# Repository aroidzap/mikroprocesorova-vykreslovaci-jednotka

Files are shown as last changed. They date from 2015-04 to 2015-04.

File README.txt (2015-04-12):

Copyright (c) 2015 Tomáš Pazdiora

Documents, images, code, schematics and boards.

Documents, images, all schematic (.sch) and board (.brd) files are licenced under CC-BY 4.0 (http://creativecommons.org/licenses/by/4.0/legalcode)
All source code is licensed under MIT license. See the file "LICENSE.txt" for full license text.

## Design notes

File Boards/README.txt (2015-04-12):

You can view and export boards using CadSoft's EAGLE Light Edition. (available from: http://www.cadsoftusa.com/download-eagle/freeware/)

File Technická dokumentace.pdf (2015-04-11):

## Technická dokumentace Mikroprocesorová vykreslovací jednotka

2015 | Tomáš Pazdiora

### OBSAH

### 1. HARDWAROVÁ SPECIFIKACE

### 1.1. VSTUPY A VÝSTUPY

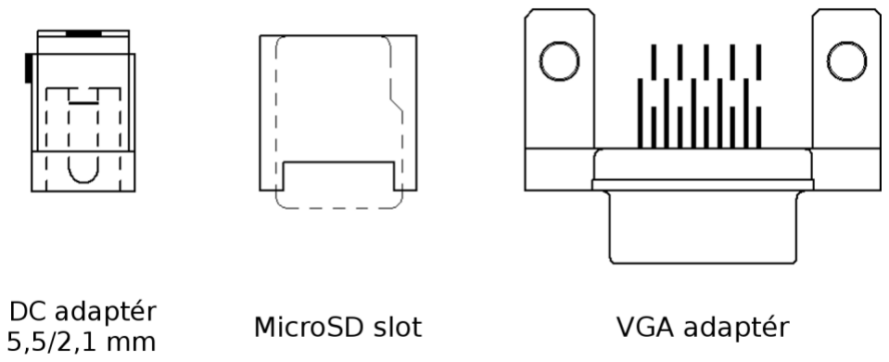
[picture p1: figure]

Obr. 1 – 1: Vstupy a výstupy

### 1.2. ELEKTRICKÉ VLASTNOSTI

Základní parametry

Vstupní napájení | 12 V DC
Maximální spotřeba | 1 W
Typická spotřeba | 0,75 W

Tab. 1 – 1: Základní elektrické parametry

Detailní parametry
Část zařízení | Napájení | Typický proud
ATtiny4313 | 5,0 V | 16 mA
ATmega32 | 5,0 V | 26 mA
RAM modul | 5,0 V | 18 mA
DAC | 5,0 V | 10 mA
SD karta | 3,3 V | 15 mA
| Napájení | Efektivita
Regulátor | 12 V DC | >75 %

Tab. 1 – 2: Detailní elektrické parametry

### 1.3. MIKROPROCESORY

Použité mikroprocesory jsou od firmy Atmel, mají 8bitové jádro AVR, jsou programovatelné skrz rozhraní SPI nebo paralelně.

Jako zobrazovací mikroprocesor je použit mikroprocesor ATtiny4313. Pracuje na frekvenci 20 MHz při napájecím napětí 5 V. Kód zabírá 97.9 % paměti flash. Pokud by bylo potřeba uvolnit místo, je doporučeno odstranit podporu kopírování z jedné paměti do druhé (kód hledejte pod návěštím „copy“).

Vykreslovacím mikroprocesorem je mikroprocesor ATmega32. Pracuje na frekvenci 16MHz při napájecím napětí 5 V. Velikost kódu je závislá na použitých knihovnách.

V následující tabulce jsou vypsána nastavení pojistek obou mikroprocesorů.

Nastavení pojistek

Typ pojistky | ATtiny4313 | ATmega32
Low | 0xFF | 0x3F
High | 0xD9 | 0xD9
Extended | 0xFF | ---

Tab. 1 – 3: Nastavení pojistek mikroprocesorů

### 2. INTERPRETER

Toto zařízení má základní podporu interpretace jednoduchých příkazů. Interpreter načítá příkazy ze souboru „main.txt“ (platí pouze pro aktuální program nahraný v mikroprocesoru). Soubor, ze kterého se načítají příkazy, je zvolen při volání funkce „load_commands“ (tato funkce je obsažena v knihovně „cmd_parser.h“).

Interpreter aktuálně podporuje 14 příkazů. Další příkazy mohou být implementovány úpravou funkce „process_command“ v knihovně „cmd_parser.h“ vykreslovacího mikroprocesoru.

Syntax vychází ze zápisu volání funkcí v jazyce C. Jsou podporovány jednořádkové a víceřádkové komentáře. Syntax vypadá následovně:

// Jednořádkový komentář

/* Víceřádkový komentář
Víceřádkový komentář
Víceřádkový komentář */

// příkaz (argument1, argument2, ... );

// následují příklady zápisu příkazů

bmp_config(0);
clear_color(0,0,0);
draw_bmp ("images/22.bmp"); repeat();

### 2.1. INTERPRETOVANÉ PŘÍKAZY

draw_bmp(file_path);

Vykreslení BMP obrázku.

- file_path – cesta k obrázku včetně uvozovek (např. "slozka/obrazek.bmp")

draw_bmp_from_folder(folder);

Vykreslení jakéhokoliv bmp obrázku z dané složky.

- folder – cesta k dané složce včetně uvozovek (např. "slozka/podslozka")

draw_pal(swap,copy);

Vykreslení palety.

- swap – prohození vykreslovací a zobrazovací paměti po dokončení vykreslování (0 nebo 1)
- copy – postupné vykreslování (0 nebo 1)

draw_hsv_pal(swap,copy);

Vykreslení HSV palety.

- swap – prohození vykreslovací a zobrazovací paměti po dokončení vykreslování (0 nebo 1)
- copy – postupné vykreslování (0 nebo 1)

draw_test(test_number,swap,copy);

Vykreslení funkcí z „draw_test.h“.

- číslo vykreslovací funkce (0 až 3)
- swap – prohození vykreslovací a zobrazovací paměti po dokončení vykreslování (0 nebo 1)
- copy – postupné vykreslování (0 nebo 1)

clear_color(r,g,b);

Vykreslení jedné barvy přes celou obrazovku.

- r – červená složka (0 až 255)
- g – zelená složka (0 až 255)
- b – modrá složka (0 až 255)

delay(seconds);

Pozastavení na daný počet sekund.

bmp_config(enable_scaling);

Je-li nastaveno na „1“, povoluje se škálování bitmapy – dělí se šířka obrázku dvěma. Tímto se částečně kompenzuje nesprávná šířka pixelu zobrazovací jednotky. Pokud je šířka bitmapy upravena předem, nastavujeme na „0“.

processing_config(enable_dithering);

Povolení ditheringu. (0 nebo 1)

set_color_mode(mode);

Nastavení barevného režimu. (RGB nebo BW, bez uvozovek)

swap_buffers();

Prohození vykreslovací a zobrazovací paměti.

copy_buffers(direction);

Kopírování z jedné paměti do druhé.

„direction“ (směr):

- 1 – z vykreslovací paměti do zobrazovací
- 0 – ze zobrazovací paměti do vykreslovací

repeat_from_here();

Označení pozice, odkud se má kód opakovat při zavolání funkce „repeat“.

repeat();

Opakovat.

### 3. KNIHOVNY VYKRESLOVACÍHO

### MIKROPROCESORU

Některé knihovny obsahují globální proměnné pro své vnitřní výpočty. Většina těchto proměnných tu není uvedena.

## 3.1. BMP.h

unsigned char bmp_2to1_scaling;

Je-li nastaveno na „1“, povoluje se škálování bitmapy – dělí se šířka obrázku dvěma. Tímto se částečně kompenzuje nesprávná šířka pixelu zobrazovací jednotky. Pokud je šířka bitmapy upravena předem, nastavujeme bmp_2to1_scaling na „0“.

int BMP_decode_start();

Dekóduje hlavičku bitmapy. Podporuje pouze bitmapy s 24bitovou barevnou hloubkou a pouze bitmapy se standardní hlavičkou. Pokud navrací „1“, jde o nepodporovanou bitmapu, je-li vše v pořádku, navrací „0“.

vec3 BMP_next_pixel();

Navrací další pixel.

void BMP_next_y();

Posouvá se na další Y souřadnici. Souřadnice jsou čteny zespod obrázku nahoru. (adresy od „výška - 1“ do „0“)

void BMP_center_y(int input_y);

Centrování bitmapy. Volá se před vykreslením pixelu, jednou na každé lince.

void BMP_center_x(int input_x);

Centrování bitmapy. Volá se před vykreslením pixelu.

void BMP_render(unsigned long starting_cluster);

Vykreslení bitmapy.

- starting_cluster – cluster BMP souboru, který chceme vykreslit.

## 3.2. cmd_parser.h

void process_command(char *cmd, char *arg);

Zpracuje příkaz.

- cmd – příkaz (string)
- arg – argument (string)

void load_commands(char *file_path);

Načítá soubor s příkazy určenými k interpretaci.

- file_path – cesta k souboru (např. „slozka/soubor.txt“)

unsigned char cmd_compare(char* cmd, char* text);

Porovnává příkaz (string) s textem.

- cmd – příkaz (string)
- text – text (string)

int get_argument_i(char *arg, unsigned char arg_number);

Vytahuje z argumentu (string) argument s číslem „arg_number“ a navrací jej.

- arg – argument (string)
- arg_number – číslo požadovaného argumentu

void get_argument_str(char *arg);

Vytahuje string z argumentu (string) a navrací jej zpět do argumentu.

- arg – argument (string)

void get_argument_enum(char *arg);

Vytahuje enum z argumentu (string) a navrací jej zpět do argumentu.

- arg – argument (string)

## 3.3. color_process.h

unsigned char dither_enable;

Povolení ditheringu (0, 1).

PROGMEM unsigned const char threshold_matrix3b[4][4];

Prahová mapa 4x4 pro ordered dithering, pronásobená velikostí kvantizační hladiny o velikosti 32.

PROGMEM unsigned const char threshold_matrix2b[4][4];

Prahová mapa 4x4 pro ordered dithering, pronásobená velikostí kvantizační hladiny o velikosti 64.

vec3 dither_rgb(vec3 pixel, int x, int y);

Převede pomocí ordered ditheringu pixel s 24bitovou hloubkou na pixel s 8bitovou hloubkou (kompatibilní s formátem BBGGGRRR).

vec3 rgb_to_bw(vec3 pixel24b);

Pomocí funkce relativního jasu převede barevný pixel na černobílý.

unsigned char rgb_to_bw_value(vec3 pixel24b);

Pomocí funkce relativního jasu převede barevný pixel s 24bitovou hloubkou na hodnotu o 256 odstínech šedi.

vec3 truncate_rgb(vec3 pixel);

Oseká pixel s 24bitovou hloubkou na pixel s 8bitovou hloubkou (kompatibilní s formátem BBGGGRRR).

unsigned char compose_rgb8(vec3 pixel);

Navrací formát BBGGGRRR.

- pixel – pixel s 8bitovou hloubkou (kompatibilní s formátem BBGGGRRR)

unsigned char compose_rgb24(vec3 pixel);

Oseká pixel s 24bitovou hloubkou na pixel s 8bitovou hloubkou (kompatibilní s formátem BBGGGRRR) a navrací formát BBGGGRRR.

- pixel - pixel s 24bitovou hloubkou vec3 decompose_rgb8(unsigned char bbgggrrr);

Rozložení formátu BBGGGRRR na tři složky.

- bbgggrrr – vstupní hodnota formátu BBGGGRRR

## 3.4. commands.h

Obsahuje seznam příkazů pro funkci „driver_command“, která je deklarovaná v knihovně „UART.h“.

### 3.4.1. Žádosti

COPY_REQUEST_CMD(n)

Kopírování n-té čtveřice linek. „n“ je v rozmezí od 0 do 119.

VIDEO_DISABLE

Zakázání zobrazování obrazu.

VIDEO_ENABLE

Povolení zobrazování obrazu.

SWAP_STATE_CMD(state)

Prohodit paměti do konkrétního stavu. „state“ je buď „0“ nebo „1“.

COPY_DIR_CMD(dir)

Směr kopírování. „dir“ může být copy_to_video (kopírování z vykreslovací paměti do zobrazovací) nebo copy_to_data (kopírování ze zobrazovací paměti do vykreslovací).

SWAP_REQUEST_CMD

Prohození pamětí.

DRIVER_READY_REQ_CMD

Zjišťuje, je-li zobrazovací mikroprocesor připraven.

### 3.4.2. Odpovědi

DRIVER_DONE_CMD

Příkaz byl dokončen v pořádku.

DRIVER_READY_RESP_CMD

Zobrazovací mikroprocesor je připraven.

DRIVER_TRANSMIT_ERROR

Chyba v přenosu.

DRIVER_ILLEGAL_CMD

Nepodporovaný příkaz.

## 3.5. draw_test.h

unsigned char draw0(int input_x,int input_y);

Vykreslovací funkce „srdce“.

unsigned char draw1(int input_x,int input_y);

Vykreslovací funkce „základní fraktál“.

unsigned char draw2(int input_x,int input_y);

Vykreslovací funkce.

unsigned char draw3(int input_x,int input_y);

Vykreslovací funkce.

## 3.6. drawing.h

unsigned long time;

Tato hodnota je určená pro vlastní výpočty. Při startu programu je inicializována na „0“. Funkce „render“ navyšuje tuto hodnotu o 1.

void clear_color(unsigned char color, unsigned char swap);

Vykreslení jedné barvy do paměti.

- color – barva ve formátu BBGGGRRR
- swap – prohození bufferů po dokončení vykreslování barvy (0, 1)

void render_loading_bar(unsigned int input_y);

Vykreslení loading baru.

- input_y – aktuální adresa y

void render( unsigned char (*compute_pixel)(int,int), unsigned char swap,
unsigned char copy );
- (*compute_pixel)(int,int) – vstupní vykreslovací funkce (např. draw_pal)
- swap – prohození bufferů po dokončení vykreslování barvy (0, 1)
- copy – postupné vykreslování

unsigned char draw_pal(int input_x,int input_y);

Vykreslovací funkce pro vykreslení palety.

unsigned char draw_hsv_pal(int input_x,int input_y);

Vykreslovací funkce pro vykreslení HSV palety.

void delay(unsigned int seconds);

Pozastavení programu.

- seconds – doba pozastavení v sekundách

## 3.7. FAT.h

void FAT_init();

Inicializace FATu.

unsigned long cluster_to_lba(unsigned long cluster);

Převádí cluster na adresu LBA a tu navrací.

int FAT_get_new_cluster();

Posune čtení se na následující cluster. Pokud je aktuální cluster poslední v řetězci clusterů, navrací „1“, jinak „0“.

void FAT_read_start(unsigned long cluster);

Započne čtení na daném clusteru.

unsigned char FAT_read_next();

Navrací další 8bitové nezáporné celé číslo.

unsigned int FAT_next_ui();

Navrací další 16bitové nezáporné celé číslo.

unsigned long FAT_next_ul();

Navrací další 32bitové nezáporné celé číslo.

void FAT_read_skip(int bytes_to_skip);

Přeskočení několika bytů.

- bytes_to_skip – počet bytů k přeskočení

unsigned long FAT_find_entry_cluster( char *name ,
unsigned char is_directory);

Navrací cluster hledaného souborového zápisu. Není-li zápis nalezen, vrací „0“.

- name – jméno hledaného souborového zápisu (např. „soubor.txt“)
- is_directory – jedná se o složku (1, 0)

void FAT_open_directory( char *directory_path, unsigned char name_is_file_path );

Otevírá složku.

- directory_path – cesta ke složce (např. „slozka/podslozka1/podslozka2“)
- name_is_file_path – cesta ke složce obsahuje na konci zápisu soubor (1, 0)

unsigned long FAT_find_file_cluster(char *file_path);

Navrací cluster hledaného souboru.

- file_path – cesta k souboru (např. „slozka/podslozka/soubor.txt“)

unsigned long FAT_file_by_extension_cluster(
char* directory_name, char *extension);

Otevírá soubor s danou příponou (přípona není citlivá na velikost písmen). Při vícenásobném volání otevírá soubory postupně za sebou.

- directory_name – cesta ke složce (např. „slozka/podslozka1/podslozka2“)
- extension – přípona souborů (pouze třímístné, např. „bmp“, „txt“)

## 3.8. RAM.h

unsigned char const PROGMEM translate_x_data[33];

Konstantní data využitá pro přeložení standartního adresování „od 0 do n“ na „posloupnost rychlého sekvenčního čtení“.

void set_Y(unsigned int _value);

Nastavení adresy Y (standardní adresování „od 0 do n“).

- _value – vstupní hodnota adresy Y

void set_X(unsigned char _value);

Nastavení adresy X (standardní adresování „od 0 do n“).

- _value – vstupní hodnota adresy X

unsigned char translate_x(unsigned char x);

Přeložení adresy standardního adresování „od 0 do n“ na adresu „posloupnosti rychlého sekvenčního čtení“. Tato funkce je používána interně.

void inc_X();

Zvětšení hodnoty adresy X o 1. Tato funkce je optimalizována pro rychlost. Pokud je to možné, je doporučeno používat tuto funkci místo funkce set_X.

void reset_X();

Vynuluje adresu X. Tato funkce je optimalizována pro rychlost. Pokud je to možné, je doporučeno používat tuto funkci místo funkce set_X.

unsigned char RAM_read();

Vrací hodnotu z externí RAM, z aktuálně nastavené adresy.

void RAM_write(unsigned char data);

Zapisuje do externí RAM na aktuálně nastavenou adresu.

- data – vstupní data

## 3.9. SD.h

void SD_set_speed(unsigned char speed);

Nastavení rychlosti přenosu SD karty.

Hodnota proměnné „speed“ | Rychlost přenosu [kbps]
0 | 125
1 | 250
2 | 500
3 | 1000
4 | 2000
5 | 4000
6 | 8000

Tab. 3 – 1: Funkce „SD_set_speed“ – popis parametru „speed“

int SD_init_basic();

Základní inicializace SD karty.

int SD_init();

Inicializace SD karty. Aktuálně wrapper pro SD_init_basic.

unsigned int crc16(unsigned int old_crc, unsigned char data);

Jde o CRC-16-CCITT. Navrací novou hodnotu CRC.

- old_crc – stará hodnota CRC
- data – vstupní byte do CRC výpočtu

unsigned char crc7(unsigned char *message);

Navrací poslední byte SD příkazu (CRC posunuté o bit doleva a stop bit).

- message – SD příkaz, pro který se počítá CRC-7

void SD_command(unsigned char cmd, unsigned long arg);

Posílá SD příkaz.

- cmd – číslo příkazu
- arg - argument

unsigned char SD_command_R1(unsigned char cmd,
unsigned long arg, unsigned char expected_response);

Posílá SD příkaz a čeká na odpověď R1.

- cmd – číslo příkazu
- arg – argument
- expected_response – požadovaná odpověď

void SD_read_start(unsigned long address, unsigned long blocks);

Započne čtení.

- address – adresa, na které se má začít číst
- blocks – počet bloků, které se budou číst

void SD_read_stop();

Zastavení přenosu dat. Není nutné používat, volá se automaticky dle potřeby.

unsigned char SD_read_next();

Navrací další 8bitové nezáporné celé číslo.

unsigned int SD_next_ui();

Navrací další 16bitové nezáporné celé číslo.

unsigned long SD_next_ul();

Navrací další 32bitové nezáporné celé číslo.

void SD_read_skip(int bytes_to_skip);

Přeskočení několika bytů.

- bytes_to_skip – počet bytů k přeskočení

## 3.10.settings.h

Obsahuje softwarová a hardwarová nastavení. Jejich funkce je dle názvu zřejmá, proto zde nejsou nastavitelné parametry popsány.

void set_color_mode(unsigned char color_mode);

Nastavuje barevný režim.

- color_mode - typ barevného režimu (RGB, BW).

unsigned char get_color_mode();

Vrací aktuálně nastavený barevný režim (RGB, BW).

unsigned char informative_color();

Vrací barvu pro využití k informativním účelům (načítání, chyby, …) ve formátu BBGGGRRR. Vrácená barva závisí na nastaveném barevném režimu.

## 3.11.SPI.h

void SPI_init();

Inicializace SPI.

void SPI_set_speed(int speed);

Nastavení rychlosti SPI.

Hodnota proměnné „speed“ | Rychlost přenosu [kbps]
0 | 125
1 | 250
2 | 500
3 | 1000
4 | 2000
5 | 4000
6 | 8000

Tab. 3 – 2: Funkce „SPI_set_speed“ – popis parametru „speed“

unsigned char SPI_transfer(unsigned char data_in);

SPI přenos. Navrací příchozí data.

- data_in – data pro odeslání

## 3.12.touch_button.h

Tato knihovna není hardwarově podporována.

## 3.13.UART.h

void UART_init();

Inicializace UARTu

void driver_init();

Vyčkání na inicializaci zobrazovacího mikroprocesoru.

void driver_command(unsigned char command);

Poslání příkazu zobrazovacímu mikroprocesoru. Všechny možné příkazy jsou sepsány v souboru „commands.h“.

- command – příkaz, který se pošle

## 3.14.vecmath.h

typedef struct
{
unsigned char r;
unsigned char g;
unsigned char b;
}vec3;

Definuje typ vec3 – vektor o třech 8bitových složkách.

vec3 add(vec3 a, vec3 b);

Součet dvou vektorů „a“ a „b“.

vec3 add_value(vec3 a, unsigned char v);

Součet vektoru „a“ a hodnoty „v“.

vec3 mul_value(vec3 a, float v);

Násobení vektoru „a“ hodnotou „v“.

vec3 average(vec3 a, vec3 b);

Zprůměrování vektorů „a“ a „b“.

vec3 mix(vec3 a, vec3 b, unsigned char alpha);

Smíchání vektorů „a“ a „b“ v poměru daném hodnotou „alpha“:

Hodnota „alpha“ | Vektor „a“ | Vektor „b“
0 | 100 % | 0 %
127 | 50 % | 50 %
255 | 0 % | 100 %

Tab. 3 – 3: Funkce „mix“ – popis parametru „alpha“

unsigned char clamp(int x);

Osekání hodnoty „x“ do rozmezí od 0 do 255.

float absolute(float x);

Navrací absolutní hodnotu „x“.

### SEZNAM OBRÁZKŮ, GRAFŮ A

### TABULEK

Obr. 1 – 1: Vstupy a výstupy

Tab. 1 – 1: Základní elektrické parametry
Tab. 1 – 2: Detailní elektrické parametry
Tab. 1 – 3: Nastavení pojistek mikroprocesorů
Tab. 3 – 1: Funkce „SD_set_speed“ – popis parametru „speed“ Tab. 3 – 2: Funkce „SPI_set_speed“ – popis parametru „speed“ Tab. 3 – 3: Funkce „mix“ – popis parametru „alpha“

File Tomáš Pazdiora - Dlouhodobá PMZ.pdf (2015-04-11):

## Vyšší odborná škola a Střední průmyslová škola

elektrotechnická Olomouc,

## Božetěchova 3

## PRAKTICKÁ ZKOUŠKA Z ODBORNÝCH PŘEDMĚTŮ Mikroprocesorová vykreslovací jednotka

2015 | Tomáš Pazdiora

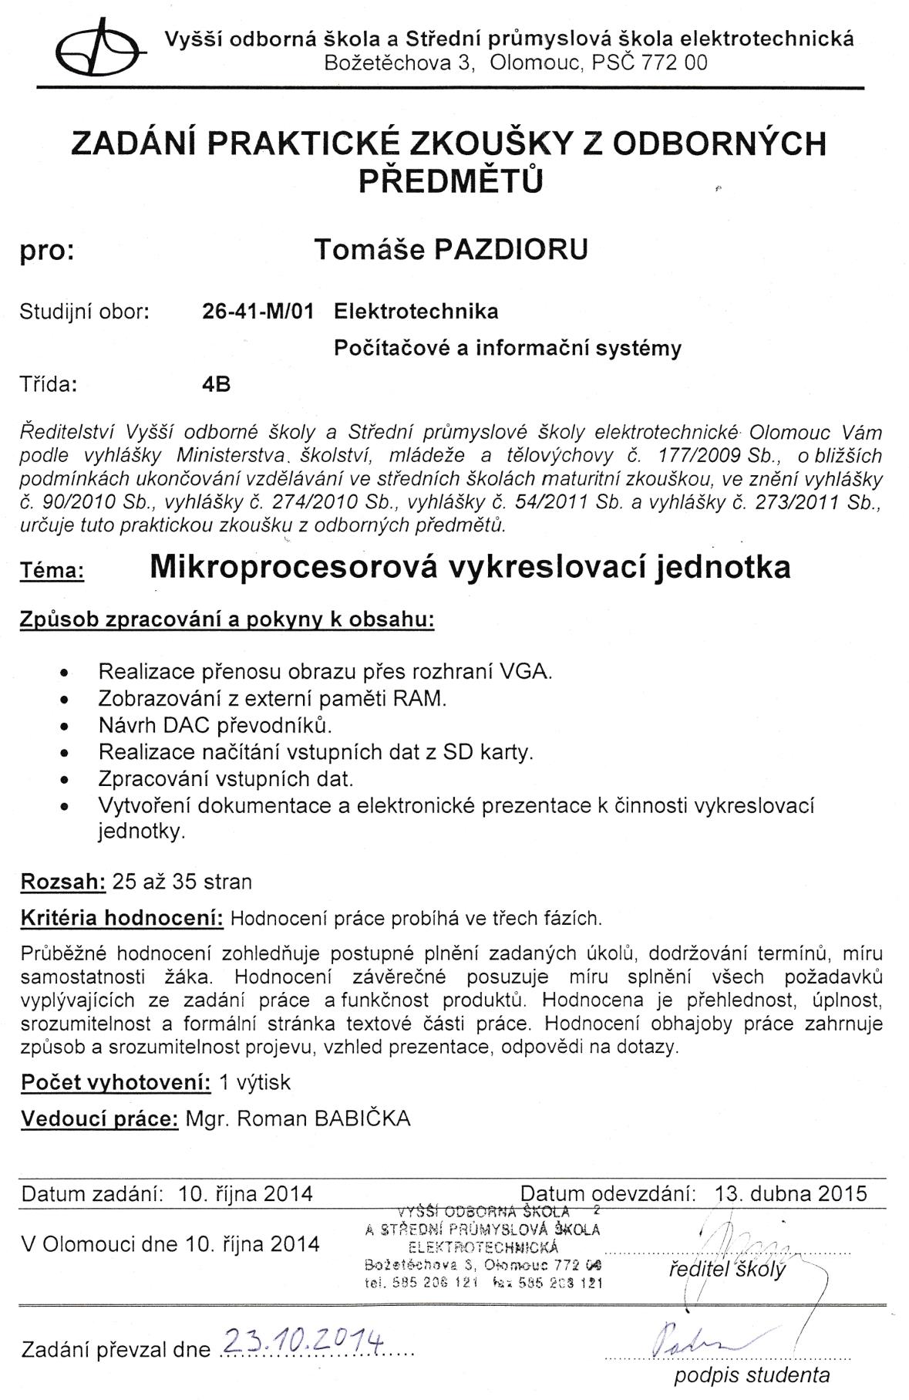
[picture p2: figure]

Prohlašuji, že jsem praktickou zkoušku vypracoval samostatně a všechny prameny jsem uvedl v seznamu použité literatury.

Tomáš Pazdiora

Chtěl bych vyslovit poděkování panu Mgr. Romanovi Babičkovi za odborné konzultace a poskytnuté informace.

Tomáš Pazdiora

Prohlašuji, že nemám námitek proti půjčování nebo zveřejňování mé práce nebo její části se souhlasem školy.

Tomáš Pazdiora

Praktická zkouška z odborných předmětů – Mikroprocesorová vykreslovací jednotka

### OBSAH

### ÚVOD

Zadáním práce bylo navrhnout zařízení, které je schopné zobrazovat obraz na monitoru. Při návrhu jsem se zaměřil převážně na to, aby byly komponenty pro výrobu dostupné a celková cena zařízení byla přijatelná.

Mým cílem nebyla snaha vytvořit zařízení pro koncové uživatele, ale zařízení, které by sloužilo jako studijní materiál a jeho části by mohly být kýmkoliv libovolně využívány pro další projekty (viz Dodatek). Vzhledem k tomu, že se tato práce zabývá širokým spektrem různých problematik, myslím, že může být dobrým zdrojem informací téměř pro každého, který se pohybuje na poli elektroniky a mikroprocesorů.

Kapitoly jsou řazeny tak, aby odpovídaly postupnému řešení dílčích částí při vývoji. V první části je rozebrán hardware zařízení a v druhé je popsán jeho software.

### 1. STRUČNÝ POPIS ZAŘÍZENÍ

Mikroprocesorová vykreslovací jednotka je zařízení určené k zobrazování obrazu na monitoru. Tento obraz je buďto načtený z externí paměti, nebo vygenerovaný vykreslovacím mikroprocesorem.

Vykreslovací jednotka není brána jako finální produkt, ale je určena k modifikaci a zkoušení jejích možností.

Obsahuje dva mikroprocesory, mezi které jsou rozděleny potřebné úkony, SD kartu, která poskytuje vstupní data, modul s paměťmi, do kterých se ukládá obraz a převodník, který převádí digitální výstup na analogový signál.

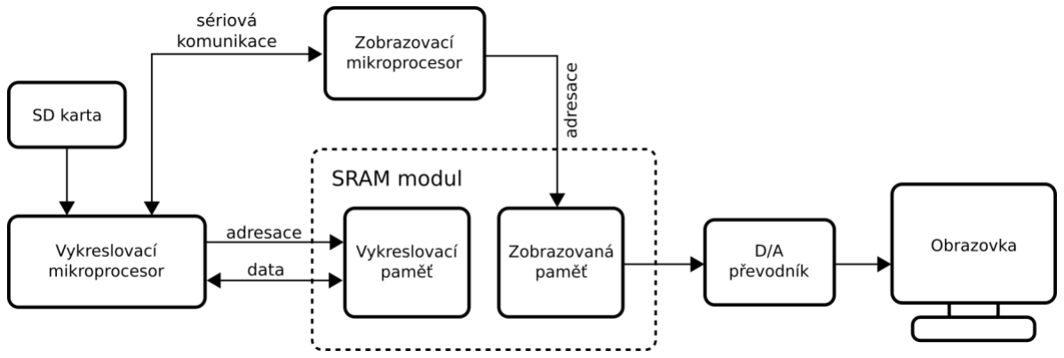
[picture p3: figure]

Obr. 1 – 1: Zjednodušené principiální blokové schéma celého zařízení

### 2. POUŽITÉ MIKROPROCESORY

Pro tuto práci jsem chtěl použít mikroprocesory, které jsou v ČR snadno dostupné

a za rozumnou cenu.

Bylo možné využít mikroprocesory od firem Microchip, NXP a Atmel. Od těchto tří výrobců můžeme získat mikroprocesory s různými architekturami. Od všech tří výrobců je v ČR dostupná klasická architektura 8051. Firmy Microchip a Atmel v ČR

dále nabízí mikroprocesory s 8bitovou architekturou RISC. Poslední dostupnou architekturou v ČR je architektura ARM (konkrétně Cortex-M0) od výrobce NXP.

Tito výrobci dále nabízí 32bitové mikroprocesory s architekturou RISC, nebo ARM architekturu vyšších tříd. Tyto produkty ale dnes téměř není možné v kamenných obchodech ČR sehnat.

Nakonec jsem se rozhodl pro 8bitové mikroprocesory architektury RISC od firmy Atmel, jelikož s nimi mám již zkušenosti.

Při rozhodování byla velkým soupeřem architektura ARM. Ta je pro tuto práci přímo ideální. Mikroprocesory této architektury mají větší velikosti pamětí a mohou běžet na vyšších frekvencích. Vyšší řady architektury ARM se dnes používají v různých mobilních zařízeních a jsou velmi populární. Pro tuto architekturu jsem se ale nerozhodl z důvodu nízké dostupnosti v ČR.

2.1.MIKROPROCESORY AVR

AVR je označení upravené Harvardské RISC architektury mikroprocesorů firmy Atmel. Označení AVR zahrnuje jak 32bitové, tak 8bitové mikroprocesory. 8bitové se dále dělí do tří tříd.

První třídou jsou mikroprocesory AVR XMEGA, z celé řady těchto 8bitových mikroprocesorů jsou nejvýkonnější. Dosahují rychlostí až 32 MHz. Nejsou ovšem dostupné v ČR.

Další třídou jsou mikroprocesory megaAVR, spolu s architekturou tinyAVR jsou jedny z nejdostupnějších mikroprocesorů v ČR. Jejich výhodou může být velké

množství pinů (28 – 100), další výhodou je hardwarová implementace hojného počtu periferních obvodů jako komunikační protokoly SPI, TWI (I²C), UART/USART, A/D

převodníky, analogové komparátory, čítače, časovače a další. Dosahují frekvencí až 20 MHz.

Poslední třídou jsou již výše zmíněné mikroprocesory tinyAVR. Tyto mikroprocesory jsou navrhovány s důrazem na jejich cenu a velikost. Mají menší velikosti pamětí než mikroprocesory megaAVR , mají integrovány jen některé periferní obvody a mívají menší počet pinů (6 – 32). S rychlostí jsou na tom stejně tak dobře jako třída megaAVR. Dosahují frekvencí až 20 MHz.

Tyto tři třídy mikroprocesorů mají maximální výkon 1.0 MIPS/MHz (MIPS – milion instrukcí za sekundu). Tento výkon platí pro většinu základních instrukcí. Některé instrukce ale trvají více strojových cyklů.

2.2.ZOBRAZOVACÍ MIKROPROCESOR

Jako zobrazovací mikroprocesor byl zvolen mikroprocesor ATtiny4313 řady tinyAVR. Je nástupcem mikroprocesoru ATtiny2313. Tyto dva mikroprocesory jsou kompatibilní. Rozdílem je velikost pamětí, ta je u ATtiny4313 dvojnásobná (flash, SRAM i EEPROM). Mezi jeho hlavní parametry potřebné v této práci patří:

- frekvence až 20 Mhz při napětí 4,5 – 5,5 V,
- 4 Kb programové paměti flash,
- 256 bytů statické RAM,
- hardwarová podpora sériové komunikace pomocí UART/USART,
- jeden 8bitový a jeden 16bitový časovač/čítač,
- 18 programovatelných vstupně výstupních pinů.

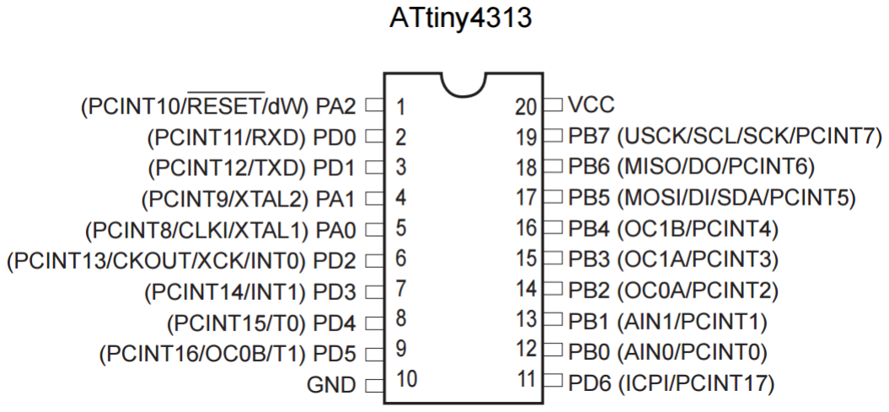
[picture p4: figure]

Obr. 2 – 1: ATtiny4313 – rozložení pinů

2.3.VYKRESLOVACÍ MIKROPROCESOR

Vykreslovacím mikroprocesorem je mikroprocesor ATmega32 řady megaAVR. Byl zvolen kvůli ulehčení a urychlení návrhu hardwaru a softwaru, vzhledem k jeho poměrně velké paměti a velkému počtu vstupně výstupních pinů. Mohl být nahrazen jiným, levnějším mikroprocesorem, jako například ATmega8. To by ovšem mohlo zkomplikovat a prodloužit vývoj zařízení. Mezi hlavní parametry mikroprocesoru ATmega32 potřebné v této práci patří:

- frekvence až 16 Mhz při napětí 4,5 – 5,5 V,
- 32 Kb programové paměti flash,
- 2 Kb statické RAM,
- hardwarová podpora protokolů UART/USART a SPI,
- 32 programovatelných vstupně výstupních pinů.

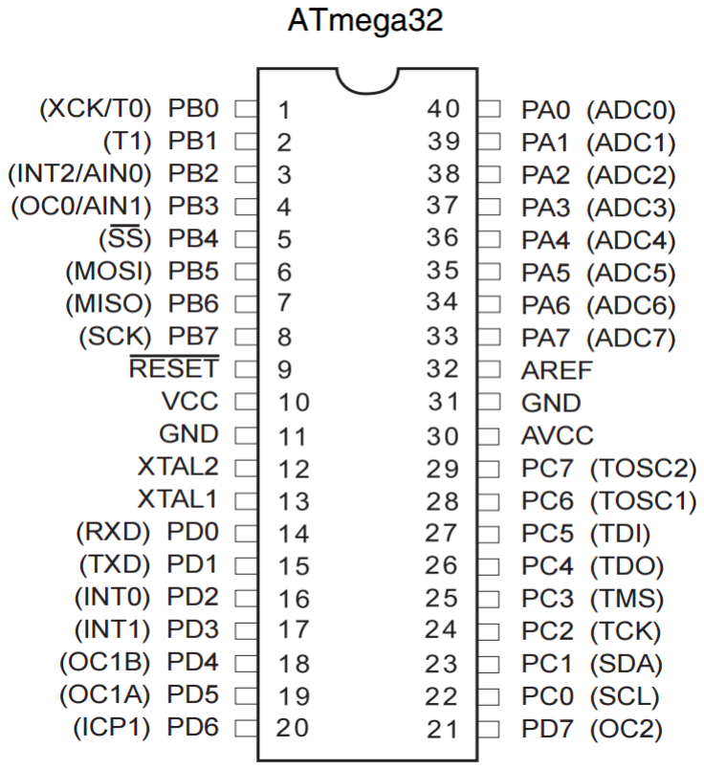
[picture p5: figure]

Obr. 2 – 2: ATmega32 – rozložení pinů

## 3. ROZHRANÍ VGA

VGA (Video Graphics Array) standard byl vydán v roce 1987 společností IBM. Jde o standard popisující velikost video paměti, hloubku barev, obnovovací frekvenci, rozlišení a další parametry. VGA standard definuje jak stranu generující analogový signál, tak stranu přijímající analogový signál. Vzhledem k tomu, že jsou tyto dvě strany odděleny právě analogovým signálem, není nutné dodržet tento standard kompletně. Pro zobrazení obrazu na přijímací straně stačí dodržet pouze časování, velikost napětí analogového signálu a impedanci.

VGA obsahuje signály pro barvu, synchronizaci a identifikaci monitoru. Barva se skládá ze tří signálů: červené, zelené a modré barvy. Každý signál barvy má impedanci 75 Ω a maximální rozkmit napětí 0,7 V. Všechny ostatní signály mají napětí na TTL úrovni (5 V). Synchronizační signály se dělí na horizontální a vertikální. Jejich polarita je dána použitým režimem zobrazení. V této práci je použit režim 640x480 pixelů při 60 snímcích za sekundu. V tomto režimu mají oba synchronizační signály negativní polaritu (tzn. 0 V – synchronizační puls, jinak 5 V). Identifikační signály jsou dle VGA standardu signály ID0 – ID3, které jsou dnes již nahrazeny signály pro sériovou komunikaci pomocí protokolu I²C (standard VESA E-DDC).

Běžným konektorem je DE-15, což je třířadý, 15pinový D-Sub, také známý jako Cannon, podle firmy která jej zavedla (ITT-Cannon).

Obr. 3 – 1: VGA konektor

Pin | Popis
1 | Červená
2 | Zelená
3 | Modrá
4 | ID2 / Rezervován (E-DCC)
5 | Zem
6 | Červená – zem
7 | Zelená – zem
8 | Modrá – zem
9 | Bez pinu / +5V z PC (E-DCC)
10 | Synchronizace – zem
11 | ID0 / Rezervován (E-DCC)
12 | ID1 / Sériová data (E-DCC)
13 | Horizontální synchronizace
14 | Vertikální synchronizace
15 | ID3 / Hodinový signál (E-DCC)

Tab. 3 – 1: Rozložení pinů VGA konektoru

## 3.1.ČASOVÁNÍ

Průběhy signálů jsou rozděleny do několika částí. Tyto části nám říkají, kdy se má zobrazovat video a kdy se mají sepínat synchronizační signály.

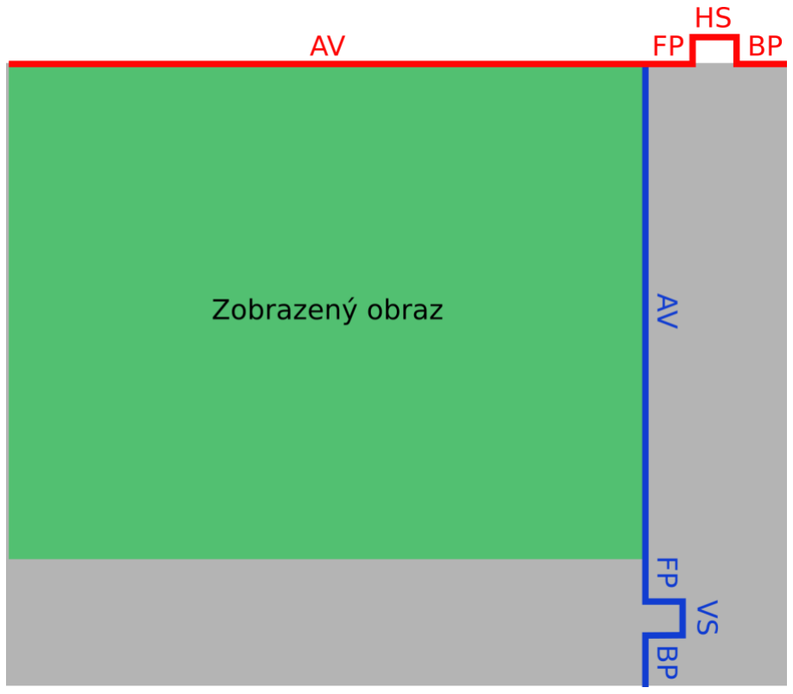
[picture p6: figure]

Obr. 3 – 2: VGA synchronizační signály

Zkratka | Název | Popis
AV | Active video | Část, ve které je na RGB kanály přiveden signál. V ostatních částech musí být na všech kanálech nulová intenzita.
FP | Front porch | Časový interval před synchronizačním pulsem
HS/VS | Sync pulse | Synchronizační puls. Vertikální i horizontální pulsy jsou sepínány nezávisle na sobě. (tzn. horizontální puls je na každé lince, i v průběhu vertikálního pulsu)
BP | Back porch | Časový interval po synchronizačním pulsu

Tab. 3 – 2: Vysvětlení zkratek částí synchronizačních signálů

VGA signál může mít několik různých režimů. Každý režim se liší rozlišením obrazu, obnovovací frekvencí (počet snímků za sekundu) a jsou pro ně definovány důležité parametry: frekvence pixelu, horizontální frekvence (frekvence řádku), polarity synchronizačních signálů a doby trvání jejich částí.

V této práci je použit režim 640x480 při 60Hz. Zde nastává problém, jelikož tento režim definuje frekvenci pixelu na 25.175 MHz a maximální frekvence použitého mikroprocesoru generujícího synchronizační signály je 20 MHz. Z toho vyplývá, že nebude možné generovat správnou velikost pixelu, pixely budou roztáhlé a nastane zde jev zvaný overscan. Neznamená to ještě ovšem, že nebude možné obraz správně synchronizovat. Časy všech částí synchronizačních impulsů se dají s rozumnou

odchylkou přepočítat na frekvenci pixelu 20MHz. Většina zobrazovacích zařízení by si měla s touto odchylkou poradit. Novější zařízení jsou ale na přesnost signálu náročnější.

### 3.1.1.OVERSCAN

Jev zvaný overscan nastává při situaci, když se mapuje obraz s určitým rozlišením na odlišné rozlišení monitoru a podíl těchto rozlišení není celočíselný. Na monitoru je poté značně viditelná mřížka. V této práci je overscan pouze horizontální, a proto jsou vidět jen vertikální pruhy (viz Obr. 3 – 5).

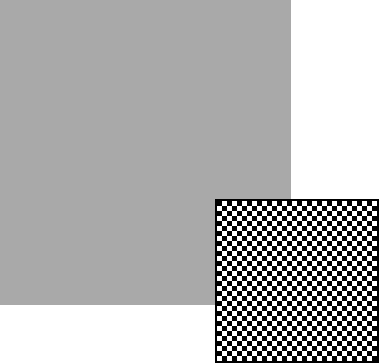
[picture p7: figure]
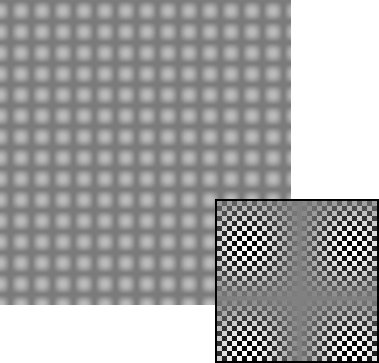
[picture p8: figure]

Obr. 3 – 3: Mapování pixelu 1:1 | Obr. 3 – 4: Overscan 10%

Obr. 3 – 5: Overscan vykreslovací jednotky

3.1.2.PŘEPOČET ČASOVÁNÍ

Pro správnou synchronizaci je důležité dodržet hodnoty časování. Všechny hodnoty vycházejí z času trvání jednoho pixelu. Při snížení frekvence pixelu se snažíme najít takový počet pixelů v určitých částech synchronizace, aby se doby trvání těchto částí co nejméně lišily od originálních hodnot. V následujících tabulkách jsou originální hodnoty, přepočtené hodnoty a jejich odchylky.

Hodnoty časování pro režim 640x480 při 60Hz

Vertikální frekvence | 59,94047619 Hz
Horizontální frekvence | 31,46875 kHz
Frekvence pixelu | 25,175 MHz
Linková část | Pixely | Čas [µs]
Active video | 640 | 25,42204568
Front porch | 16 | 0,635551142
Sync pulse | 96 | 3,813306852
Back porch | 48 | 1,906653426
Celá linka | 800 | 31,7775571
Snímková část | Linky | Čas [ms]
Active video | 480 | 15,25322741
Front porch | 10 | 0,317775571
Sync pulse | 2 | 0,063555114
Back porch | 33 | 1,048659384
Celý snímek | 525 | 16,68321748

Tab. 3 – 3: Hodnoty časování pro režim 640x480 při 60Hz

Hodnoty časování pro nižší frekvenci pixelu

Vertikální frekvence | 59,99250094 Hz
Horizontální frekvence | 31,49606299 kHz
Frekvence pixelu | 20 MHz
Linková část | Pixely | Čas [µs]
Active video | 508 | 25,4
Front porch | 13 | 0,65
Sync pulse | 76 | 3,8
Back porch | 38 | 1,9
Celá linka | 635 | 31,75
Snímková část | Linky | Čas [ms]
Active video | 480 | 15,24
Front porch | 10 | 0,3175
Sync pulse | 2 | 0,0635
Back porch | 33 | 1,04775
Celý snímek | 525 | 16,66875

Tab. 3 – 4: Hodnoty časování pro nižší frekvenci pixelu

Odchylky v hodnotách časování

| Procentní odchylka | Absolutní odchylka
Vertikální frekvence | +0,0868 % | +0,052024747 Hz
Horizontální frekvence | +0,0868 % | +0,027312992 kHz
Frekvence pixelu | -20,5561 % | -5,175 MHz
Linková část | Procentní odchylka | Absolutní odchylka [µs]
Active video | -0,0867 % | -0,02204568
Front porch | +2,2734 % | +0,014448858
Sync pulse | -0,3490 % | -0,013306852
Back porch | -0,3490 % | -0,006653426
Celá linka | -0,0867 % | -0,0275571
Snímková část | Procentní odchylka | Absolutní odchylka [ms]
Active video | -0,0867 % | -0,013227408
Front porch | -0,0867 % | -0,000275571
Sync pulse | -0,0867 % | -5,51142·10⁻⁵
Back porch | -0,0867 % | -0,000909384
Celý snímek | -0,0867 % | -0,014467478

Tab. 3 – 5: Odchylky v hodnotách časování

### 4. EXTERNÍ PAMĚŤ RAM

RAM (Random Access Memory) je rychlá paměť s libovolným přístupem. Slouží k dočasnému ukládání dat. Jedná se o paměť volatilní, neboli nestálou – pro uchování dat musí být napájena.

V této práci je externí RAM využita pro ukládání obrazových dat, která se nevejdou do operační paměti použitých mikroprocesorů.

4.1.STATICKÁ A DYNAMICKÁ RAM

V dnešní době se ujaly dva typy RAM – dynamické, které jsou velmi populární díky své ceně a relativně dobrým vlastnostem, a statické, které jsou znatelně dražší, zato ale rychlejší, nepotřebují podpůrné obvody pro uchování informace a jednodušeji se ovládají.

Většina dnešních dynamických pamětí má podpůrné obvody integrované v sobě. Tyto paměti se ovládají pomocí příkazů. Nejdříve se musí inicializovat dle dané sekvence a až poté mohou přijímat ostatní příkazy pro čtení a zápis

Prvotním plánem bylo využít pro tuto práci paměť dynamickou, konkrétně synchronní dynamickou RAM (SDRAM) a její dávkový režim (Burst mode). Tento režim funguje tak, že se paměti pošle příkaz pro zapnutí dávkového režimu a paměť automaticky při každém taktu vydává data sekvenčně za sebou a není potřeba poskytovat adresu dat. Tato paměť mohla odlehčit složitosti hardwaru a softwaru, bohužel se mi ji ale nepodařilo zprovoznit, kvůli chybějící technické dokumentaci a pouhému odhadování funkce a rozložení pinů z podobných (pravděpodobně kompatibilních) dokumentací.

Použil jsem tedy paměť statickou. Oproti dynamické paměti nepodporuje žádné příkazy, ale jen jednoduchý zápis a čtení. Pro rychlé sekvenční čtení bylo potřeba implementovat hardwarové řešení.

4.2.DOUBLE BUFFERING

Double buffering je v počítačové grafice technika využívající dvou pamětí pro vykreslování a zobrazování obrazu. Celkové vykreslování se tak značně urychlí a zabrání se tím trhání obrazu a případným artefaktům. Je to metoda používaná dodnes a pravděpodobně se bude používat ještě dlouho, protože nejsou závažné důvody, proč by se měla nahrazovat.

V této práci bylo použití dvou nezávislých pamětí jediné rozumné řešení, protože rychlosti mikroprocesorů nejsou příliš vysoké a zobrazování obsahu paměti na monitor zabírá přes 80 % celkového času práce s pamětí.

4.2.1.KLASICKÝ DOUBLE BUFFERING

Klasický double buffering je založen na tom, že jedna paměť je primární, z té se obraz zobrazuje přímo na monitor, a druhá, tzv. „back buffer“, do které se obraz vykresluje. Po dokončení vykreslování se celý obsah back bufferu rychle překopíruje do primární paměti a back buffer je připraven pro vykreslování dalšího snímku.

Obr. 4 – 1: Ilustrace double bufferingu

4.2.2.PAGE FLIPPING

Další možností realizace double bufferingu je page flipping. Ten využívá toho, že má dostupné dvě ekvivalentní paměti, ze kterých lze zobrazovat obsah na monitor. V počátečním stavu se z jedné paměti zobrazuje obraz a do druhé se zapisuje. Po dokončení zápisu se obě paměti prohodí, vykreslený snímek se zobrazí na monitoru a starý snímek je přepisován snímkem následujícím.

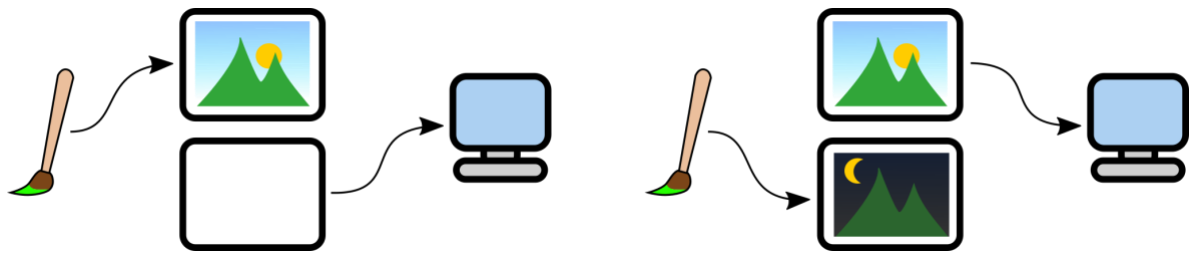
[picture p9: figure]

Obr. 4 – 2: Ilustrace page flippingu

4.3.HARDWAROVÁ REALIZACE

RAM paměť vykreslovací jednotky jsem realizoval jako modul se dvěma nezávislými statickými paměťmi. Tento modul podporuje jak klasický double buffering, tak page flipping.

Na page flipping jsem se při návrhu modulu zaměřil. Výsledkem je možnost prohození pamětí velmi rychle, téměř kdykoliv, v řádu jednotek µs. Z praktických důvodů je ale prohazování omezeno na obnovovací frekvenci displeje (60 Hz), aby se zabránilo trhání obrazu.

Klasický double buffering je jen jako nadstavba, protože je možné kopírovat jen omezený počet linek za dobu jednoho snímku. Lze jej ale využít pro postupné zobrazování snímku v průběhu jeho vykreslování. Kopírování je implementováno oboustranně, kvůli page flippingu. Je tedy teoreticky možné kopírovat obsah zobrazovaného snímku do back bufferu.

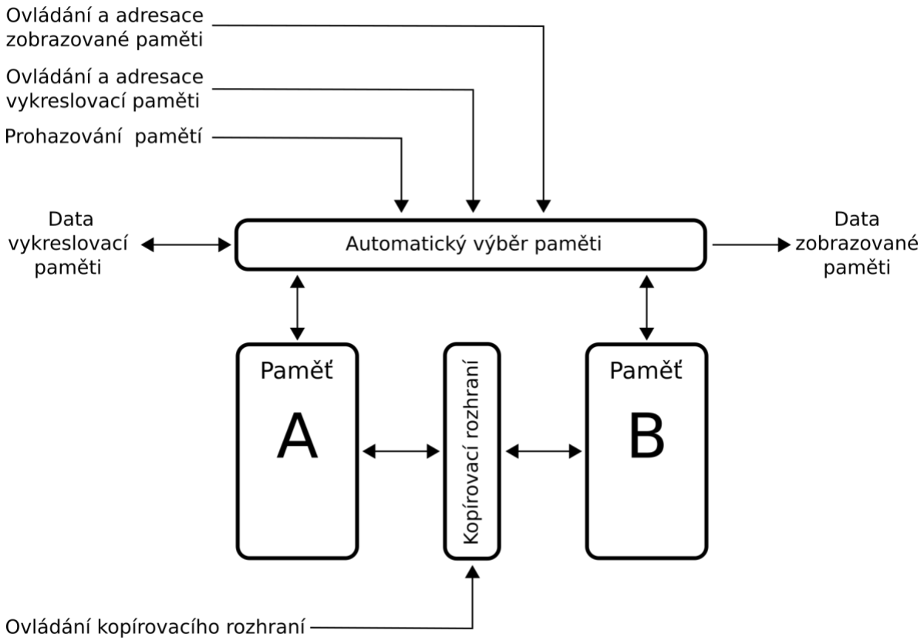
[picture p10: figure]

Obr. 4 – 3: Blokové schéma SRAM modulu

4.3.1.REALIZACE RYCHLÉHO SEKVENČNÍHO ČTENÍ

Hlavním nedostatkem statické RAM (SRAM) byla absence rychlého sekvenčního čtení, při kterém by v průběhu nebylo nutné zadávat adresu dat. Dále bylo potřeba redukovat množství adresových pinů, kvůli nedostatku pinů u zobrazovacího mikroprocesoru. Zřejmým a logickým řešením bylo použití čítače impulsů, který by adresu dat postupně zvyšoval. Při testování paměťového modulu s čítačem se ale objevily problémy. Tyto problémy byly spojené s nedostatečnou rychlostí čítačů impulsů. Ty totiž v průběhu přičítání impulsu mají na výstupu nekorektní hodnoty, které mohly ovlivnit zobrazení až 7 pixelů. Příčinou nekorektních hodnot je to, že se při změně hodnota neaktualizuje naráz, ale postupně po jednom bitu od LSB po MSB, jak můžeme vidět na příkladu v Tab. 4 – 1.

Hodnota na výstupu | Poznámka
binárně | dekadicky
00011111 | 31 | Správná hodnota před přičtením impulsu
00011110 | 30 | Nekorektní hodnota v průběhu přičítání
00011100 | 28 | Nekorektní hodnota v průběhu přičítání
00011000 | 24 | Nekorektní hodnota v průběhu přičítání
00010000 | 16 | Nekorektní hodnota v průběhu přičítání
00000000 | 0 | Nekorektní hodnota v průběhu přičítání
00100000 | 32 | Správná hodnota v průběhu přičítání
00100000 | 32 | Správná hodnota v průběhu přičítání
00100000 | 32 | Správná hodnota po přičtení impulsu

Tab. 4 – 1: Příklad postupné aktualizace hodnoty čítače impulsů

Tento problém se mohl vyřešit přidáním bufferu. Tím by se ale zbytečně zvýšila složitost ovládání. I přes vyřešení chyby by ale měla nedostatečná rychlost čítače velký vliv na maximální možné rozlišení, a proto jsem se pro tuto cestu řešení problému nerozhodl.

Jako finální řešení se ukázalo použití posuvného registru. Ten umožnuje jak rychlé sekvenční čtení, tak i o něco pomalejší čtení z libovolných adres. Toho by nešlo pomocí čítače impulsů dosáhnout.

Klíčem k rychlému sekvenčnímu čtení je posouvání hodnoty adresy jen o jeden bit. Z toho důvodu nešlo použít standardní posloupnost adres od 0 do „n“. Posloupnost těchto adres musela splňovat dvě podmínky. Následující hodnota se musela shodovat (kromě LSB) s předchozí hodnotou posunutou o jeden bit doleva, osekanou na délku slova posloupnosti. LSB mohl být pro následující hodnotu libovolně zvolen. Matematicky lze tuto podmínku vyjádřit takto:

kde proměnná x značí délku slova posloupnosti v bitech.

Druhou podmínkou bylo, že posloupnost musí obsahovat všechny možné hodnoty pro danou délku slova. Z toho také vyplývá, že se hodnoty v posloupnosti nesmí opakovat. Příklad: Pro 8bitovou délku slova musí posloupnost obsahovat 256 různých hodnot.

Tato posloupnost byla hledána pomocí počítačového programu metodou pokus – omyl, dokud neplatily obě podmínky. Tuto metodu jsem zvolil pro její jednoduchost a také proto, že pro délku adresy 8 bitů byl maximální počet iterací přijatelný.

### 5. D/A PŘEVODNÍK

Úkolem D/A převodníku, dále jen DAC (digital-to-analog converter), je převod

digitální hodnoty na hodnotu analogovou.

Existují 3 základní typy převodníků. Prvním je DAC využívající pulzní modulaci, je možné ho používat jen na nízkých frekvencích a není příliš přesný. Jeho hlavní výhoda je možnost softwarové implementace v mikroprocesoru s minimálním množstvím přidaného hardwaru. Dalším typem je binárně vyvážený DAC. Je poměrně jednoduchý a rychlý. Jeho nevýhodou je ovšem nutnost použití velkého rozsahu různých hodnot odporů. To může přinášet problémy jak s šumem u velkých hodnot odporů, tak s dostupností všech potřebných hodnot dostatečně precizních odporů. Posledním typem je převodník s odporovou sítí R-2R. Tomuto typu je věnována následující kapitola.

## 5.1. R-2R DAC

Tento typ převodníku je jedním z nejpoužívanějších. Mezi jeho výhody patří rychlost, jednoduchost a přesnost. Využívá pouze dvou hodnot odporů R a 2R. Pokud hodnotu 2R nahradíme sériovou kombinací dvou odporů hodnoty R, můžeme celý převodník realizovat jen s jednou hodnotou odporu. Další výhodou je to, že výstupní impedance je rovna hodnotě R, proto je velmi jednoduché zahrnout tento převodník do jakéhokoliv návrhu. Je také velmi snadno škálovatelný na libovolnou šířku vstupních dat.

Obr. 5 – 1: Schéma 4bitového R-2R DAC

5.1.1.ANALÝZA FUNKCE PŘEVODNÍKU

Zde si na 3bitovém R-2R převodníku ukážeme jeho funkci a zjistíme velikost jeho impedance.

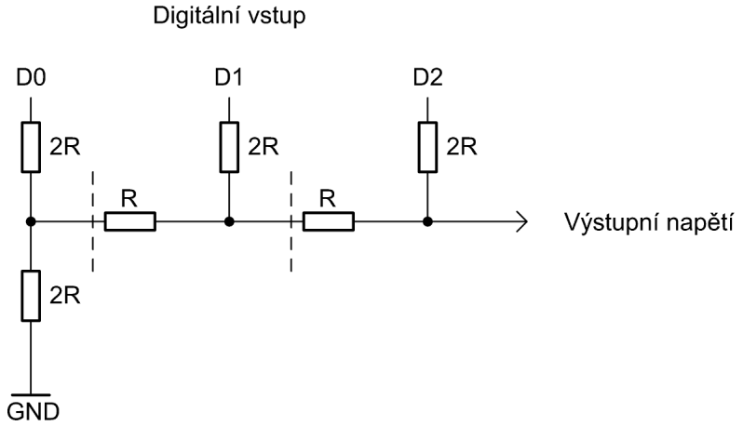
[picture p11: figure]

Obr. 5 – 2: Schéma 3bitového R-2R DAC určeného pro analýzu

Chceme-li vypočítat výstupní impedanci převodníku, můžeme zanedbat všechna vstupní napětí. Impedance na nich není závislá. Pokud tedy budeme předpokládat, že na všech vstupech je nulové napětí, můžeme začít zjednodušovat schéma nahrazováním sériových či paralelních kombinací odporů jiným odporem. Vycházíme z toho, že odpor 2R má dvojnásobnou hodnotu odporu R. Nahradíme-li tak část před první přerušovanou čarou, získáme následující schéma.

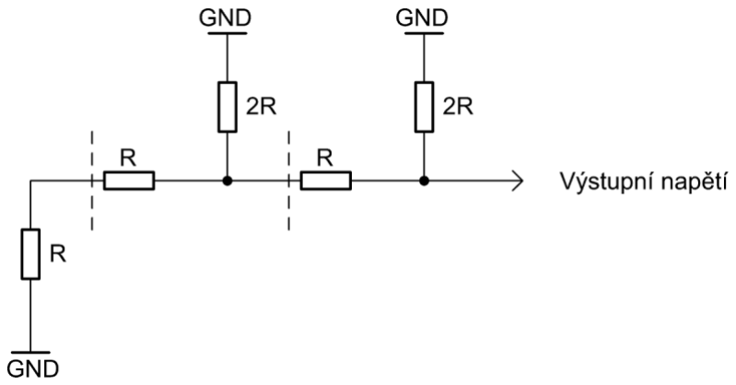
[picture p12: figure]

Obr. 5 – 3: Analýza velikosti impedance 3bitového R-2R DAC (1. krok)

Můžeme si všimnout, že vznikla stejná situace jako při nahrazení první kombinace. Pokračujeme ve zjednodušování části před další přerušovanou čarou.

Obr. 5 – 4: Analýza velikosti impedance 3bitového R-2R DAC (2. krok)

Opět nastává stejná situace. Zbývá zde poslední sériová a paralelní kombinace odporů. Provedeme poslední krok zjednodušení.

Obr. 5 – 5: Analýza velikosti impedance 3bitového R-2R DAC (3. krok)

Získali jsme zcela zjednodušené schéma převodníku, a můžeme tedy konstatovat, že výstupní impedance je rovna odporu R.

Dále si ukážeme obecné zjednodušení schématu převodníku a zjistíme vztah pro velikost výstupního napětí. Využijeme k tomu Théveninovu poučku o náhradním zdroji napětí a princip superpozice. Vycházíme opět ze stejného schématu (Obr. 5 – 2) jako v předchozí analýze impedance. Nejdříve spočítáme příspěvek vstupního napětí D0 do celkového výstupního napětí. Pomocí Théveninovy poučky zjednodušíme část před první přerušovanou čarou. Získáváme následující náhradní schéma.

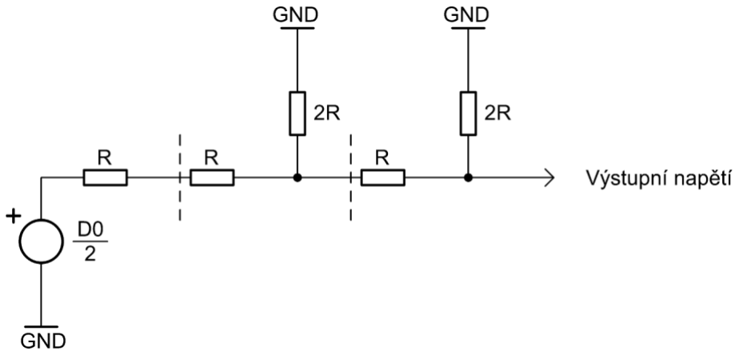
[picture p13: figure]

Obr. 5 – 6: Analýza příspěvku napětí D0 do výstupního napětí (1. krok)

Pokračujeme zjednodušením části před druhou přerušovanou čarou.

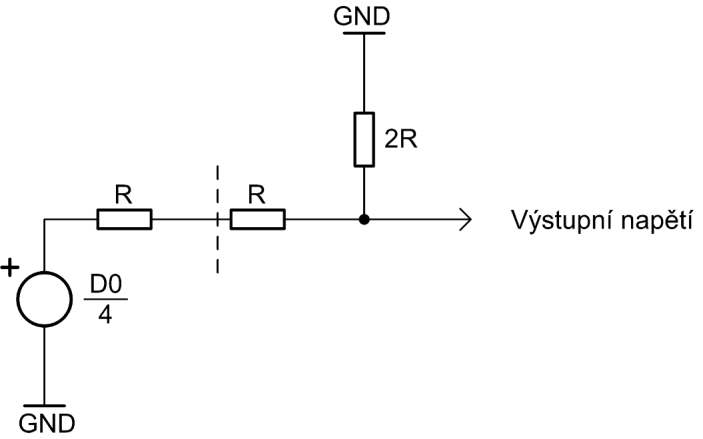
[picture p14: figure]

Obr. 5 – 7: Analýza příspěvku napětí D0 do výstupního napětí (2. krok)

Provedeme poslední krok zjednodušení, a získáme tak velikost příspěvku napětí D0 do celkového výstupního napětí.

Obr. 5 – 8: Analýza příspěvku napětí D0 do výstupního napětí (3. krok)

Zjistili jsme, že vstupní napětí D0 přispívá do celkového výstupního napětí jednou osminou. Stejnou metodou spočítáme příspěvky napětí D1 a D2. Příspěvek D1 bude dvakrát větší než D0 a příspěvek D2 bude dvakrát větší než D1. Sečtením těchto příspěvků získáváme vzorec pro celkové výstupní napětí.

Když budeme na digitální vstup přivádět postupně se zvyšující binární hodnotu, výstupní napětí se bude zvyšovat úměrně vzhledem k nastavené hodnotě. Tento typ DAC převodníku je tedy lineární.

Pro převodník s libovolnou šířkou vstupních dat můžeme pro výstupní napětí použít následující vzorec, kde n je šířka slova, D0 značí LSB a Dn-1 značí MSB.

5.2.BAREVNÁ HLOUBKA

Při návrhu převodníku bylo potřeba se rozhodnout pro určitou barevnou hloubku. Paměť má místo jen 8 bitů pro jeden pixel. Byla možnost rozdělit počet bitů rovnoměrně mezi červenou, zelenou a modrou barvu. Zůstaly by ale 2 bity nevyužité. Nastala otázka, pro které barvy tedy použít 3 bity a pro kterou jen 2.

### 5.2.1.LIDSKÉ OKO

Lidské oko obsahuje dva typy receptorů, které reagují na světlo: tyčinky a čípky. Tyčinky reagují nejvíce za špatných světelných podmínek. Neposkytují informaci o barvě, ale jen o intenzitě světla. Slouží tedy pouze k černobílému nočnímu vidění. Dále nám zajištují detekci pohybu a periferní vidění. Naopak čípky jsou nejcitlivější na jasném světle a jsou citlivé na barvu. V lidském oku je podstatně více tyčinek (120 milionů) než čípků (6 až 7 milionů).

Lidské čípky se vyskytují ve třech variantách: S, M a L. Čípky S jsou citlivé na

krátké vlnové délky (modrá barva), M na střední vlnové délky (zelená barva) a L na dlouhé vlnové délky (červená barva).

Obr. 5 – 9: Citlivost čípků S, M a L

Varianty čípků ale nejsou v lidském oku zastoupeny ve stejném počtu. Lidské oko obsahuje přibližně 63 % čípků L, 31 % čípků M a 6% čípků S.¹

Obr. 5 – 10: Citlivost čípků S, M a L vzhledem k jejich zastoupení

Dle tohoto grafu můžeme konstatovat, že je lidské oko nejméně citlivé na modrou barvu. Proto jsem v převodníku použil 3 bity pro zelenou a červenou barvu a jen 2 bity pro barvu modrou.

1
http://www.chm.davidson.edu/vce/coordchem/color.html (volně přeloženo pro potřeby práce)

### 6. ZOBRAZOVÁNÍ OBRAZU

Zobrazování obrazu řeší zobrazovací mikroprocesor. Jeho prací je generovat synchronizační signály, zajišťovat sekvenční čtení dat ze zobrazované paměti, ovládat double buffering a přijímat příkazy od vykreslovacího mikroprocesoru.

Všechny tyto úkony se musí provádět velmi rychle a ve správný čas (viz kapitola
3.1. Časování). I nepřesnost jediného instrukčního cyklu může rozsynchronizovat celé

zobrazování.

Sériová komunikace mezi mikroprocesory probíhá na protokolu UART (viz kapitola 10.1. UART), zabezpečeným paritou (viz kapitola 11.1. Parita).

Kvůli potřebné rychlosti a přesnosti byl psán firmware mikroprocesoru v jazyku symbolických adres (assembly language).

V následujících podkapitolách budou popsány významné části firmwaru.

6.1.KOMPENZACE CYKLŮ PŘERUŠENÍ

Pokud chceme využívat v programu přerušení, musíme počítat s určitou nepřesností při zavolání přerušení. Tato nepřesnost vzniká tím, že při zavolání přerušení je potřeba dokončit poslední instrukci. Instrukce použité v programu mají délku 1 – 4 cyklů. To znamená, že největší odchylka v délkách přerušení může být až 3 cykly.

Řešení, které kompenzuje tyto rozdíly, využívá toho, že jde o přerušení vytvořená

časovačem. Po přetečení časovače vzniká přerušení, ale časovač čítá dál při každém cyklu. Načteme-li hodnotu časovače po přerušení, můžeme zjistit přesnou dobu, která uběhla mezi přetečením časovače a skutečným začátkem přerušení. Z této doby si můžeme odvodit, jak dlouho trvala instrukce, která předcházela přerušení. Poté jen stačí kompenzovat cykly tak, aby přerušení trvalo vždy stejnou dobu.

Pokud předpokládáme, že nejdelší instrukce trvá 4 cykly, tak:

- trvá-li předcházející instrukce 1 cyklus, pozastavíme program na 3 cykly,
- trvá-li předcházející instrukce 2 cykly, pozastavíme program na 2 cykly,
- trvá-li předcházející instrukce 3 cykly, pozastavíme program na 1 cyklus,
- trvá-li předcházející instrukce 4 cykly, pokračujeme v programu.

Následuje výňatek z programu, který řeší tuto kompenzaci cyklů.

;**** Kompenzace cyklů přerušení ****; - celkem 12 cyklů

IN | r19,TCNT1L | ; načtení hodnoty časovače
SUBI r19,9 | ; odečtení pozice předchozí instrukce
| | ; (konstanta 9 je zde pouze jako příklad)

LDI ZH,high(ukazatel) ; načtení hodnoty ukazatele pro nepřímý skok LDI ZL,low(ukazatel)

ADD ZL,r19 | ; přičtení délky instrukce předcházející
CLR r19 | ; přerušení k adrese ukazatele
ADC ZH,r19
IJMP | | ; nepřímý skok na adresu ukazatele
ukazatel: | ; délka instrukce předcházející přerušení:
NOP | | ; 1 cyklus
NOP | | ; 2 cykly
NOP | | ; 3 cykly
| | ; 4 cykly

;************************************;

6.2.RYCHLÉ SEKVENČNÍ ČTENÍ

Rychlé sekvenční čtení je kombinací softwarového a hardwarového řešení (viz kapitola 4.3.1. Realizace rychlého sekvenčního čtení). Úkolem softwaru je provádět co

nejrychleji přičítání adres zobrazovaných dat. Je několik metod jak program urychlit. První metodou je rozepsat všechny iterace smyček. Tato metoda sice zabírá velké množství paměti (v konkrétním případě došlo přibližně ke zdvojnásobení objemu celého programu), ale smyčky, které v sobě mají jen pár instrukcí, může významně urychlit. Dalšího urychlení jsem dosáhl tím, že jsem si předem připravil do registrů všechny možné výstupní hodnoty, které může program v daném úseku potřebovat. Celkem se mi povedlo redukovat přičtení adresy zobrazovaných dat na pouhé dvě instrukce. Zobrazovací mikroprocesor pracuje na frekvenci 20 MHz a tyto dvě instrukce trvají dohromady dva cykly. Z toho vyplývá, že se dostáváme na maximální frekvenci pixelu 10 MHz, a to omezuje horizontální rozlišení přibližně na 250 pixelů. Toto rozlišení se roztáhne a vyplní originálních 640 pixelů.

Jednou instrukcí se na vstup posuvného registru přivede daná hodnota z posloupnosti bitů rychlého sekvenčního čtení (viz kapitola 4.3.1. Realizace rychlého sekvenčního čtení) a druhá instrukce vytvoří hodinový impuls pro posuvný registr, který provede aktualizaci hodnoty adresy.

V následujícím výňatku z programu vidíme začátek rychlého sekvenčního čtení.

;r20 | adr=0 clk=0
;r21 | adr=0 clk=1
;r22 | adr=1 clk=0
;r23 | adr=1 clk=1

; nastavení hodnot registrů r20-r23
IN r20,sync_port2
ANDI r20,~((1<<adr_x_bit)|(1<<clk_x_bit)) MOV r21,r20
ORI r21,(1<<clk_x_bit)
MOV r22,r20
ORI r22,(1<<adr_x_bit)
MOV r23,r22
ORI r23,(1<<clk_x_bit)

; postupné zvyšování adresy dat
OUT sync_port2,r20 | ; vstup registru = 0, clock = 0
OUT sync_port2,r21 ;0 | ; vstup registru = 0, clock = 1
OUT sync_port2,r22 | ; vstup registru = 1, clock = 0
OUT sync_port2,r23 ;1 | ; vstup registru = 1, clock = 1
OUT sync_port2,r22 | ; vstup registru = 1, clock = 0
OUT sync_port2,r23 ;1 | ; vstup registru = 1, clock = 1
OUT sync_port2,r22 | ; vstup registru = 1, clock = 0
OUT sync_port2,r23 ;1 | ; vstup registru = 1, clock = 1
OUT sync_port2,r22 | ; vstup registru = 1, clock = 0
OUT sync_port2,r23 ;1 | ; vstup registru = 1, clock = 1
OUT sync_port2,r22 | ; vstup registru = 1, clock = 0
OUT sync_port2,r23 ;1 | ; vstup registru = 1, clock = 1
OUT sync_port2,r22 | ; vstup registru = 1, clock = 0
OUT sync_port2,r23 ;1 | ; vstup registru = 1, clock = 1
OUT sync_port2,r22 | ; vstup registru = 1, clock = 0
OUT sync_port2,r23 ;1 | ; vstup registru = 1, clock = 1
OUT sync_port2,r22 | ; vstup registru = 1, clock = 0
OUT sync_port2,r23 ;1 | ; vstup registru = 1, clock = 1
OUT sync_port2,r20 | ; vstup registru = 0, clock = 0
OUT sync_port2,r21 ;0 | ; vstup registru = 0, clock = 1

### 7. VYKRESLOVÁNÍ OBRAZU

Vykreslování obrazu je prací vykreslovacího mikroprocesoru. Oproti zobrazování obrazu se u vykreslování nemusí brát příliš ohled na přesnost. Dále taky není stanovena žádná minimální rychlost vykreslování.

Celé vykreslování je ale komplexní a je potřeba ho rozdělit do několika vrstev. Proto je psán software pro vykreslovací mikroprocesor v jazyce C.

„Vykreslováním“ zde není myšleno pouhé zapisování obrazu do paměti, ale i jeho načítání z externí paměti, popřípadě generování.

Dále musí tento mikroprocesor posílat příkazy zobrazovacímu mikroprocesoru pro ovládání double bufferingu.

7.1.GENEROVÁNÍ OBRAZU

Pod pojmem generování se rozumí, že jde o algoritmické vytváření obrazu, na rozdíl od manuálního přístupu (např. načtení předem vytvořených dat z externího média a následné zobrazení).

Při generování obrazu v této práci máme k dispozici dvě základní proměnné – Jednu vstupní, což je pozice aktuálně vykreslovaného pixelu, a výstupní, kterou je výsledná barvu pixelu. Ačkoliv se pozice pixelu může jevit jako nulová informace, opak je pravdou. S pouhou informací o pozici pixelu se dá vygenerovat spoustu, někdy až nepředstavitelných věcí. Například to mohou být takzvané fraktály. Můžeme říct, že jde o nekonečné, sobě podobné vzory na různých úrovních. Pojem „fraktál“ poprvé definoval matematik Benoit Mandelbrot. Podle něj je také pojmenován jeden typ fraktálu, který objevil – Mandelbrotova množina. Pro výpočet nám stačí znát vstupní pozici pixelu.

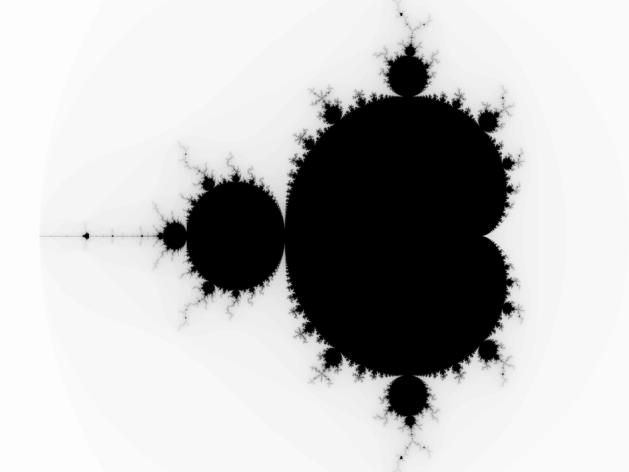
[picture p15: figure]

Obr. 7 – 1: Mandelbrotova množina

Z pozice pixelu jdou pomocí matematických výpočtů generovat například i trojrozměrné fraktály.

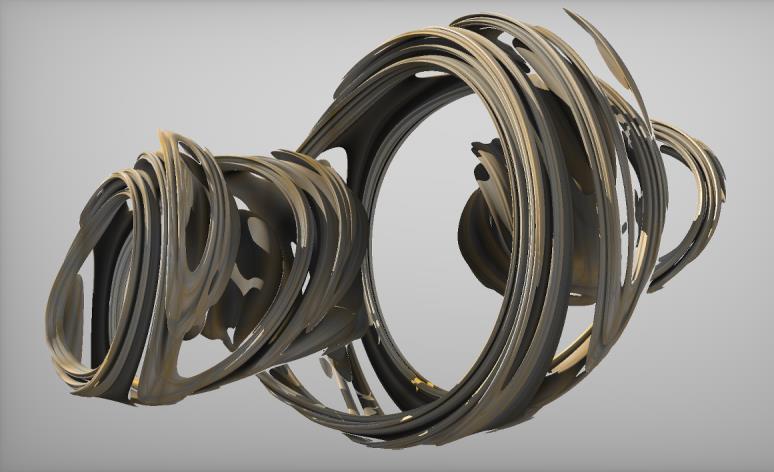
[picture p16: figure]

Obr. 7 – 2: Trojrozměrný fraktál („Quaternion“, ©2013 Ińigo Quílez, CC BY-NC-SA 3.0)

2

Nebo různé další prostorové objekty metodou zvanou „raymarching“.

Obr. 7 – 3: Ukázka raymarchingu („Raymarching - Primitives“, ©2013 Ińigo Quílez, CC BY-NC-SA 3.0)

3

V této práci je teoreticky možné tyto obrazy generovat, prakticky ale ne, kvůli nízké přesnosti použité matematické knihovny a nedostatku operační paměti. Navíc by toto náročné vykreslování trvalo velmi dlouho. Některé jednodušší útvary ale vykreslovací jednotka zvládne.

2
https://www.shadertoy.com/view/MsfGRr (citováno dne: 4.4. 2015)
3
https://www.shadertoy.com/view/Xds3zN (citováno dne: 4.4. 2015)

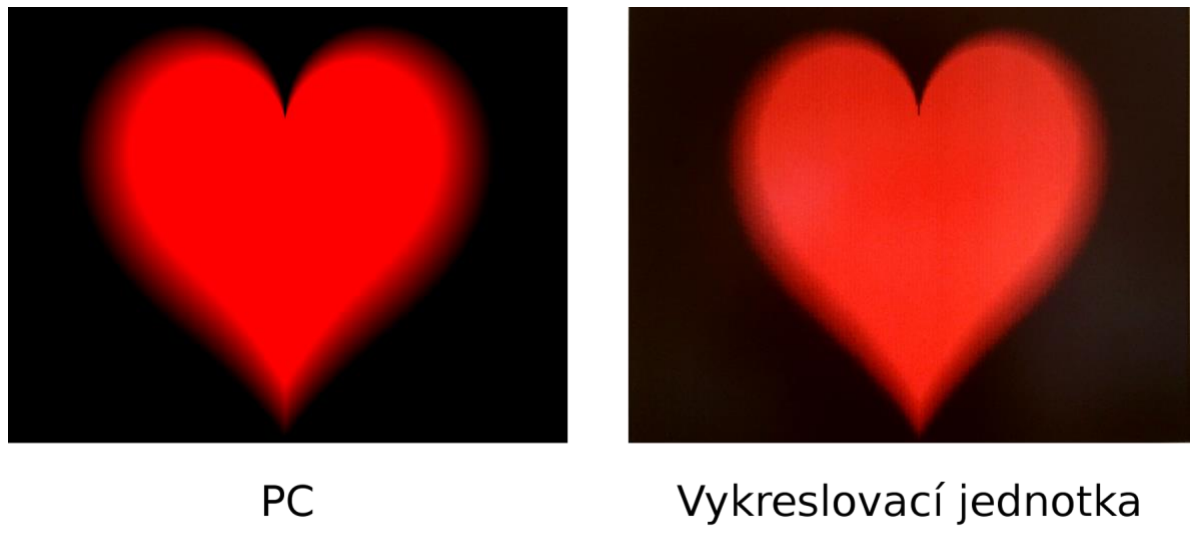
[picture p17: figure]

Obr. 7 – 4: Generování obrazu na vykreslovací jednotce (srdce)

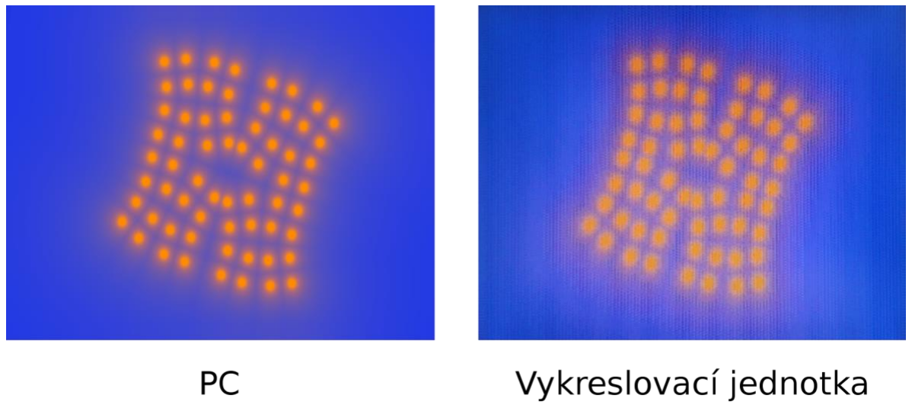
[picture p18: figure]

Obr. 7 – 5: Generování obrazu na vykreslovací jednotce (základní fraktál)

Dále můžeme za cenu nižší rychlosti vykreslování využít zápisu nebo čtení z jakékoliv pozice v paměti určené pro vykreslování. Můžeme tak například využít volnou paměť mimo obraz, která se nezobrazuje, což je 32 x 256 pixelů (to odpovídá 8kilobytům volné paměti), nebo můžeme při výpočtech využívat informace z již vykreslených pixelů. Je nespočet možností, jak tento zápis a čtení z libovolné pozice využít.

7.2.DITHERING

Jelikož většina vstupních či vygenerovaných dat má větší barevnou hloubku, než je možné zobrazit pomocí použitého D/A převodníku, je potřeba tuto barevnou hloubku nějak redukovat.

Nejjednodušší možností je osekat barevnou hloubku na potřebný počet bitů. Tím ale původní barevnou hloubku zcela ztrácíme.

Jedním z řešení tohoto problému je takzvaný dithering. Jde o techniku úmyslného přidávání šumu pro randomizaci kvantizační chyby. Tuto techniku lze použít při jakémkoliv kvantování nějaké hodnoty. Proto najde využití například i v audiu. Dále se ale budeme bavit jen o ditheringu používaném pro převod obrazu do nižší barevné hloubky.

Existuje několik algoritmů ditheringu. Jedním z nejznámějších algoritmů je Floyd-Steinberg dithering. V porovnání s jinými algoritmy má asi nejlépe vypadající výsledky. Pro jeho implementaci jsem se ale nerozhodl, protože by tento algoritmus využíval velké množství operační paměti mikroprocesoru. Vizuálně by na tom byl sice lépe než použitý ordered dithering, ale zato by byl o poznání pomalejší.

Následující obrázek ukazuje porovnání algoritmů ditheringu při redukci z 8bitového obrázku ve stupních šedi na černobílý 1bitový obrázek.

Obr. 7 – 6: Porovnání různých typů algoritmů ditheringu

7.2.1.ORDERED DITHERING

Ordered dithering je velmi jednoduchý a rychlý algoritmus pro realizaci ditheringu. Je často využívaný právě v případech, kdy je potřeba zobrazit obraz větší barevné hloubky, než dokáže dané zařízení zobrazit.

Principem algoritmu je přičtení hodnoty z prahové mapy (threshold mapy) k pixelu. Tento pixel je následně převeden do požadované nižší barevné hloubky. Přidaná hodnota z prahové mapy může zapříčinit kvantování na vyšší hladinu. Tímto se kvantizační chyba rozprostře a výsledný obraz vypadá o poznání lépe.

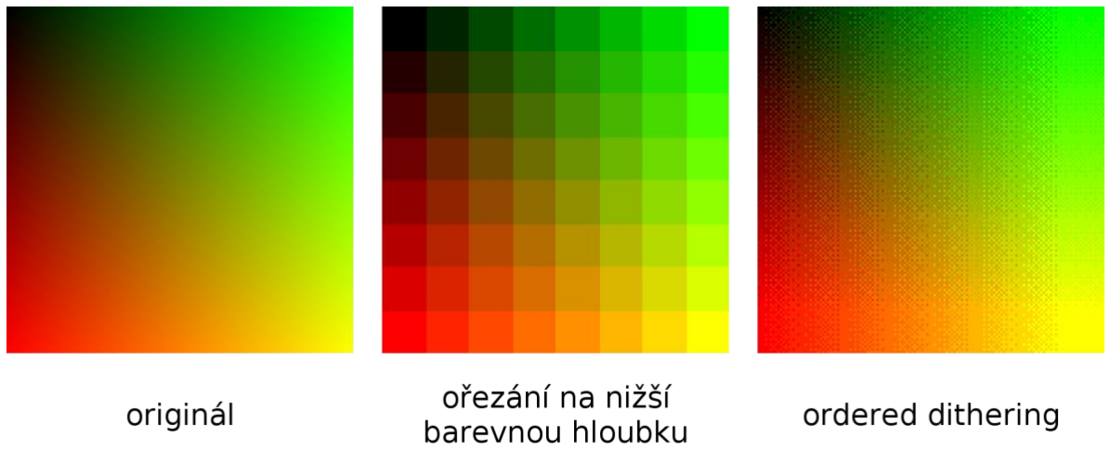
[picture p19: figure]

Obr. 7 – 7: Ordered dithering

Pro ordered dithering můžeme využít několik velikostí prahových map. Ty ovlivňují výsledný vzhled ditheringu. Nejčastěji se používá mapa o velikosti 8x8 nebo 4x4. V této práci je použita následující prahová mapa 4x4.

Pseudokód pro ordered dithering s prahovou mapou 4x4 vypadá takto:

q = velikost kvantizační hladiny

pro všechna y:
pro všechna x:
pixel = pixel[x][y] + prahová mapa[x mod 4][y mod 4] * q nový pixel = osekat_na_nižší_barevnou_hloubku(pixel) pixel[x][y] = nový pixel

### 8. NAČÍTÁNÍ DAT Z SD KARTY

Secure Digital karta, nebo také zkráceně SD karta, je nevolatilní paměťové zařízení. SD karta byla zavedena v roce 1999 jako nástupce karet MMC.

Kapacita těchto karet se dnes pohybuje v rozmezí od jednotek až po stovky gigabytů. Dle kapacity se dělí do 3 tříd: Standard-Capacity (SDSC) pro velikosti od 1MB do 2GB včetně, High-Capacity (SDHC) od 2GB do 32GB včetně, eXtended-Capacity (SDXC) od 32GB do 2TB včetně.

V této práci je podporována pouze třída SDSC, ale úpravou softwaru je možné přidat podporu pro třidu SDHC.

SD karty se vyrábí ve třech standardních velikostech: „originální velikost“, mini a micro. Nejčastěji se setkáme s originální velikostí a velikostí micro. Tato práce je kompatibilní s velikostí micro.

Rychlosti karet se udávají pomocí rychlostních tříd. Rychlosti se v těchto třídách pohybují od 2 MB/s nahoru. Vzhledem k hardwarovým problémům je v této práci bohužel podporována pouze rychlost 16KB/s.

Rychlostní třída | Rychlost
Class 2 | 2 MB/s
Class 4 | 4 MB/s
Class 6 | 6 MB/s
Class 10 | 10 MB/s
UHS Speed Class 1 (U1) | 10 MB/s
UHS Speed Class 3 (U3) | 30 MB/s

Tab. 8 – 1: Rychlostní třídy SD karet

Chceme-li zařízení podporující SD karty používat ke komerčním účelům, musíme podepsat smlouvu s SD Association (https://www.sdcard.org/) a platit roční poplatky ve výši až 3000 USD.

8.1.OVLÁDÁNÍ SD KARTY

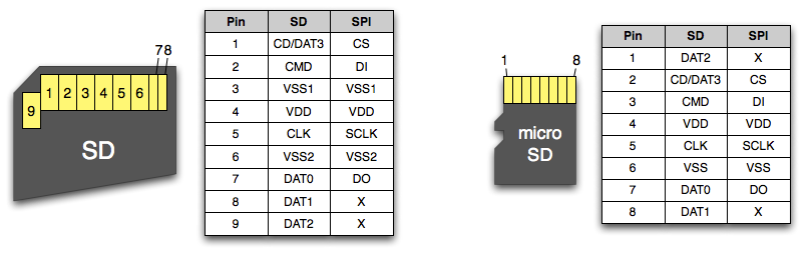
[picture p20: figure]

Obr. 8 – 1: Rozložení pinů SD a microSD karty

SD karty jsou ovládány pomocí příkazů, které můžeme posílat pomocí dvou podporovaných protokolů. Prvním protokolem je protokol SD. Ten je buď 1bitový, nebo 4bitový. Je nezbytné ho použít, chceme-li komunikovat s kartou na vysokých rychlostech. Druhým protokolem je protokol SPI, který je hojně rozšířený, jednoduchý a často je hardwarově implementován v mikroprocesorech. V této práci je využit právě protokol SPI, který je podrobněji popsán v kapitole 10.2. SPI.

Pro ovládání SD karty máme k dispozici přibližně 50 příkazů. Většinou si ale vystačíme jen s pár příkazy. Příkazy jsou chráněny proti chybám kódem CRC-7, popsaným v kapitole 11.3. CRC. Struktura příkazu poslaného SD kartě vypadá následovně:

Pozice bitu | 47 | 46 | [45:40] | [39:8] | [7:1] | 0
Šířka v bitech | 1 | 1 | 6 | 32 | 7 | 1
Hodnota | 0 | 1 | x | x | x | 1
Popis | Start bit | Vysílací bit | Číslo příkazu | Argument | CRC-7 | Stop bit

* Hodnota „x“ značí proměnnou závislou na posílaném příkazu.

Tab. 8 – 2: Struktura příkazu pro SD kartu

Ke každému příkazu navrací karta odpověď (response). Jejím hlavním účelem je informovat o případných problémech při přijímání příkazu. Odpověď může také poskytovat informace o kartě (ID karty, ID výrobce, kapacitu karty atd.). Je několik druhů odpovědí. Základním z nich je odpověď R1.

Bit | Význam
7 | Pokaždé „0“ – jde o platnou odpověď
6 | Chyba argumentu
5 | Chyba adresy
4 | Chyba v sekvenci příkazů mazání
3 | Chyba v CRC
2 | Neplatný příkaz
1 | Reset mazání
0 | V nečinném (idle) režimu

Tab. 8 – 3: Odpověď R1

Proto, aby karta přijímala jakékoliv příkazy, ji musíme nejdříve inicializovat. Pro správnou inicializaci musíme komunikovat přes SPI protokol maximálně s rychlostí 400kHz. Nejdříve kartě pošleme alespoň 74 hodinových impulsů bez jakýchkoliv dat. Poté pošleme příkaz CMD0, který kartě řekne, ať se přepne do nečinného (idle) režimu. Následuje příkaz CMD1, který zahájí inicializační proces. Dále pošleme příkaz CMD59, pro aktivaci CRC7, který se při přechodu do SPI režimu automaticky vypíná. Posledním potřebným příkazem (jde-li o SDSC kartu) je příkaz CMD16, kterým nastavíme velikost jednoho bloku v bytech (zápis a čtení je totiž orientováno blokově). Je vhodné nastavit tuto hodnotu na 512 bytů, jelikož u karet SDHC a SDXC je velikost bloku fixně nastavena na právě na hodnotu 512 bytů.

Tento způsob inicializace karty neodpovídá poslední specifikaci a neřeší detekci typu tříd karet (SDSC, SDHC, SDXC). Dále neposkytuje kartě informaci o napájecím napětí. Proto je vhodné vědět, jakou kartu chceme vložit do vykreslovací jednotky.

Jelikož je tento způsob inicializace funkční a pro tuto práci jsou dostačující karty SDSC, rozhodl jsem se kód inicializace nepřepisovat.

V této práci je pro čtení dat využíváno jen dvou příkazů: CMD18 – zahájení čtení více bloků a CMD12 – ukončení víceblokového čtení. Po poslání příkazu CMD18 vyčkáme na takzvaný „Start Blok Token“, který má hodnotu 0xFE, následuje 512 bytů dat a po nich 2 byty CRC.

Pokud v průběhu posílání dat přijme karta příkaz CMD12 pro zastavení přenosu, přenos je v tomto bodě ukončen a karta může přijímat jakékoliv příkazy. Pokud příkaz CMD12 karta nepřijala, pokračuje posíláním dalších 512 bytů dat s 2byty CRC kódu. Tento proces se opakuje, dokud není příkazem CMD12 zastaven, nebo nenastane-li překročení maximální možné adresy.

CRC kód pro detekci chyb v přenosu dat (CRC-16-CCITT) je podrobněji popsán v kapitole 11.3. CRC.

## 8.2.SOUBOROVÝ SYSTÉM FAT

Souborový systém je určitý způsob organizace dat na paměťovém médiu. Je navržen proto, aby bylo snadné přistupovat k potřebným informacím. Říká nám, kde

daná informace začíná a končí, jak je velká, nebo pod jakým názvem je uložena.

Mezi souborové systémy patří například tyto: NTFS, ext4, HFS+, FAT32, exFAT a další. FAT je standardním souborovým systémem SD karet a USB flash disků. Pro SD karty do 16MB se používá FAT12, do 2GB FAT16, do 32GB FAT32 a nad 32GB exFAT. Každá verze souborového systému FAT se v něčem mírně liší, ale všechny fungují na stejném principu.

Záznam v oddílu disku se souborovým formátem FAT začíná „Boot sektorem“. Boot sektor je 512 bytů dlouhá část, která sděluje základní informace, podle kterých se dále při čtení či zápisu řídíme.

Souborový systém FAT je adresován dvěma způsoby. Buď je adresován po sektorech, nebo po clusterech. V sektorech se udává například začátek a velikost alokační tabulky. Velikost sektoru se udává v bytech a můžeme ji zjistit v Boot sektoru, ale zpravidla je nastavena na 512 bytů. Soubory a složky jsou adresovány pomocí clusterů. Cluster je definován určitým počtem sektorů (1, 2, 4, 8, 16, 32, 64 nebo 128 sektorů). Jeho velikost vyčteme z Boot sektoru. Clustery se číslují od čísla 2 nahoru.

8.2.1.ALOKAČNÍ TABULKA

Alokační tabulka je jádrem souborového systému FAT. V alokační tabulce jsou uloženy hodnoty, podle kterých se řídíme při čtení nebo zápisu. Souborový systém exFAT je výjimkou a neřídí se alokační tabulkou, ale takzvanou alokační bitmapou, proto je tento souborový systém v této podkapitole vynechán.

Alokační tabulka obsahuje tolik hodnot, kolik má celý souborový systém clusterů. Každá z těchto hodnot má pevně danou šířku v bytech. Tato šířka se liší podle použitého souborového systému FAT. Šířka této hodnoty je 1,5 bytů pro FAT12 (dvě hodnoty jsou uloženy do trojice bytů), 2 byty pro FAT16 a 4 byty pro FAT32. Tyto hodnoty číslujeme od 0 až po „n - 1“, kde n je celkový počet clusterů v souborovém systému.

Princip funkce je následující: když čteme data z nějakého clusteru, a dojdeme na konec tohoto clusteru, vyhledáme v alokační tabulce hodnotu s indexem právě dočteného clusteru. Z této hodnoty se dozvíme hodnotu následujícího clusteru, anebo zjistíme, že byl právě dočtený cluster posledním clusterem v řetězci (došli jsme na konec čteného souboru). Při zápisu tento princip funguje podobně. V alokační tabulce hledáme volný cluster, který je označen hodnotou „0“. Po zapsání obsahu tohoto clusteru zapíšeme do hodnoty v alokační tabulce s indexem právě zapsaného clusteru číslo následujícího volného clusteru, který najdeme. Až zapíšeme poslední cluster, do hodnoty v alokační tabulce s indexem tohoto clusteru zapíšeme, že jde o poslední cluster v tomto řetězci clusterů. Jde o speciální hodnotu, která se liší dle použitého typu souborového systému FAT.

Obr. 8 – 2: Ilustrace postupného čtení pořadí clusterů z alokační tabulky.

8.2.2.SOUBOROVÉ ZÁZNAMY

Souborový systém FAT obsahuje složky a soubory. Záznamy souborů, ale i dalších podsložek se nacházejí ve složkách. Jde v podstatě o stejné záznamy s tím rozdílem, že záznam souboru ukazuje na začátek souboru a záznam složky na začátek složky, která obsahuje další záznamy. V těchto záznamech se dočteme informaci o názvu a příponě souboru (nebo názvu složky), o jeho velikosti a o první pozici clusteru, na které se tento soubor (nebo složka) nachází.

Odsazení (hexadecimálně) | Velikost v bytech | Popis
00 | 8 | Jméno
08 | 3 | Přípona
0B | 1 | Příznakový byte
0C | 8 | Využito pro nadstavbu VFAT
14 | 2 | První cluster (horní 2 byty)
16 | 2 | Čas
18 | 2 | Datum
1A | 2 | První cluster (dolní 2 byty)
1C | 4 | Velikost souboru

Tab. 8 – 4: Struktura souborového záznamu

Bit | Význam
7 | Nevyužito
6 | Nevyužito
5 | Soubor je archivován
4 | Jedná se o složku
3 | Nejedná se o záznam ale o název svazku
2 | Jde o systémový soubor / složku
1 | Jde o neviditelný soubor / složku
0 | Soubor je určen jen pro čtení

Tab. 8 – 5: Struktura příznakového bytu

Jelikož tyto záznamy podporují pouze krátká jména souborů s formátováním ASCII, označená jako formát 8.3 (8 znaků jména, tečka a 3 znaky přípony), byl také zaveden speciální formát záznamů LFN (long filename), který umožnuje používat jména (dohromady s příponou a tečkou před příponou) o velikosti až 255 znaků s formátováním UCS-2 (z tohoto formátu vznikl dnešní formát UTF-16). Formát LFN je ale chráněn patentem a proto nemůže být komerčně využíván.

Formát LFN funguje tak, že se využije několik záznamů pro uložení dlouhého jména a ty jsou pak následovány záznamem odkazujícím na samotný soubor nebo složku. U LFN záznamů jsou nastaveny první 4 bity u příznakového bytu na jedničku a tím se zamezí zobrazování těchto záznamů ve většině operačních systémů a programů.

Odsazení (hexadecimálně) | Velikost v bytech | Popis
00 | 1 | Číslo LFN záznamu
01 | 10 | 5 znaků UCS-2
0B | 1 | Příznakový byte
0C | 1 | Rezervováno – vždy „0“
0D | 1 | Kontrolní součet
0E | 12 | 6 znaků UCS-2
1A | 2 | Vždy „0“
1C | 4 | 2 znaky UCS-2

Tab. 8 – 6: Struktura LFN záznamu

V čísle LFN záznamu je 7. bit (MSB) využit pro označení smazaného záznamu. Pokud jde o formát 8.3, tak ten využívá pro označení smazaného záznamu prvního znaku ve jméně, který při smazání souboru přepíše na hexadecimální hodnotu E5. Dále je v čísle LFN záznamu využit 6. bit pro označení posledního LFN záznamu. Ve skutečnosti je ovšem poslední záznam první, protože jsou LFN záznamy číslovány sestupně.

Záznamy ve složce:

Normální záznam 1

Normální záznam 2

LFN pro normální záznam 3 (3. část)

LFN pro normální záznam 3 (2. část)

LFN pro normální záznam 3 (1. část)

Normální záznam 3

Normální záznam 4

Tab. 8 – 7: Příklad záznamů LFN ve složce

### 9. ZPRACOVÁNÍ VSTUPNÍCH DAT

Načtená data z SD karty jsou dále zpracovávána. V této práci je implementováno zobrazování obrázků formátu BMP a interpretace jednoduchých příkazů.

9.1.OBRAZ FORMÁTU BMP

BMP (bitmapa), známá také jako DIB, je formát pro ukládání rastrových obrázků. BMP obrázek obsahuje hlavičku a obrazová data. Dále může případně obsahovat paletu indexovaných barev a barevný profil (ICC). Hlavička definuje základní parametry obrázku, jako je šířka, výška, bitová hloubka, celková velikost obrázku bytech atd.

Odsazení (hexadecimálně) | Velikost v bytech | Popis
00 | 2 | Identifikátor – „BM“ v ASCII (42, 4D hexadecimálně)
02 | 4 | Velikost BMP souboru v bytech
06 | 4 | Rezervováno
0A | 4 | Odsazení, kde začínají obrazová data

Následuje druhá část hlavičky, která může mít více typů. Zde je popsán typ „BITMAPINFOHEADER“

0E | 4 | Velikost této části hlavičky (40 bytů)
12 | 4 | Šířka bitmapy v pixelech
16 | 4 | Výška bitmapy v pixelech
1A | 2 | Počet barevných ploch (musí byt „1“)
1C | 2 | Počet bitů na pixel (barevná hloubka)
1E | 4 | Použitá komprese („0“ – bez komprese)
22 | 4 | Velikost obrázku (stačí zadat „0“ pro nekomprimovaný obrázek)
26 | 4 | Horizontální rozlišení (pixely na metr)
2A | 4 | Vertikální rozlišení (pixely na metr)
2E | 4 | Počet barev v barevné paletě
32 | 4 | Počet důležitých barev (zpravidla ignorována)

Tab. 9 – 1: Hlavička BMP souboru

Po přečtení informací z hlavičky se můžeme přesunout k obrazovým datům. Pixely jsou zapisovány zleva doprava a linky zespod nahoru. Na každé lince se může vyskytovat výplň (padding). Každá linka je vyplněna tak, aby byl počet bytů na lince dělitelný čtyřmi beze zbytku.

Obrazová data

Pixel [0, v-1] | Pixel [1, v-1] | Pixel [2, v-1] | … | Pixel [š-1, v-1] | Výplň
Pixel [0, v-2] | Pixel [1, v-2] | Pixel [2, v-2] | … | Pixel [š-1, v-2] | Výplň

…

Pixel [0, 7] | Pixel [1, 7] | Pixel [2, 7] | … | Pixel [š-1, 7] | Výplň
Pixel [0, 6] | Pixel [1, 6] | Pixel [2, 6] | … | Pixel [š-1, 6] | Výplň
Pixel [0, 5] | Pixel [1, 5] | Pixel [2, 5] | … | Pixel [š-1, 5] | Výplň
Pixel [0, 4] | Pixel [1, 4] | Pixel [2, 4] | … | Pixel [š-1, 4] | Výplň
Pixel [0, 3] | Pixel [1, 3] | Pixel [2, 3] | … | Pixel [š-1, 3] | Výplň
Pixel [0, 2] | Pixel [1, 2] | Pixel [2, 2] | … | Pixel [š-1, 2] | Výplň
Pixel [0, 1] | Pixel [1, 1] | Pixel [2, 1] | … | Pixel [š-1, 1] | Výplň
Pixel [0, 0] | Pixel [1, 0] | Pixel [2, 0] | … | Pixel [š-1, 0] | Výplň

Tab. 9 – 2: Znázornění rozložení obrazových dat

9.2.INTERPRETACE PŘÍKAZŮ

V této práci je využito jednoduchých interpretovaných příkazů. Je načítán textový soubor, který tyto příkazy obsahuje. Syntax vychází ze zápisu volání funkcí v jazyce C. Všechny implementované příkazy jsou popsány v přiložené technické dokumentaci. Jsou podporovány jednořádkové a víceřádkové komentáře. Syntax vypadá následovně:

// Jednořádkový komentář

/* Víceřádkový komentář
Víceřádkový komentář
Víceřádkový komentář */

// příkaz (argument1, argument2, ... );

// následují příklady zápisu příkazů

bmp_config(0);
clear_color(0,0,0);
draw_bmp ("images/22.bmp"); repeat();

### 10.POUŽITÉ KOMUNIKAČNÍ

### PROTOKOLY

## 10.1. UART

Pod zkratkou UART se skrývá pojem „univerzální asynchronní přijímač/vysílač“ (Universal Asynchronous Receiver/Transmitter). Někdy se využívá synchronní verze UARTu označovaná jako USART. Tento protokol je obyčejně používán ve spojení s komunikačními standardy RS-232, RS-422 nebo RS-485. Jde o protokol sériové komunikace. Pro jednosměrný přenos se využívá jeden vodič a pro obousměrný přenos vodiče dva. Data se posílají v rámci, který začíná start bitem a končí stop bitem. Rámec může obsahovat (zpravidla) 5 až 8 datových bitů a případnou paritu. Parita je podrobněji popsána v kapitole 11.2. Parita.

Takzvaný „Baud rate“ udává rychlost přenosu (bity za sekundu). Zpravidla se využívá několik standardních rychlostí, mezi které patří například baud 1200, 2400, 4800, 9600 a další.

Obr. 10 – 1: Rámec UARTu

## 10.2. SPI

SPI (Serial Peripheral Interface) je sériové synchronní rozhraní využívající architekturu master-slave. Používají se vodiče označované jako SCLK – serial clock, SS – slave select, MOSI – master out, slave in, MISO – master in, slave out. Na toto rozhraní je zpravidla připojen jeden „Master“ a několik dalších zařízení „Slave“ (jejich maximální počet závisí na počtu použitých vodičů SS). Master distribuuje hodinový signál a tím také určuje, kdy se budou vysílat informace. Informace se vysílají a přijímají zároveň, jde tedy o režim full duplex. SPI může fungovat i v režimu simplex, je-li zapojen pouze jeden komunikační vodič (MOSI nebo MISO).

Hardwarově je rozhraní SPI řešeno pomocí dvou posuvných registrů, které vodiči MOSI a MISO vzájemně propojíme.

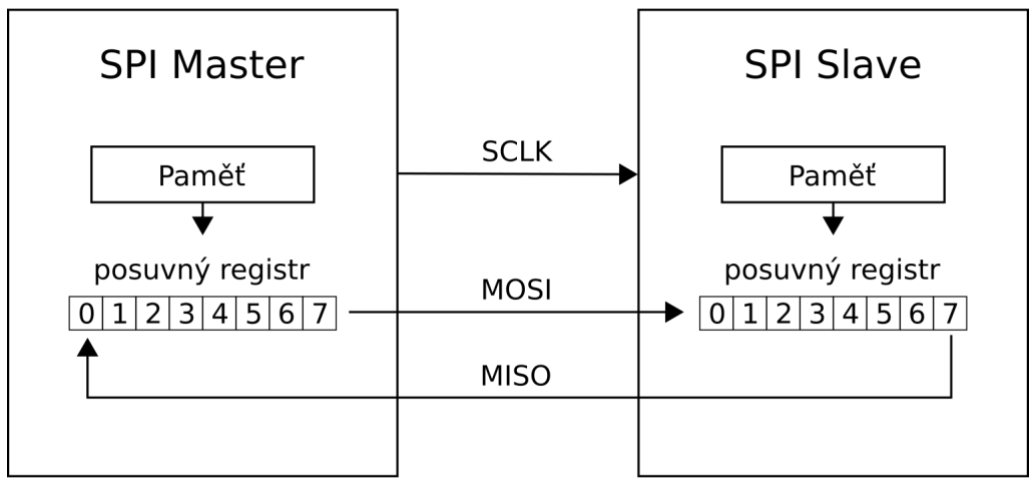
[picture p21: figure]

Obr. 10 – 2: Hardwarová realizace SPI

Obr. 10 – 3: Typické propojení více SPI zařízení

### 11.POUŽITÁ ZABEZPEČENÍ PROTI CHYBÁM

### 11.1. MAJORITNÍ VYHODNOCENÍ

Nejjednodušším principem zabezpečení je majoritní vyhodnocení. Je založeno na vícenásobném posílání stejné informace. Informace která převažuje, je vyhodnocena jako správná. Například, pošleme-li 5 bitů stejné informace a přijde nám dvakrát „0“ a třikrát „1“, považujeme „1“ za pravdivou informaci.

Pokud si můžeme informaci vyžádat znovu, je to pro nás výhodou. Můžeme tak vyhodnocovat vícebitovou informaci. Tuto informaci si budeme vyžadovat tak dlouho, dokud nám nepřijde dvakrát (nebo i vícekrát) stejná informace po sobě.

Tato metoda zabezpečení chyb je v této práci zkombinována se zabezpečením CRC (více v kapitole 11.3. CRC). Vyžadujeme zde informaci tak dlouho, dokud za sebou nepřijde dvakrát stejné CRC.

## 11.2. PARITA

Parita je dalším jednoduchým zabezpečením proti chybám. Detekuje až 50% chyb a využívá jen jednoho redundantního bitu. Paritní bit neposkytuje možnost pro korekci dat. Parita může být buď sudá, nebo lichá a vysílač i přijímač musí vědět, který typ parity je používán. Paritní bit je nastaven tak, aby součet všech „1“ datových bitů včetně bitu paritního byl buďto sudý (sudá parita), nebo lichý (lichá parita).

Data | Přidaný paritní bit
Lichá parita | Sudá parita
10010100 | 0 | 1
01111110 | 1 | 0

Tab. 11 – 1: Příklad paritního bitu

Hodnotu parity lze vypočítat pomocí exkluzivní disjunkce (XOR) mezi všemi bity v daném slově. Parita je vlastně speciálním případem CRC (CRC-1).

## 11.3. CRC

CRC, neboli cyklický redundantní kód, je komplexní řešení detekce chyb. Využívá dělení vstupního polynomu (posílané zprávy) polynomem generačním v algebře modula 2. Zbytek, který po dělení vznikne, se připojí k posílané zprávě. Přijímač přijatá data (zpráva + zbytek po dělení) znovu vydělí generačním polynomem. Je-li zbytek po tomto dělení nulový, zpráva neobsahuje detekovatelnou chybu.

Pokud je generační polynom zvolen správně, může tento kód detekovat všechny jednobitové chyby, dvoubitové chyby vzdálené od sebe až po délku rovné řádu generačního polynomu, všechny chyby s lichým počtem chybných bitů a většinu shluků chyb.

Je 34 druhů nejpoužívanějších CRC generačních polynomů. V této práci jsou využity polynomy CRC-7:

a CRC-16-CCITT:

Vstupní data reprezentují koeficienty vstupního polynomu. Váha bitu odpovídá exponentu členu „x“. Převod tedy vypadá následovně:

V následujícím příkladu využijeme vstupní polynom z předchozího příkladu a
jako generační polynom si zvolíme | . Výpočet CRC je následující: polynomy
mezi sebou vydělíme a zjistíme zbytek po dělení,

vypíšeme si koeficienty každého členu a na těchto koeficientech provedeme operaci modulo s číslem 2.

Tyto koeficienty představují výsledek CRC s generačním polynomem | v binární
podobě.

V praxi se pro získání zbytku po dělení polynomu polynomem v algebře modula 2 využívá exkluzivní disjunkce (XOR). V takovém případě pracujeme jen s koeficienty a nemusíme si tak zprávu převádět na polynom.

Výpočet tímto způsobem je následující: Nejdříve ke zprávě přidáme nuly, aby se nám zbytek po dělení „neztratil“. Počet těchto nul je roven řádu generačního polynomu bez jedné. Zprávu a generační polynom zarovnáme tak, aby byly MSB na stejné pozici.

Pokud je ve zprávě na pozici MSB generačního polynomu „1“ provedeme exkluzivní disjunkci mezi zprávou a generačním polynomem, pokud „0“, tak tento krok přeskočíme. Posuneme generační polynom o bit doprava. Tyto kroky opakujeme, dokud není původní zpráva rovna nule. Následně získáváme požadované CRC.

Celý tento algoritmus se dá realizovat lineárním zpětnovazebným posuvným registrem se zpětnou vazbou zavedenou do členů s koeficientem „1“ přes hradlo XOR.

Obr. 11 – 1: Hardwarová realizace generátoru CRC-7

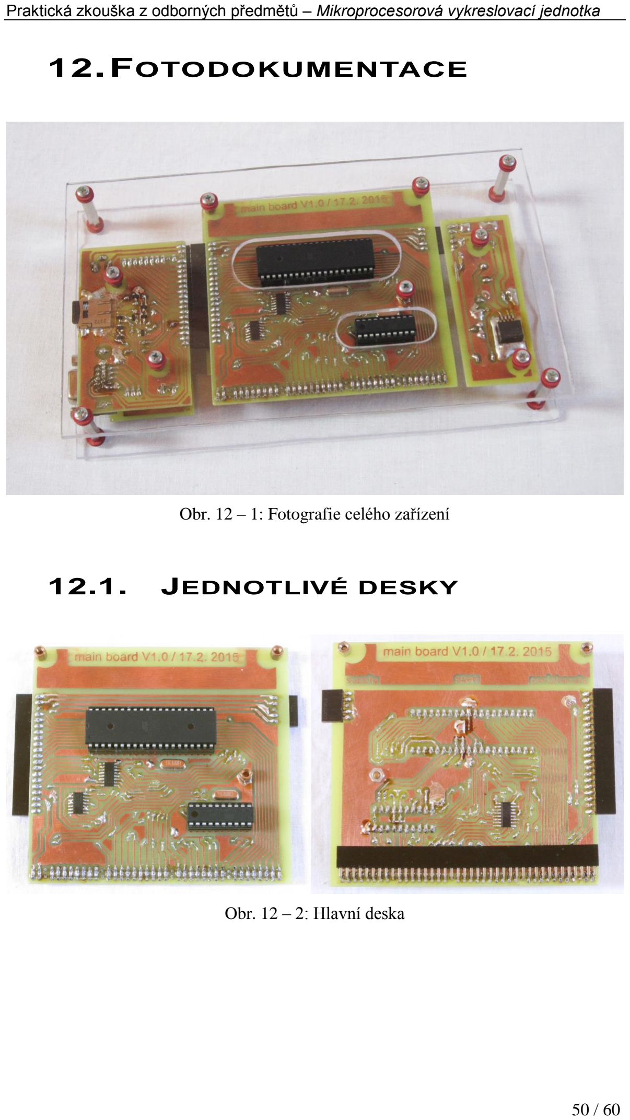
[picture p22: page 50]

### 12.FOTODOKUMENTACE

Obr. 12 – 1: Fotografie celého zařízení

### 12.1. JEDNOTLIVÉ DESKY

Obr. 12 – 2: Hlavní deska

Obr. 12 – 3: SRAM modul

Obr. 12 – 4: Deska se vstupy a výstupy

Obr. 12 – 5: DAC

Obr. 12 – 6: Deska s regulátorem napětí

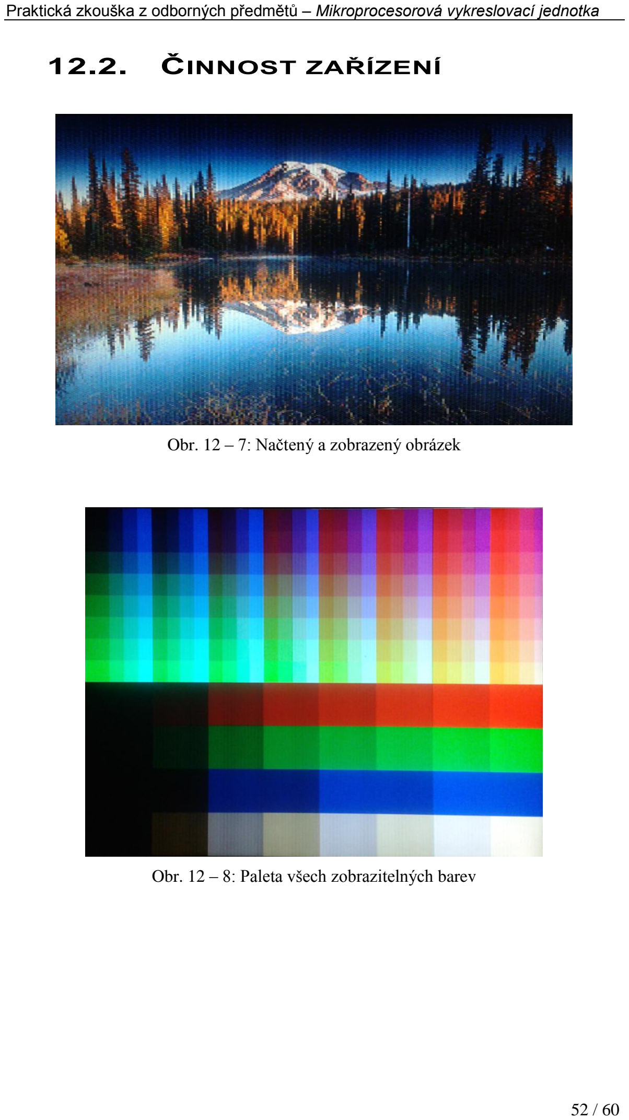
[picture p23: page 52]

### 12.2. ČINNOST ZAŘÍZENÍ

Obr. 12 – 7: Načtený a zobrazený obrázek

Obr. 12 – 8: Paleta všech zobrazitelných barev

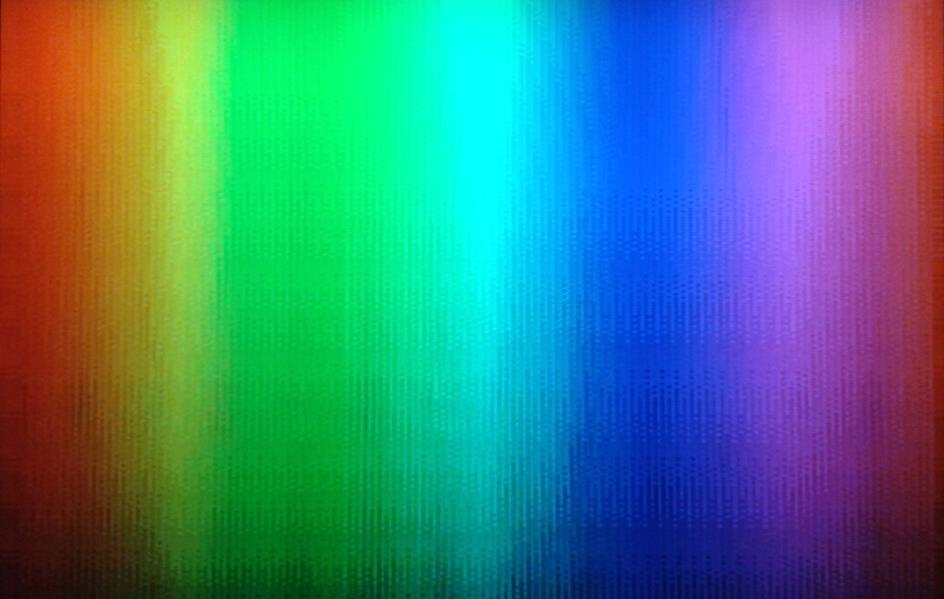
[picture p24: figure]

Obr. 12 – 9: HSV paleta se zapnutým ditheringem

### 12.3. CHYBY PŘI VÝVOJI

Obr. 12 – 10: Chyby v obraze před použitím adresace pomocí posuvných registrů


Obr. 12 – 11 : Problém nepřesnosti matematické knihovny při složitějších výpočtech

Obr. 12 – 12: Chyby v obraze před implementací CRC

## ZÁVĚR

Při vývoji tohoto zařízení se naskytlo více problémů, než jsem původně očekával. Proto jsem musel určité části více rozvinout a jiné zase zkrátit. S tímto se ale musí počítat, protože jde o vývoj, a ne o výrobu. Pokud něco vyvíjíme, nevíme, s čím vším se můžeme v průběhu vývoje setkat, a je těžké určit termín dokončení, na rozdíl od výroby, při které jsou všechny postupy předem přesně naplánovány.

Celkově se ale vývoj zařízení vydařil a jeho poslední verze obsahuje jen malé množství chyb, které se nepovedlo odstranit, převážně proto, že jde o chyby, jež se projevují náhodně.

Celá tato práce by mohla být řešena jediným mikroprocesorem s minimálním množstvím přidaného hardwaru, ale mikroprocesory s dostatečným výkonem a pamětí (dnes sice běžně vyráběné) bohužel nejsou dostupné v ČR, nebo jsou dostupné za

extrémně vysokou cenu.

Zato byla ale práce pestřejší a věnovala se širšímu okruhu problémů a díky tomu je zde sepsáno více rozmanitých informací pro volné použití v jiných projektech.

### DODATEK

Tato práce obsahuje technickou dokumentaci, zdrojové kódy firmwaru obou mikroprocesorů, schémata a návrhy desek plošných spojů. Všechny tyto soubory najdete na přiloženém CD.

Celá tato práce včetně veškerých souborů je dostupná také na GitHubu – https://github.com/Aroidzap/mikroprocesorova-vykreslovaci-jednotka.

Zdrojové kódy jsou komentovány v anglickém jazyce, aby byly srozumitelné pro větší okruh lidí, kteří mohou části kódu využít pro svou potřebu.

Celá tato práce, včetně technické dokumentace, schémat a návrhu desek plošných spojů je k dispozici pod licencí CC-BY 4.0. Zdrojové kódy jsou licencovány pod licencí MIT. Přesnější informace o licencích najdete na GitHubu nebo na přiloženém CD.

### SEZNAM POUŽITÉ LITERATURY A STUDIJNÍCH MATERIÁLŮ

Dokumentace a technické specifikace:

1) Atmel: Datasheet, ATmega32(L) Complete, revision Q, 02/2011. Dostupné z: http://www.atmel.com/Images/doc2503.pdf
2) Atmel: Datasheet, ATtiny2313A/4313 Complete, revision B, 10/2011. Dostupné z: http://www.atmel.com/Images/doc8246.pdf
3) Samsung semiconductor: Datasheet, K6X1008C2D, revision 1.0, 09/2003. Dostupné z: http://pdf1.alldatasheet.com/datasheet-pdf/view/77267/SAMSUNG/K6X1008C2D.html (http://pdf1.alldatasheet.com/datasheet-pdf/view/77267/SAMSUNG/K6X1008C2D.html)
4) NXP Semiconductors: Datasheet, 74HC164; 74HCT164, revision 7, 06/2013. Dostupné z: http://www.nxp.com/documents/data_sheet/74HC_HCT164.pdf
5) NXP Semiconductors: Datasheet, 74HC157; 74HCT157, revision 6, 08/2012. Dostupné z: http://www.nxp.com/documents/data_sheet/74HC_HCT157.pdf
6) NXP Semiconductors: Datasheet, 74HC245; 74HCT245, revision 3, 01/2005. Dostupné z: http://www.nxp.com/documents/data_sheet/74HC_HCT245.pdf
7) SD Group: SD Specifications, Part 1, Physical Layer Simplified Specification, Version 4.10, January 22, 2013. Dostupné z: https://www.sdcard.org/downloads/pls/simplified_specs/part1_410.pdf

Wikipedia – otevřená encyklopedie:

8) http://www.wikipedia.org/

Elementární C knihovny pro AVR:

9) http://www.nongnu.org/avr-libc/user-manual/

Podobná zařízení, VGA:

10) http://tinyvga.com/
11) http://www.lucidscience.com/
12) http://quinndunki.com/blondihacks/?page_id=1761
13) http://www.linusakesson.net/scene/craft/index.php

VGA:

14) http://www.javiervalcarce.eu/html/vga-signal-format-timming-specs-en.html

15) http://pinouts.ru/Video/Vga15_pinout.shtml

Elektronika obecně, převodníky:

16) http://hyperphysics.phy-astr.gsu.edu/hbase/electronic/
17) http://www.maximintegrated.com/en/design/techdocs/app-notes/index.mvp
18) http://www.tek.com/blog/tutorial-digital-analog-conversion-%E2%80%93-r-2r-dac (http://www.tek.com/blog/tutorial-digital-analog-conversion-%E2%80%93-r-2r-dac)

Double buffering, page flipping:

19) https://docs.oracle.com/javase/tutorial/extra/fullscreen/doublebuf.html

Dithering:

20) http://www.tannerhelland.com/4660/dithering-eleven-algorithms-source-code/

Vnímání barev lidským okem:

21) http://www.chm.davidson.edu/vce/coordchem/color.html

SD karty:

22) http://codeandlife.com/2012/04/02/simple-fat-and-sd-tutorial-part-1/
23) http://elm-chan.org/
24) http://stackoverflow.com/questions/8080718/sdhc-microsd-card-and-spi-initialization (http://stackoverflow.com/questions/8080718/sdhc-microsd-card-and-spi-initialization)

CRC:

25) http://www.barrgroup.com/Embedded-Systems/How-To/CRC-Calculation-C-Code (http://www.barrgroup.com/Embedded-Systems/How-To/CRC-Calculation-C-Code)
26) https://www.ccsinfo.com/forum/viewtopic.php?t=24977

FAT:

27) http://www.maverick-os.dk/FileSystemFormats/FAT32_FileSystem.html
28) http://www.win.tue.nl/~aeb/linux/fs/fat/fat-1.html

BMP:

29) http://www.fastgraph.com/help/bmp_header_format.html

### SEZNAM OBRÁZKŮ, GRAFŮ A

### TABULEK

Obr. 1 – 1: Zjednodušené principiální blokové schéma celého zařízení Obr. 2 – 1: ATtiny4313 – rozložení pinů
Obr. 2 – 2: ATmega32 – rozložení pinů
Obr. 3 – 1: VGA konektor
Obr. 3 – 2: VGA synchronizační signály Obr. 3 – 3: Mapování pixelu 1:1
Obr. 3 – 4: Overscan 10%
Obr. 3 – 5: Overscan vykreslovací jednotky Obr. 4 – 1: Ilustrace double bufferingu Obr. 4 – 2: Ilustrace page flippingu
Obr. 4 – 3: Blokové schéma SRAM modulu
Obr. 5 – 1: Schéma 4bitového R-2R DAC
Obr. 5 – 2: Schéma 3bitového R-2R DAC určeného pro analýzu
Obr. 5 – 3: Analýza velikosti impedance 3bitového R-2R DAC (1. krok) Obr. 5 – 4: Analýza velikosti impedance 3bitového R-2R DAC (2. krok) Obr. 5 – 5: Analýza velikosti impedance 3bitového R-2R DAC (3. krok) Obr. 5 – 6: Analýza příspěvku napětí D0 do výstupního napětí (1. krok) Obr. 5 – 7: Analýza příspěvku napětí D0 do výstupního napětí (2. krok) Obr. 5 – 8: Analýza příspěvku napětí D0 do výstupního napětí (3. krok) Obr. 5 – 9: Citlivost čípků S, M a L
Obr. 5 – 10: Citlivost čípků S, M a L vzhledem k jejich zastoupení Obr. 7 – 1: Mandelbrotova množina
Obr. 7 – 2: Trojrozměrný fraktál
„Quaternion“, ©2013 Ińigo Quílez, CC BY-NC-SA 3.0

Obr. 7 – 3: Ukázka raymarchingu
„Raymarching - Primitives“, ©2013 Ińigo Quílez, CC BY-NC-SA 3.0

Obr. 7 – 4: Generování obrazu na vykreslovací jednotce (srdce)
Obr. 7 – 5: Generování obrazu na vykreslovací jednotce (základní fraktál) Obr. 7 – 6: Porovnání různých typů algoritmů ditheringu
Obr. 7 – 7: Ordered dithering
Obr. 8 – 1: Rozložení pinů SD a microSD karty
Obr. 8 – 2: Ilustrace postupného čtení pořadí clusterů z alokační tabulky. Obr. 10 – 1: Rámec UARTu
Obr. 10 – 2: Hardwarová realizace SPI
Obr. 10 – 3: Typické propojení více SPI zařízení

Obr. 11 – 1: Hardwarová realizace generátoru CRC-7 Obr. 12 – 1: Fotografie celého zařízení
Obr. 12 – 2: Hlavní deska
Obr. 12 – 3: SRAM modul
Obr. 12 – 4: Deska se vstupy a výstupy Obr. 12 – 5: DAC
Obr. 12 – 6: Deska s regulátorem napětí
Obr. 12 – 7: Načtený a zobrazený obrázek
Obr. 12 – 8: Paleta všech zobrazitelných barev
Obr. 12 – 9: HSV paleta se zapnutým ditheringem
Obr. 12 – 10: Chyby v obraze před zavedením adresace pomocí posuvných registrů Obr. 12 – 11 : Problém nepřesnosti matematické knihovny při složitějších výpočtech Obr. 12 – 12: Chyby v obraze před implementací CRC

Tab. 3 – 1: Rozložení pinů VGA konektoru
Tab. 3 – 2: Vysvětlení zkratek částí synchronizačních signálů Tab. 3 – 3: Hodnoty časování pro režim 640x480 při 60Hz Tab. 3 – 4: Hodnoty časování pro nižší frekvenci pixelu
Tab. 3 – 5: Odchylky v hodnotách časování
Tab. 4 – 1: Příklad postupné aktualizace hodnoty čítače impulsů Tab. 8 – 1: Rychlostní třídy SD karet
Tab. 8 – 2: Struktura příkazu pro SD kartu
Tab. 8 – 3: Odpověď R1
Tab. 8 – 4: Struktura souborového záznamu Tab. 8 – 5: Struktura příznakového bytu Tab. 8 – 6: Struktura LFN záznamu
Tab. 8 – 7: Příklad záznamů LFN ve složce Tab. 9 – 1: Hlavička BMP souboru
Tab. 9 – 2: Znázornění rozložení obrazových dat Tab. 11 – 1: Příklad paritního bitu

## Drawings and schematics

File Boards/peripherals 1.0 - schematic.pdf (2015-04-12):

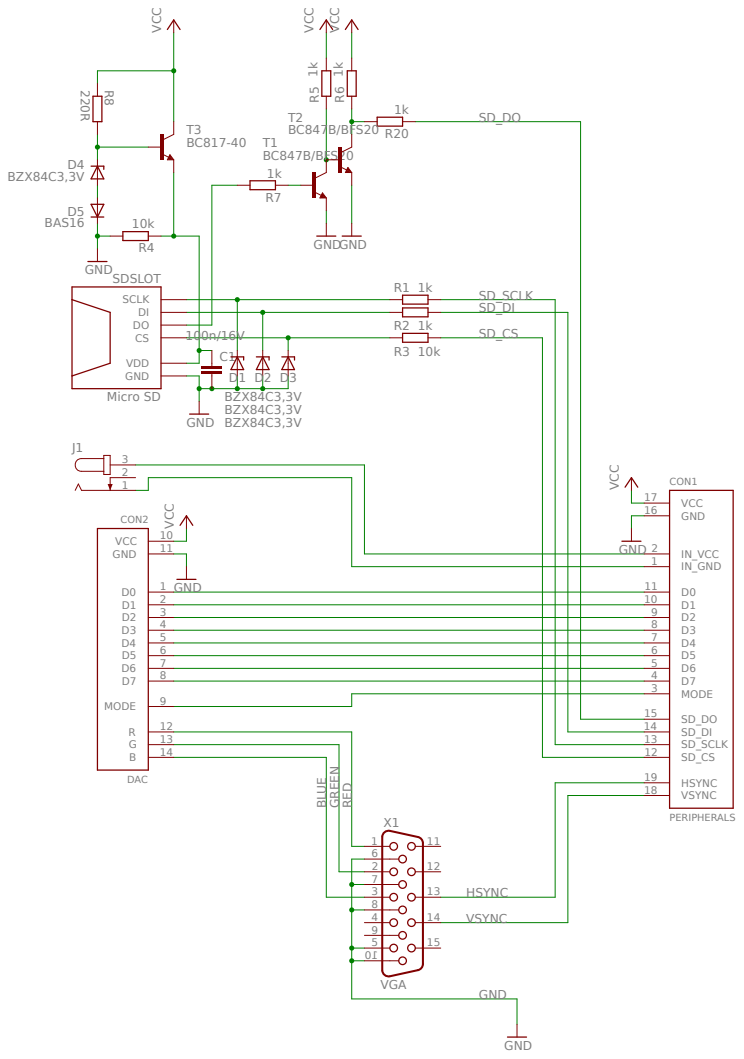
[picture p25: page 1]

SCLK GND

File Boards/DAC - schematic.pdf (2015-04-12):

# IC1PGND VCC

# IC2PGND VCC

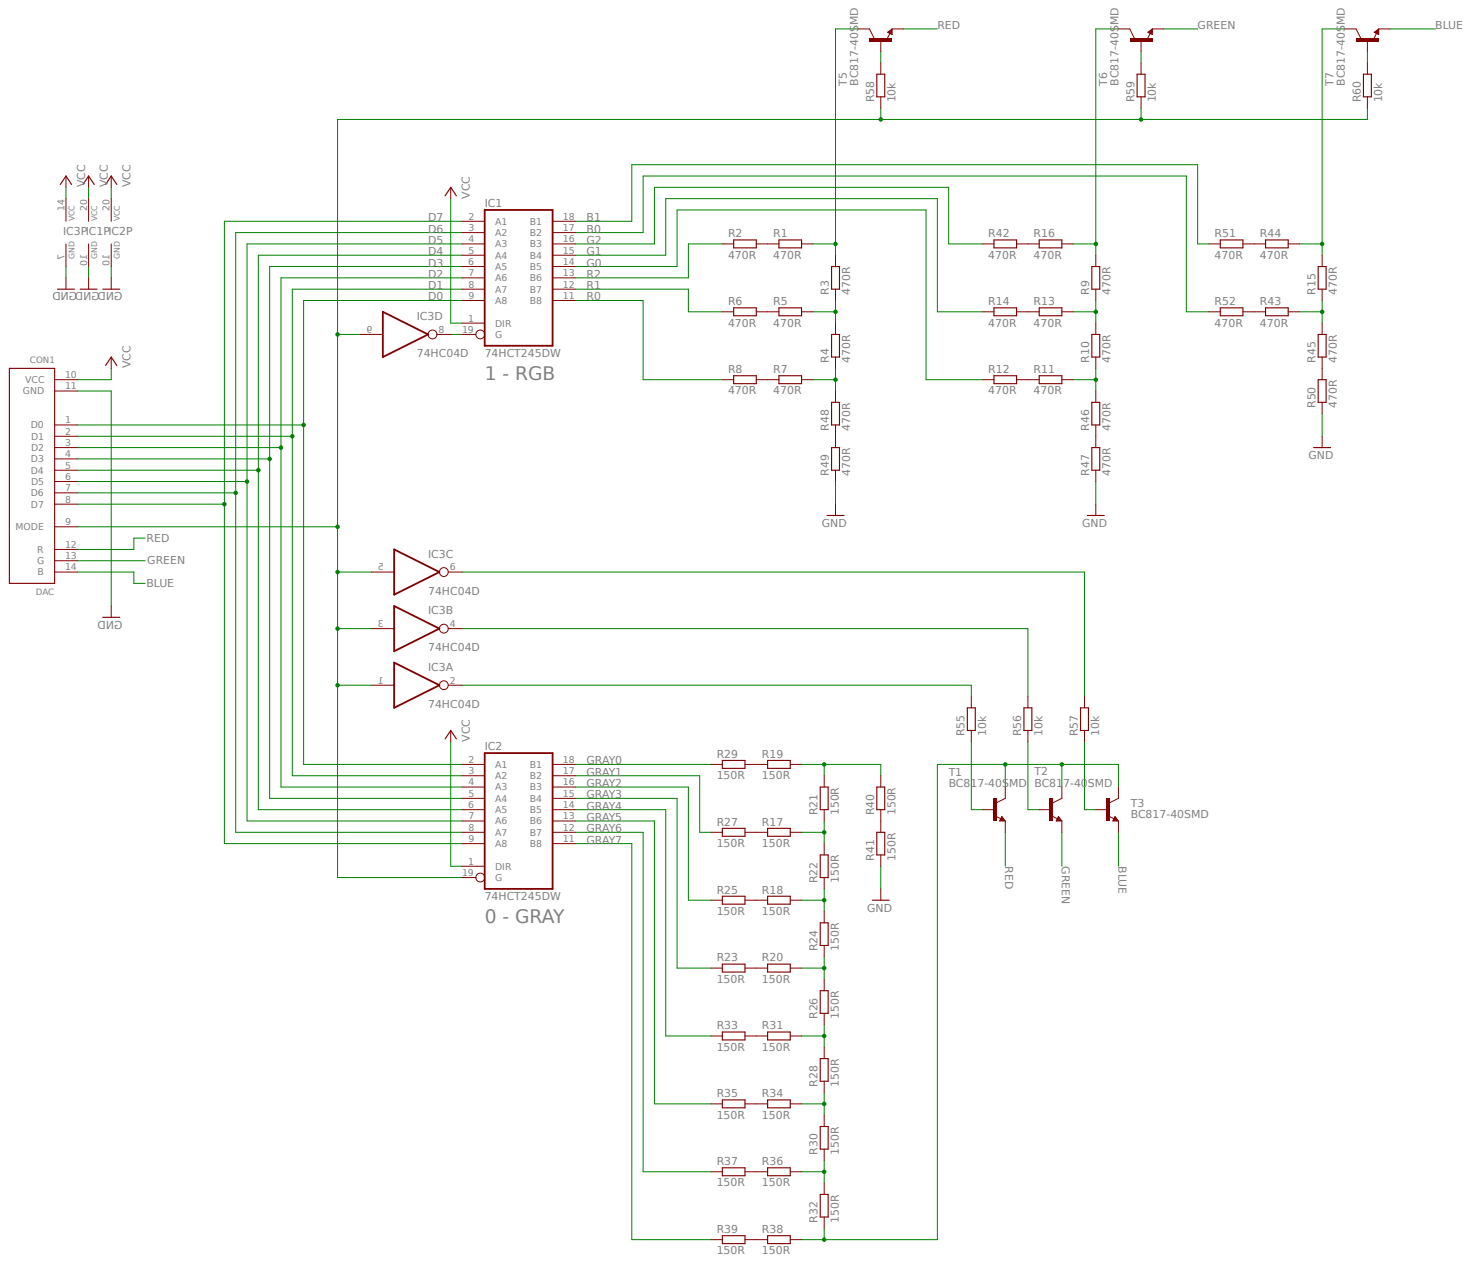
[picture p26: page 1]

D6 | 3 | B0
D5 | 4 | G2

D2 | 7 | R2
D1 | 8 | R1
D0 | 9 | R0

9 | GRAY7

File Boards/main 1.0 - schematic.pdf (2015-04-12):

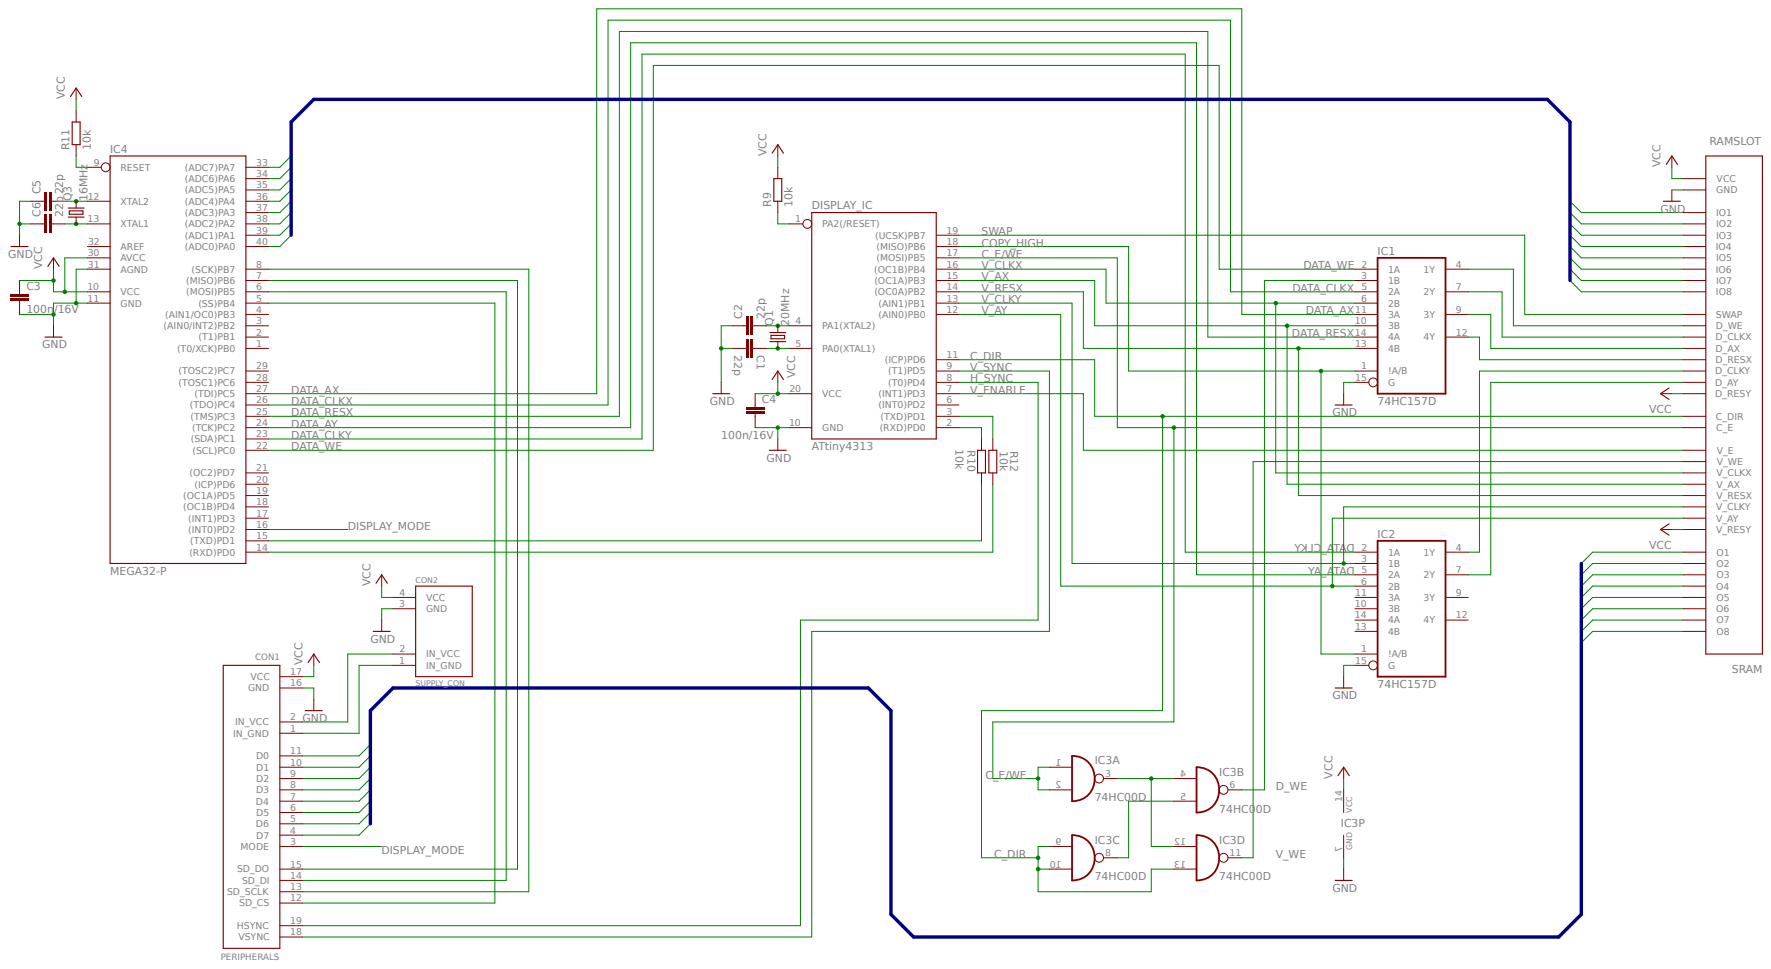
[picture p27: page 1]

DATA_CLKY
DATA_WE

DISPLAY_MODE

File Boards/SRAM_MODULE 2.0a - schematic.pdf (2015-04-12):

## **OPTIONAL** RAM copy interface

# DUAL SRAM SWAPPER V2.0a

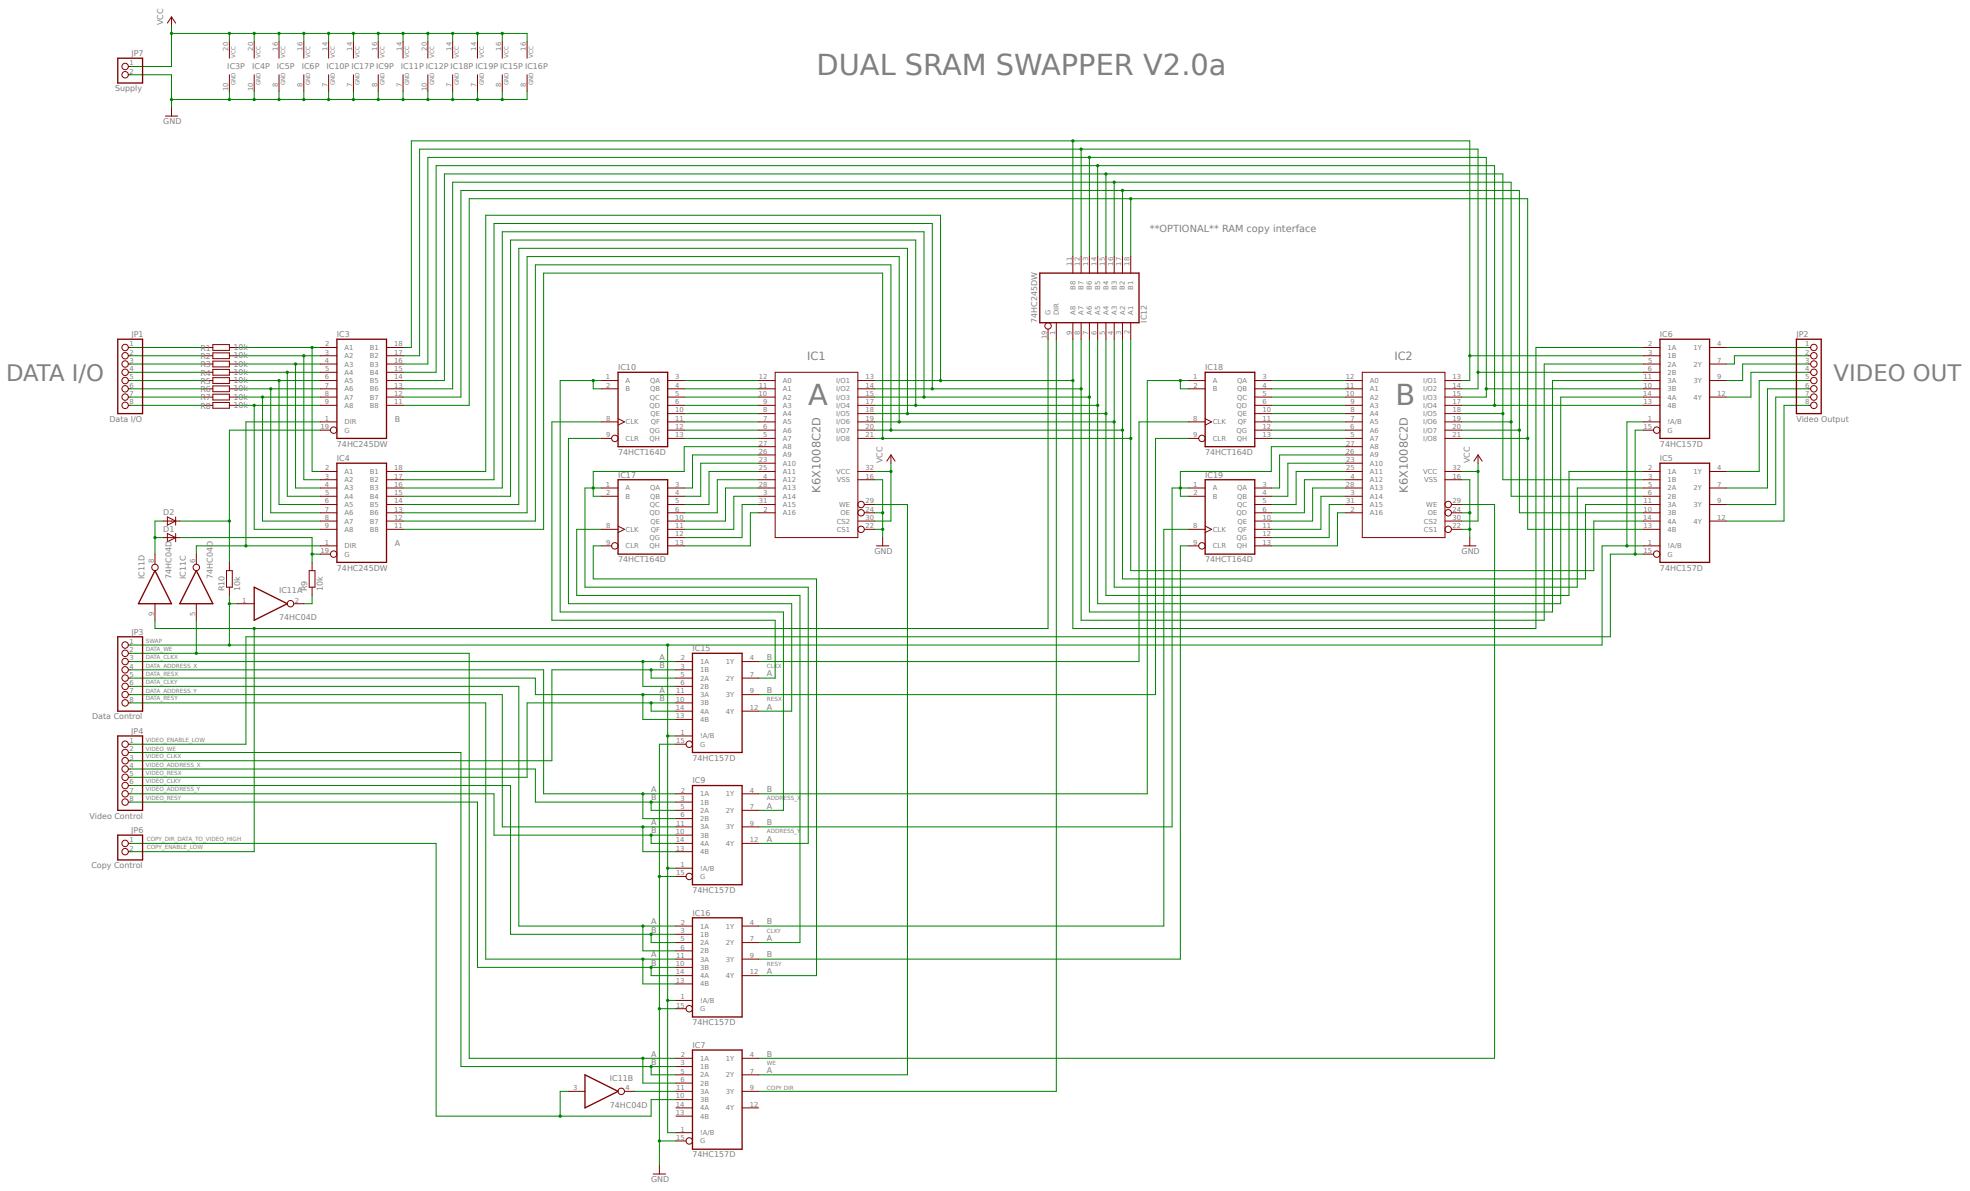
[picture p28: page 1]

B | RESX A
4A 14

B | RESY A

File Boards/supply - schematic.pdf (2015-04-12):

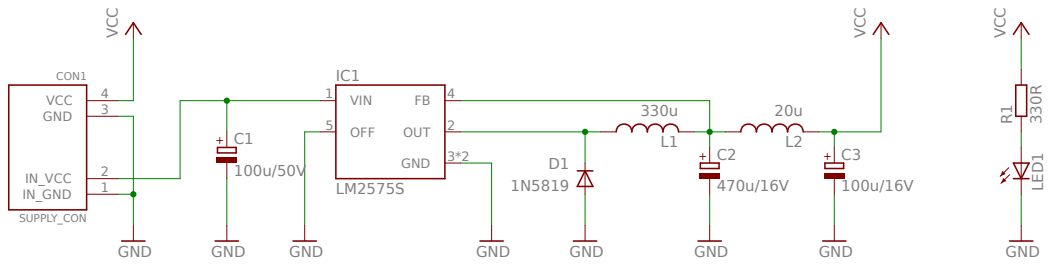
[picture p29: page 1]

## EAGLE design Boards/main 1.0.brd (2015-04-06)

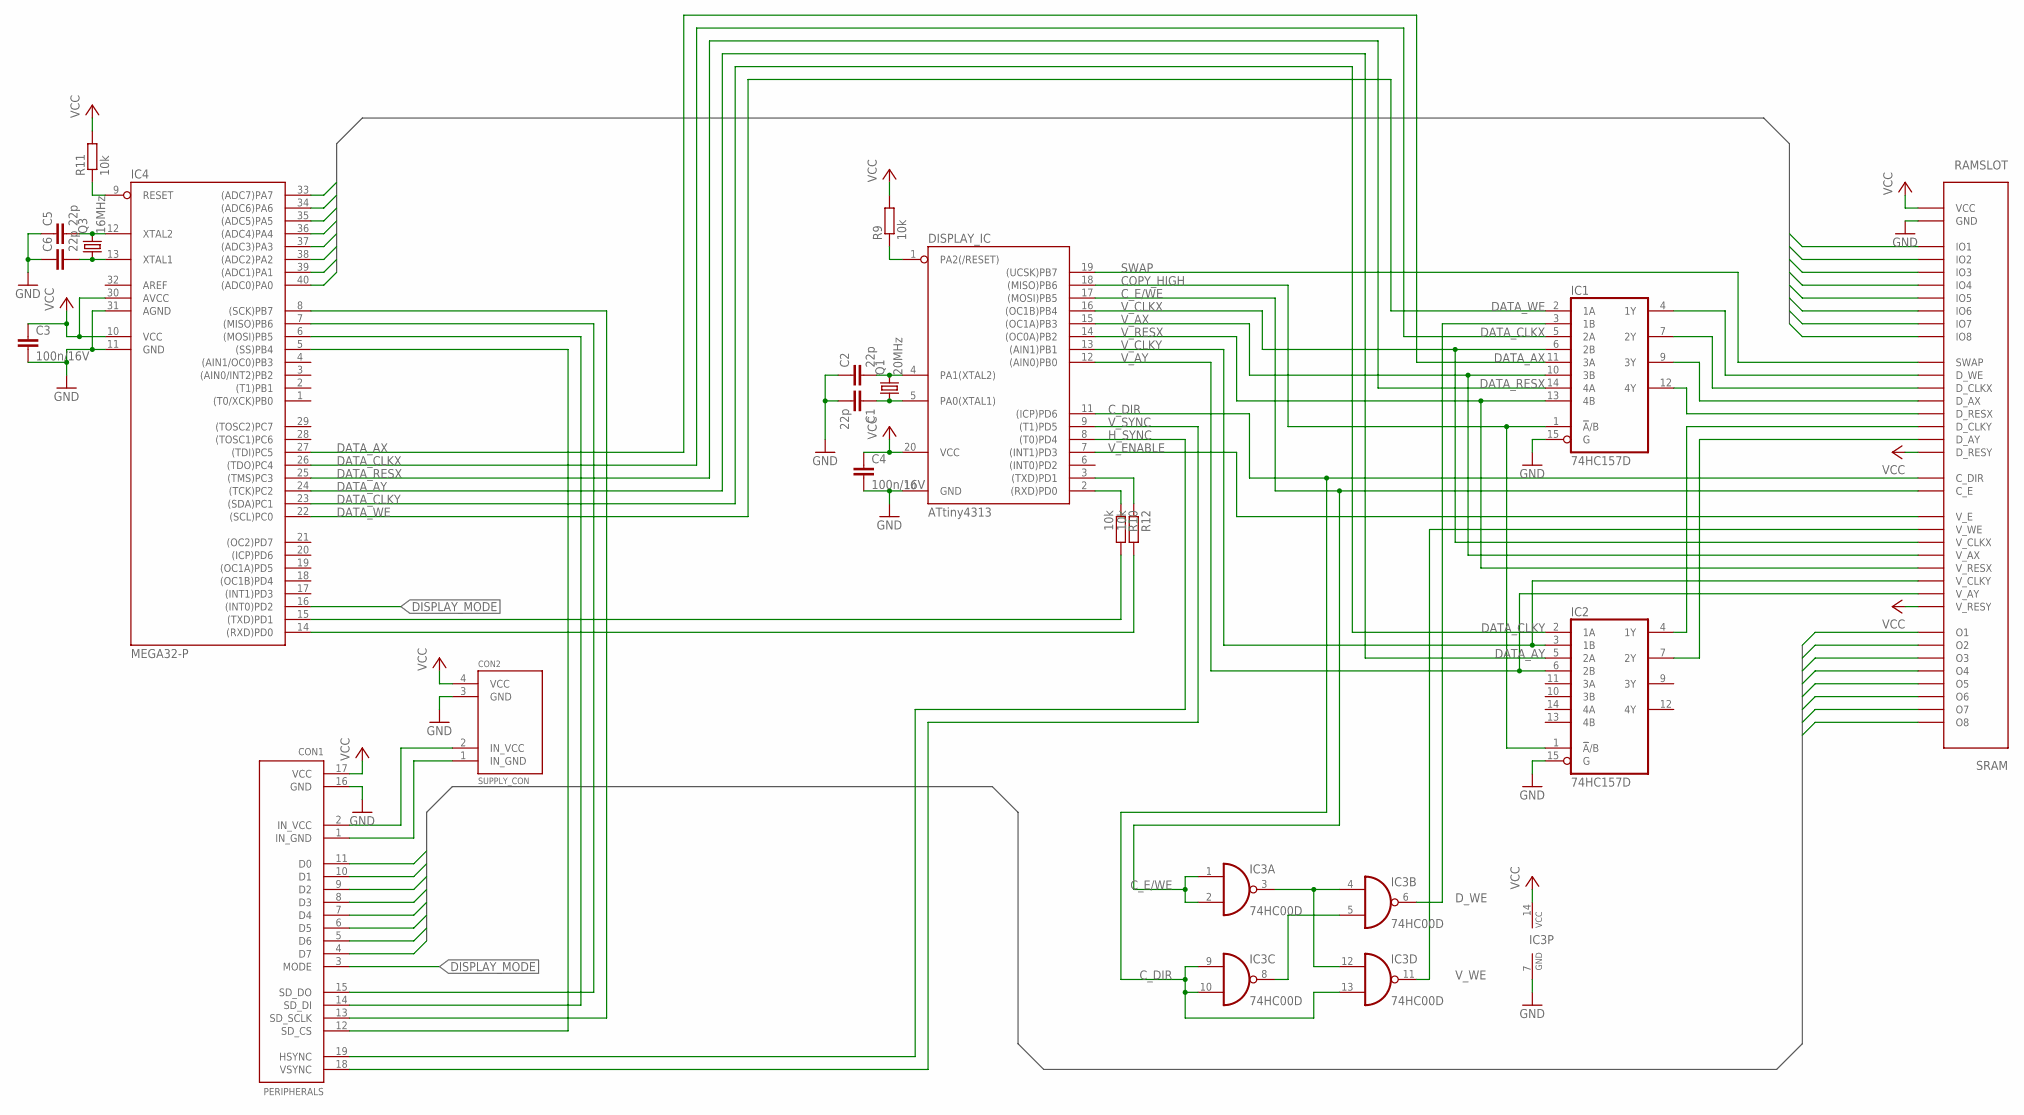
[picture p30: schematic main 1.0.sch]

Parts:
C1, C2, C5, C6: 22p; C0603
C3, C4: 100n/16V; C0603
CON1: PERIPHERALS; PERIPHERALS_CON
CON2: SUPPLY_CON
DISPLAY_IC: ATtiny4313; DIL20
IC1, IC2: 74HC157D; SO16
IC3: 74HC00D; SO14
IC4: MEGA32-P; DIL40
Q1: 20MHz; HC49
Q3: 16MHz; HC49
R9, R10, R11, R12: 10k; R0603
RAMSLOT: SRAM; SLOT

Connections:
AREF: IC4.32 (AREF)
COPY_HIGH: DISPLAY_IC.18 ((MISO)PB6), IC1.1 (!A!/B), IC2.1 (!A!/B)
C_DIR: DISPLAY_IC.11 ((ICP)PD6), IC3.9 (I0), IC3.10 (I1), IC3.13 (I1), RAMSLOT.C_DIR, RAMSLOT.C_DIRB (C_DIR)
C_E/WE: DISPLAY_IC.17 ((MOSI)PB5), IC3.1 (I0), IC3.2 (I1), RAMSLOT.C_E, RAMSLOT.C_EB (C_E)
DATA0: IC4.40 ((ADC0)PA0), RAMSLOT.IO1, RAMSLOT.IO1B (IO1)
DATA1: IC4.39 ((ADC1)PA1), RAMSLOT.IO2, RAMSLOT.IO2B (IO2)
DATA2: IC4.38 ((ADC2)PA2), RAMSLOT.IO3, RAMSLOT.IO3B (IO3)
DATA3: IC4.37 ((ADC3)PA3), RAMSLOT.IO4, RAMSLOT.IO4B (IO4)
DATA4: IC4.36 ((ADC4)PA4), RAMSLOT.IO5, RAMSLOT.IO5B (IO5)
DATA5: IC4.35 ((ADC5)PA5), RAMSLOT.IO6, RAMSLOT.IO6B (IO6)
DATA6: IC4.34 ((ADC6)PA6), RAMSLOT.IO7, RAMSLOT.IO7B (IO7)
DATA7: IC4.33 ((ADC7)PA7), RAMSLOT.IO8, RAMSLOT.IO8B (IO8)
DATA_AX: IC1.11 (3A), IC4.27 ((TDI)PC5)
DATA_AY: IC2.5 (2A), IC4.24 ((TCK)PC2)
DATA_CLKX: IC1.5 (2A), IC4.26 ((TDO)PC4)
DATA_CLKY: IC2.2 (1A), IC4.23 ((SDA)PC1)
DATA_RESX: IC1.14 (4A), IC4.25 ((TMS)PC3)
DATA_WE: IC1.2 (1A), IC4.22 ((SCL)PC0)
DISPLAY_MODE: CON1.3 (MODE), IC4.16 ((INT0)PD2)
D_WE: IC1.3 (1B), IC3.6 (O)
GND: C1.2, C2.1, C3.2, C4.2, C5.1, C6.1, CON1.16 (GND), CON2.3 (GND), DISPLAY_IC.10 (GND), IC1.8 (GND), IC1.15 (G), IC2.8 (GND), IC2.15 (G), IC3.7 (GND), IC4.11 (GND), IC4.31 (AGND), RAMSLOT.GND, RAMSLOT.GNDB (GND)
H_SYNC: CON1.19 (HSYNC), DISPLAY_IC.8 ((T0)PD4)
IN_GND: CON1.1 (IN_GND), CON2.1 (IN_GND)
MAIN_RX: IC4.14 ((RXD)PD0), R12.2
MAIN_TX: IC4.15 ((TXD)PD1), R10.2
unnamed: IC4.9 (RESET), R11.1
unnamed: IC3.3 (O), IC3.4 (I0), IC3.12 (I0)
unnamed: IC3.5 (I1), IC3.8 (O)
unnamed: CON1.2 (IN_VCC), CON2.2 (IN_VCC)
unnamed: DISPLAY_IC.1 (PA2(/RESET)), R9.1
unnamed: DISPLAY_IC.3 ((TXD)PD1), R12.1
unnamed: C5.2, IC4.12 (XTAL2), Q3.2
unnamed: C6.2, IC4.13 (XTAL1), Q3.1
unnamed: DISPLAY_IC.2 ((RXD)PD0), R10.1
unnamed: C1.1, DISPLAY_IC.5 (PA0(XTAL1)), Q1.1
unnamed: C2.2, DISPLAY_IC.4 (PA1(XTAL2)), Q1.2
unnamed: IC1.4 (1Y), RAMSLOT.D_WE, RAMSLOT.D_WEB (D_WE)
unnamed: IC1.7 (2Y), RAMSLOT.D_CLKX, RAMSLOT.D_CLKXB (D_CLKX)
unnamed: IC1.9 (3Y), RAMSLOT.D_AX, RAMSLOT.D_AXB (D_AX)
unnamed: IC1.12 (4Y), RAMSLOT.D_RESX, RAMSLOT.D_RESXB (D_RESX)
unnamed: IC2.4 (1Y), RAMSLOT.D_CLKY, RAMSLOT.D_CLKYB (D_CLKY)
unnamed: IC2.7 (2Y), RAMSLOT.D_AY, RAMSLOT.D_AYB (D_AY)
O0: CON1.11 (D0), RAMSLOT.O1, RAMSLOT.O1B (O1)
O1: CON1.10 (D1), RAMSLOT.O2, RAMSLOT.O2B (O2)
O2: CON1.9 (D2), RAMSLOT.O3, RAMSLOT.O3B (O3)
O3: CON1.8 (D3), RAMSLOT.O4, RAMSLOT.O4B (O4)
O4: CON1.7 (D4), RAMSLOT.O5, RAMSLOT.O5B (O5)
O5: CON1.6 (D5), RAMSLOT.O6, RAMSLOT.O6B (O6)
O6: CON1.5 (D6), RAMSLOT.O7, RAMSLOT.O7B (O7)
O7: CON1.4 (D7), RAMSLOT.O8, RAMSLOT.O8B (O8)
SD_CS: CON1.12 (SD_CS), IC4.5 ((SS)PB4)
SD_DI: CON1.14 (SD_DI), IC4.6 ((MOSI)PB5)
SD_DO: CON1.15 (SD_DO), IC4.7 ((MISO)PB6)
SD_SCLK: CON1.13 (SD_SCLK), IC4.8 ((SCK)PB7)
SWAP: DISPLAY_IC.19 ((UCSK)PB7), RAMSLOT.SWAP, RAMSLOT.SWAPB (SWAP)
VCC: C3.1, C4.1, CON1.17 (VCC), CON2.4 (VCC), DISPLAY_IC.20 (VCC), IC1.16 (VCC), IC2.16 (VCC), IC3.14 (VCC), IC4.10 (VCC), IC4.30 (AVCC), R9.2, R11.2, RAMSLOT.D_RESY, RAMSLOT.D_RESYB (D_RESY), RAMSLOT.VCC, RAMSLOT.VCCB (VCC), RAMSLOT.V_RESY, RAMSLOT.V_RESYB (V_RESY)
V_AX: DISPLAY_IC.15 ((OC1A)PB3), IC1.10 (3B), RAMSLOT.V_AX, RAMSLOT.V_AXB (V_AX)
V_AY: DISPLAY_IC.12 ((AIN0)PB0), IC2.6 (2B), RAMSLOT.V_AY, RAMSLOT.V_AYB (V_AY)
V_CLKX: DISPLAY_IC.16 ((OC1B)PB4), IC1.6 (2B), RAMSLOT.V_CLKX, RAMSLOT.V_CLKXB (V_CLKX)
V_CLKY: DISPLAY_IC.13 ((AIN1)PB1), IC2.3 (1B), RAMSLOT.V_CLKY, RAMSLOT.V_CLKYB (V_CLKY)
V_ENABLE: DISPLAY_IC.7 ((INT1)PD3), RAMSLOT.V_E, RAMSLOT.V_EB (V_E)
V_RESX: DISPLAY_IC.14 ((OC0A)PB2), IC1.13 (4B), RAMSLOT.V_RESX, RAMSLOT.V_RESXB (V_RESX)
V_SYNC: CON1.18 (VSYNC), DISPLAY_IC.9 ((T1)PD5)
V_WE: IC3.11 (O), RAMSLOT.V_WE, RAMSLOT.V_WEB (V_WE)

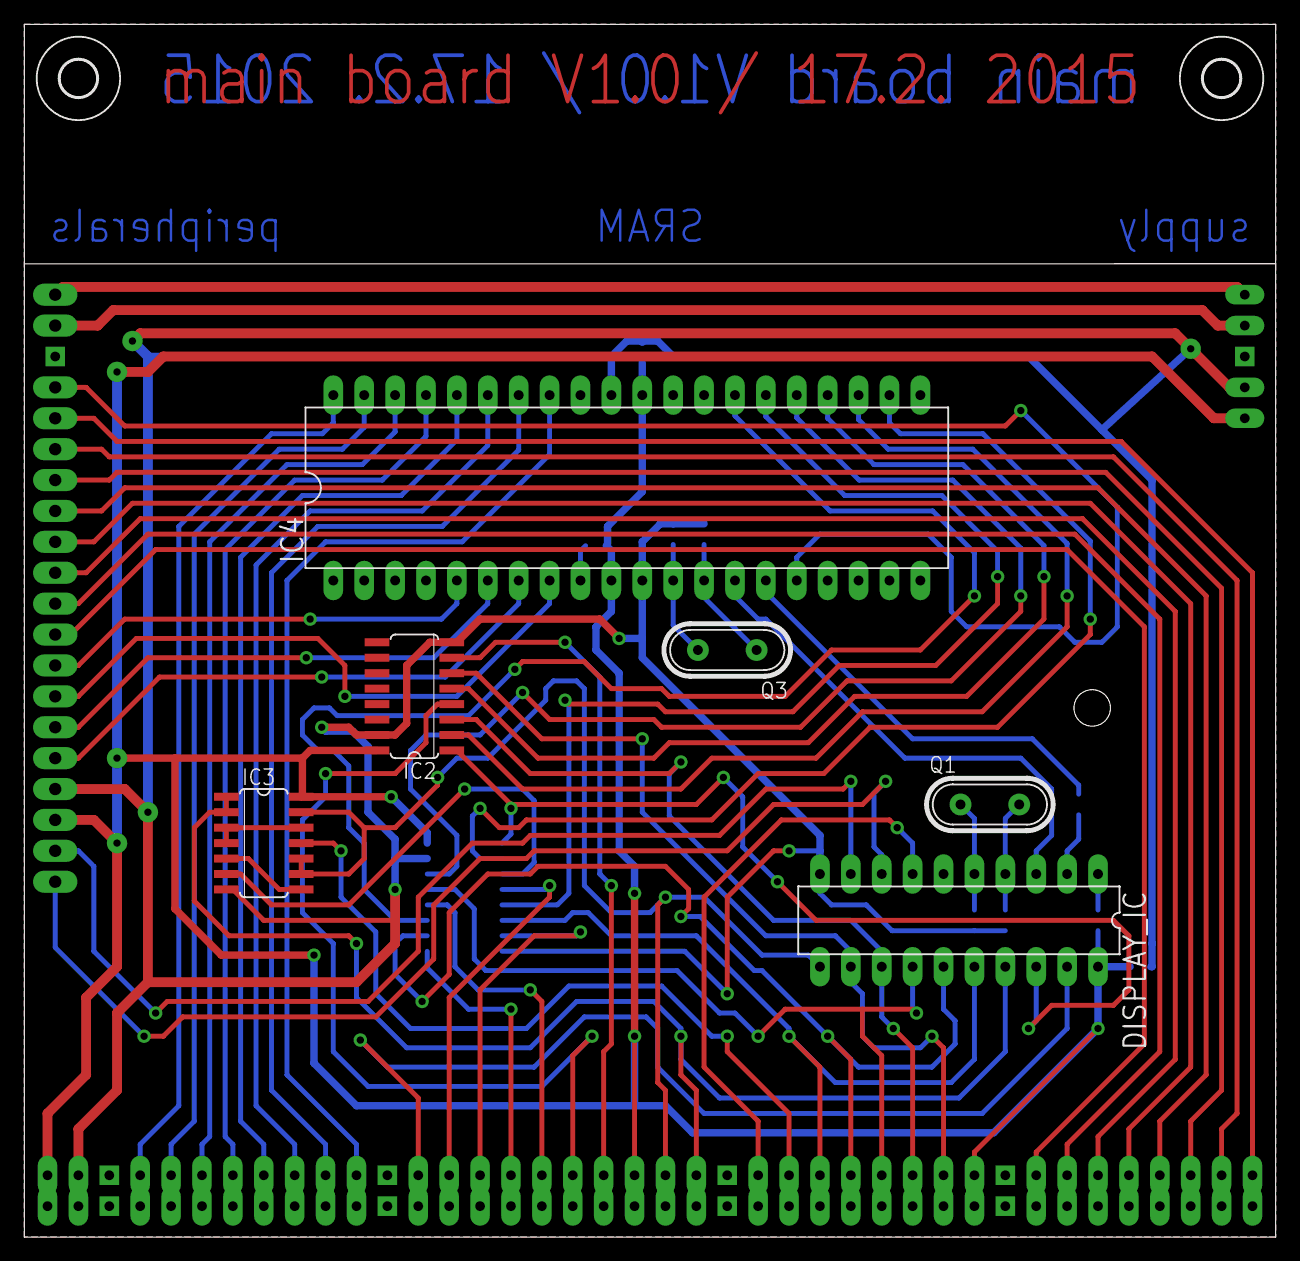
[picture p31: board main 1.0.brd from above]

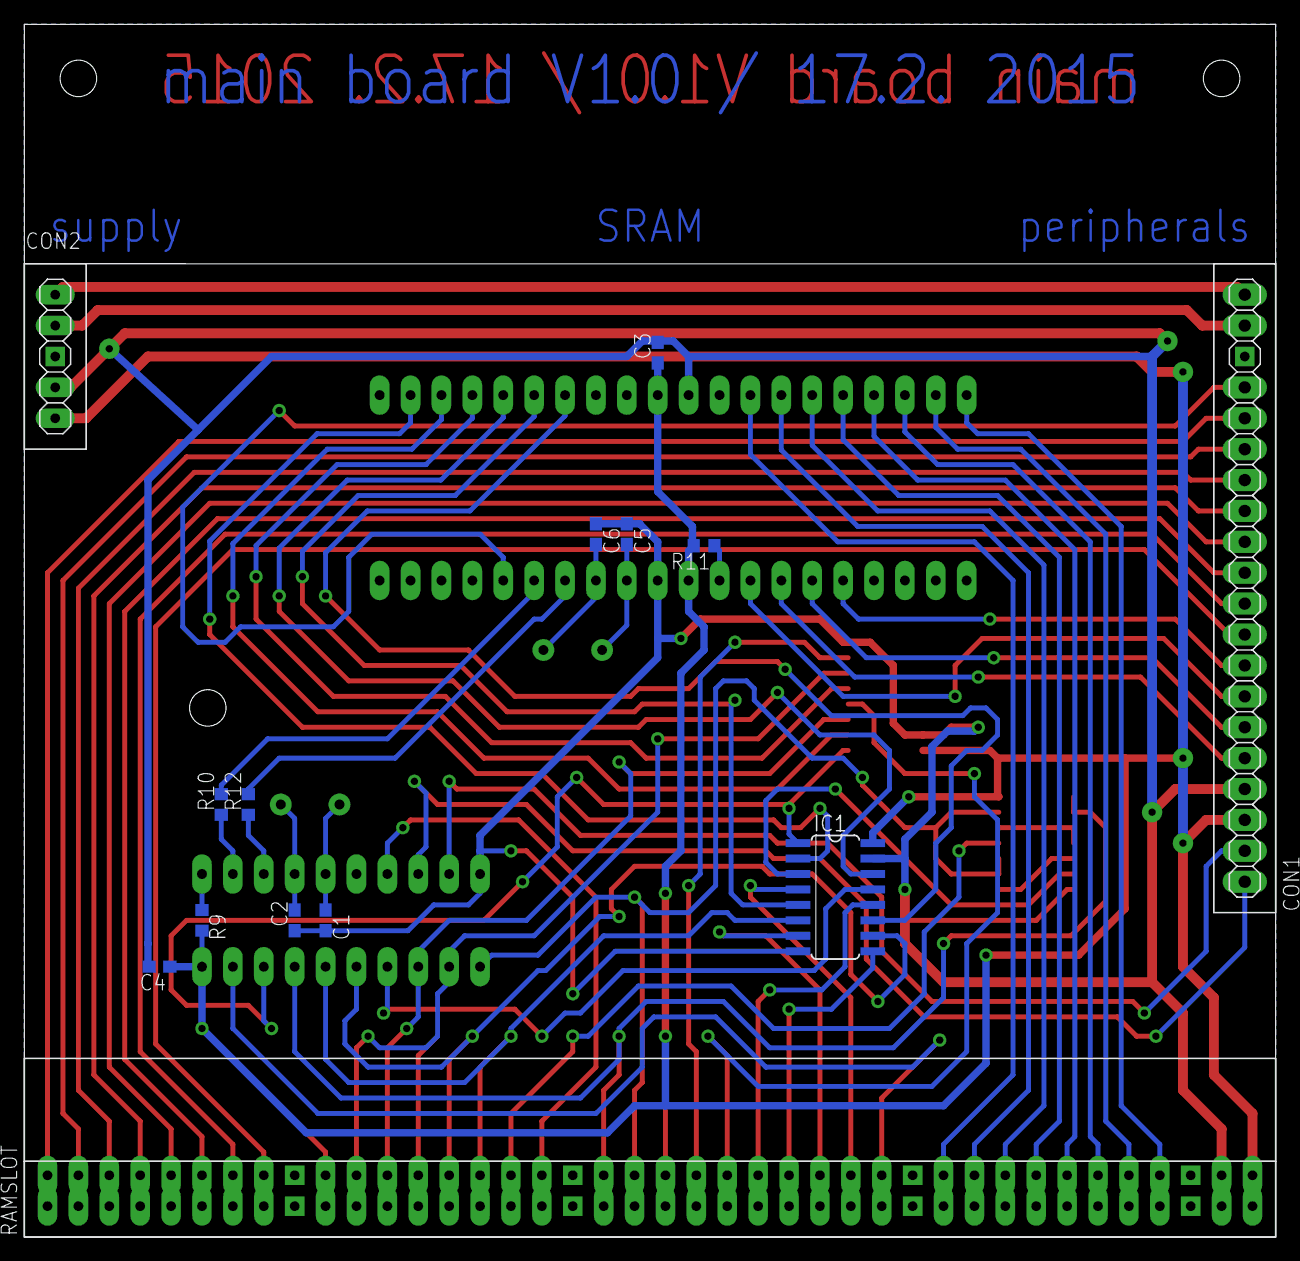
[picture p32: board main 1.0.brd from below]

Board: 2 copper layers, 102.9 x 99.7 mm, 22 parts (14 on the bottom side), 63 nets.

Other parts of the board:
U$1, U$2: 3,0

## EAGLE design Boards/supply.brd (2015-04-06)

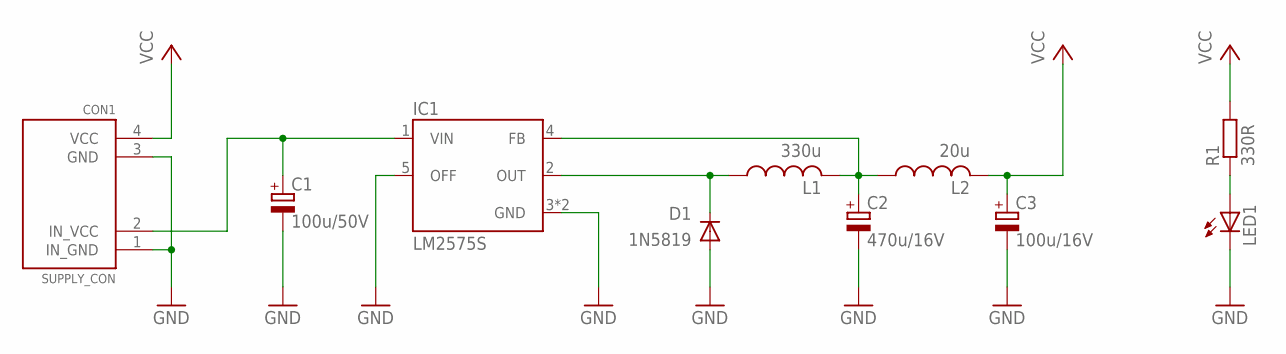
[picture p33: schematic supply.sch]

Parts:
C1: 100u/50V; E3,5-8
C2: 470u/16V; E5-10,5
C3: 100u/16V; E2,5-6
CON1: SUPPLY_CON
D1: 1N5819; DO41-10
IC1: LM2575S; TO263-5
L1: 330u; COIL
L2: 20u; COIL
LED1: LEDSML1206; SML1206
R1: 330R; R0603

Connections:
GND: C1.-, C2.-, C3.-, CON1.1 (IN_GND), CON1.3 (GND), D1.A, IC1.3 (GND), IC1.5 (OFF), IC1.6 (GND), LED1.C
IN_VCC: C1.+, CON1.2 (IN_VCC), IC1.1 (VIN)
unnamed: C2.+, IC1.4 (FB), L1.P$2, L2.P$1
unnamed: LED1.A, R1.1
unnamed: D1.C, IC1.2 (OUT), L1.P$1
VCC: C3.+, CON1.4 (VCC), L2.P$2, R1.2

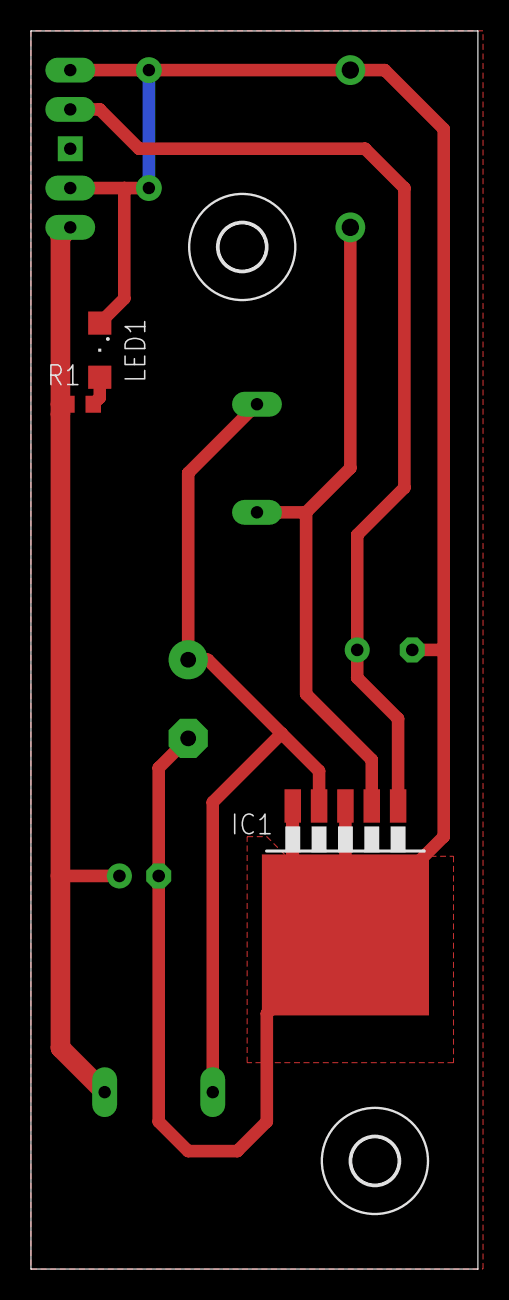
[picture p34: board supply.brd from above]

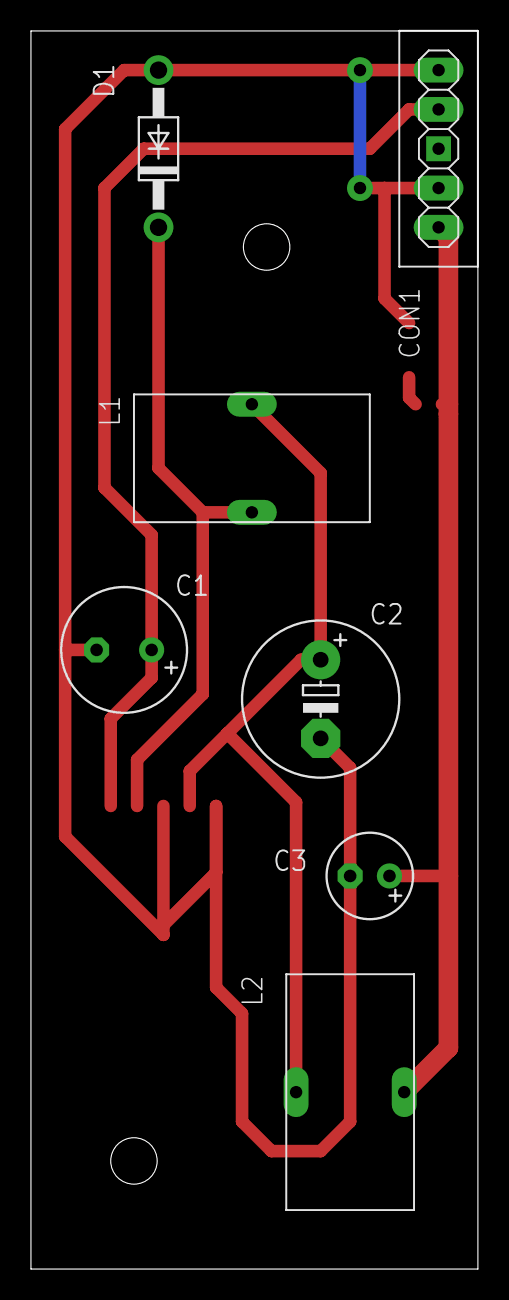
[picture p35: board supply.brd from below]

Board: 2 copper layers, 28.9 x 80.0 mm, 12 parts (7 on the bottom side), 6 nets.

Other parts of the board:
U$1, U$2: 3,0

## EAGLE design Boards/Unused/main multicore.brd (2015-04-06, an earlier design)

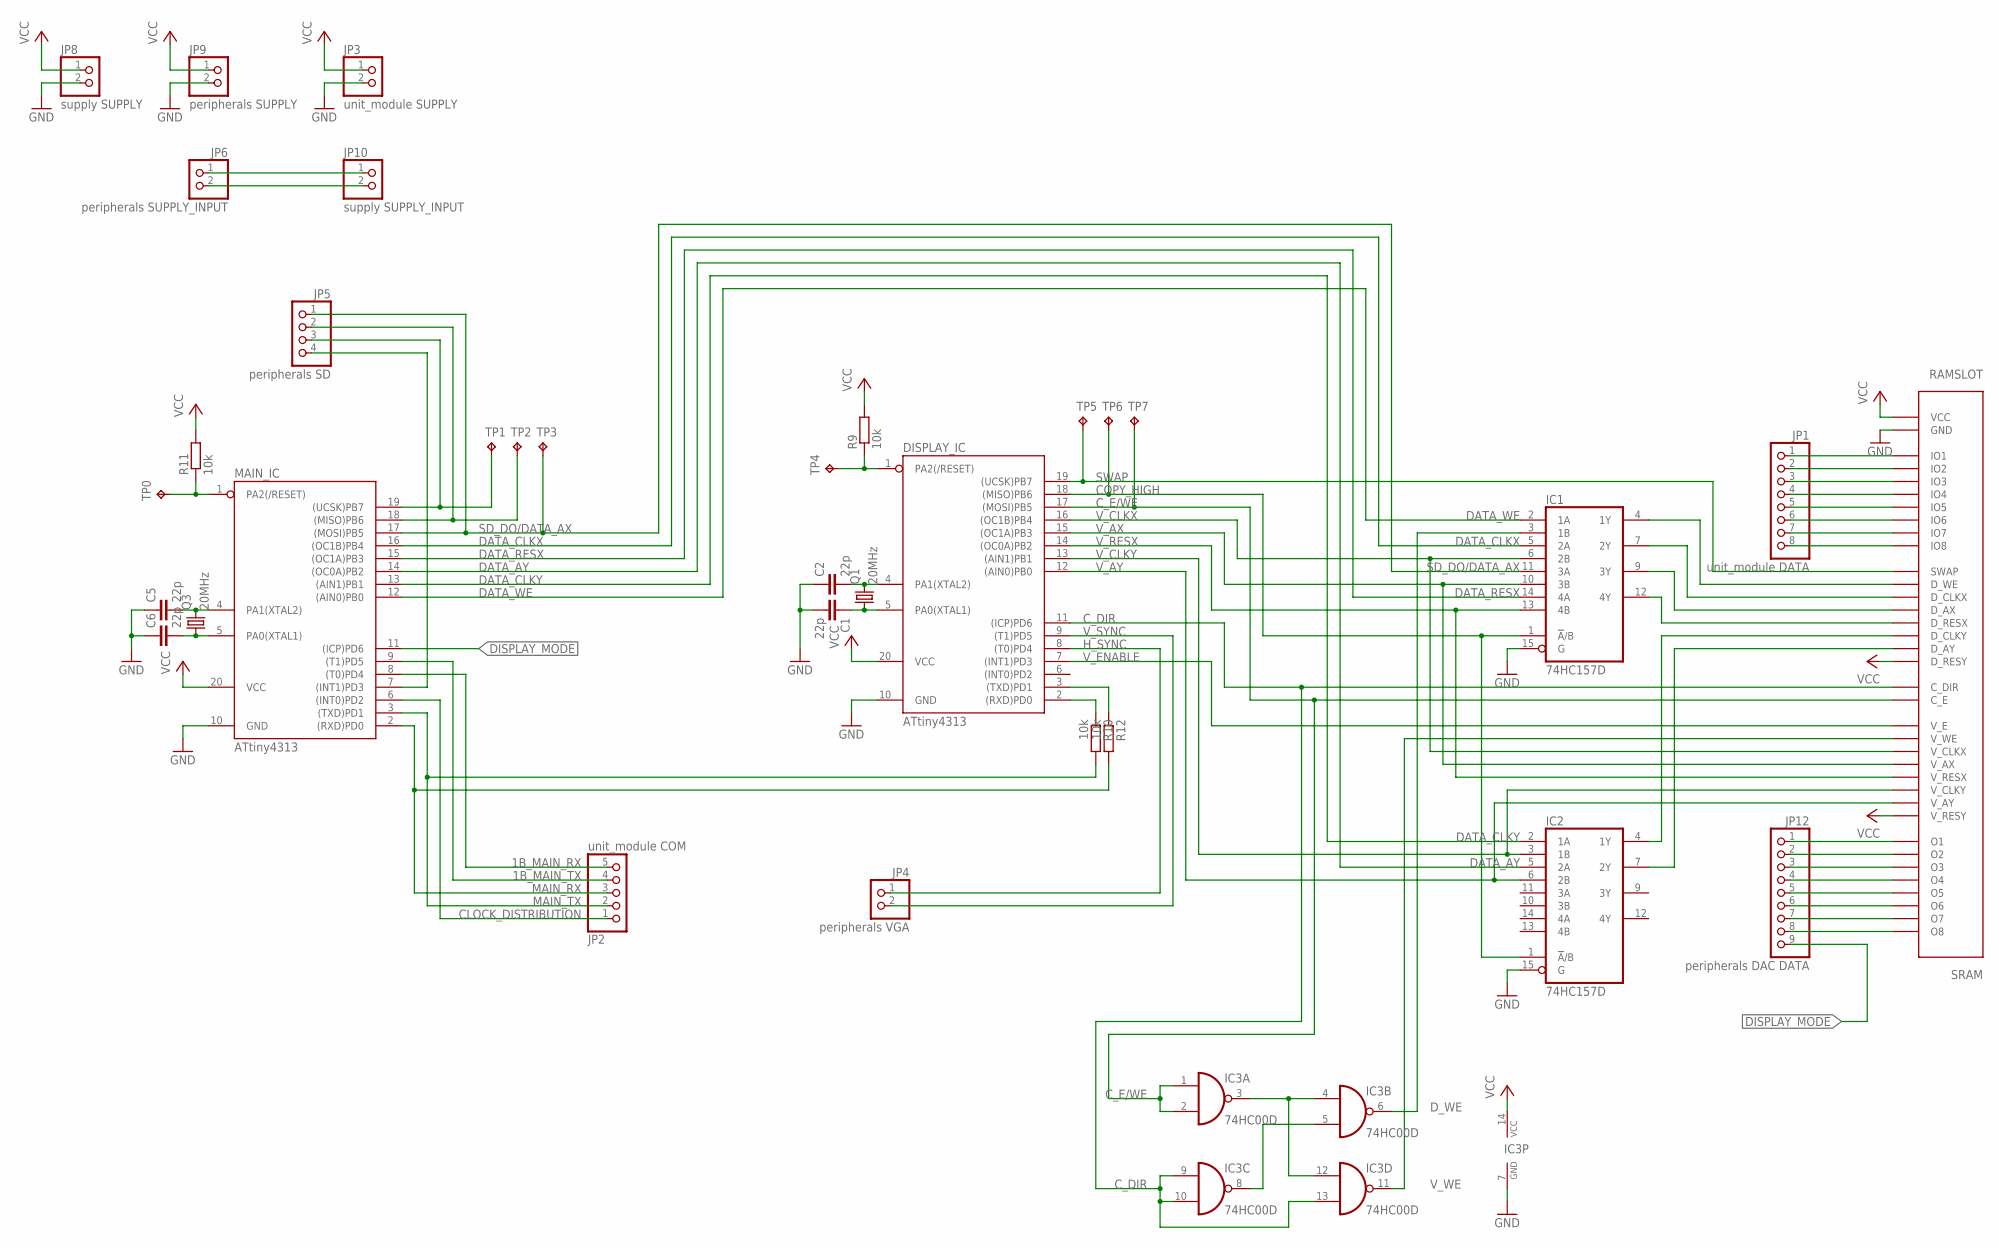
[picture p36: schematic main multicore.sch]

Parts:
C1, C2, C5, C6: 22p; C0402
DISPLAY_IC: ATtiny4313; SO20L$
IC1, IC2: 74HC157D; SO16
IC3: 74HC00D; SO14
JP1: unit_module DATA; 1X08
JP2: unit_module COM; 1X05
JP3: unit_module SUPPLY; 1X02
JP4: peripherals VGA; 1X02
JP5: peripherals SD; 1X04
JP6: peripherals SUPPLY_INPUT; 1X02
JP8: supply SUPPLY; 1X02
JP9: peripherals SUPPLY; 1X02
JP10: supply SUPPLY_INPUT; 1X02
JP12: peripherals DAC DATA; 1X09
MAIN_IC: ATtiny4313; SO20L$
Q1, Q3: 20MHz; MC-405
R9, R10, R11, R12: 10k; R0603
RAMSLOT: SRAM; SLOT
TP0, TP1, TP2, TP3, TP4, TP5, TP6, TP7: TPB1,27; B1,27

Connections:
1B_MAIN_RX: JP2.5, MAIN_IC.8 ((T0)PD4)
1B_MAIN_TX: JP2.4, MAIN_IC.9 ((T1)PD5)
CLOCK_DISTRIBUTION: JP2.1, MAIN_IC.6 ((INT0)PD2)
COPY_HIGH: DISPLAY_IC.18 ((MISO)PB6), IC1.1 (!A!/B), IC2.1 (!A!/B), TP6.TP
C_DIR: DISPLAY_IC.11 ((ICP)PD6), IC3.9 (I0), IC3.10 (I1), IC3.13 (I1), RAMSLOT.C_DIR
C_E/WE: DISPLAY_IC.17 ((MOSI)PB5), IC3.1 (I0), IC3.2 (I1), RAMSLOT.C_E, TP7.TP
DATA_AY: IC2.5 (2A), MAIN_IC.14 ((OC0A)PB2)
DATA_CLKX: IC1.5 (2A), MAIN_IC.16 ((OC1B)PB4)
DATA_CLKY: IC2.2 (1A), MAIN_IC.13 ((AIN1)PB1)
DATA_RESX: IC1.14 (4A), MAIN_IC.15 ((OC1A)PB3)
DATA_WE: IC1.2 (1A), MAIN_IC.12 ((AIN0)PB0)
DISPLAY_MODE: JP12.9, MAIN_IC.11 ((ICP)PD6)
D_WE: IC1.3 (1B), IC3.6 (O)
GND: C1.2, C2.1, C5.1, C6.1, DISPLAY_IC.10 (GND), IC1.8 (GND), IC1.15 (G), IC2.8 (GND), IC2.15 (G), IC3.7 (GND), JP3.2, JP8.2, JP9.2, MAIN_IC.10 (GND), RAMSLOT.GND
H_SYNC: DISPLAY_IC.8 ((T0)PD4), JP4.1
IN_GND: JP6.2, JP10.2
IN_VCC: JP6.1, JP10.1
MAIN_RX: JP2.3, MAIN_IC.2 ((RXD)PD0), R12.2
MAIN_TX: JP2.2, MAIN_IC.3 ((TXD)PD1), R10.2
unnamed: IC3.3 (O), IC3.4 (I0), IC3.12 (I0)
unnamed: IC3.5 (I1), IC3.8 (O)
unnamed: JP1.1, RAMSLOT.IO1
unnamed: DISPLAY_IC.1 (PA2(/RESET)), R9.1, TP4.TP
unnamed: JP1.2, RAMSLOT.IO2
unnamed: JP1.3, RAMSLOT.IO3
unnamed: DISPLAY_IC.3 ((TXD)PD1), R12.1
unnamed: C5.2, MAIN_IC.4 (PA1(XTAL2)), Q3.2
unnamed: C6.2, MAIN_IC.5 (PA0(XTAL1)), Q3.1
unnamed: MAIN_IC.1 (PA2(/RESET)), R11.1, TP0.TP
unnamed: JP1.4, RAMSLOT.IO4
unnamed: JP1.5, RAMSLOT.IO5
unnamed: JP1.6, RAMSLOT.IO6
unnamed: JP1.7, RAMSLOT.IO7
unnamed: JP1.8, RAMSLOT.IO8
unnamed: DISPLAY_IC.2 ((RXD)PD0), R10.1
unnamed: C1.1, DISPLAY_IC.5 (PA0(XTAL1)), Q1.1
unnamed: C2.2, DISPLAY_IC.4 (PA1(XTAL2)), Q1.2
unnamed: JP12.1, RAMSLOT.O1
unnamed: JP12.2, RAMSLOT.O2
unnamed: JP12.3, RAMSLOT.O3
unnamed: JP12.4, RAMSLOT.O4
unnamed: JP12.5, RAMSLOT.O5
unnamed: JP12.6, RAMSLOT.O6
unnamed: JP12.7, RAMSLOT.O7
unnamed: JP12.8, RAMSLOT.O8
unnamed: IC1.4 (1Y), RAMSLOT.D_WE
unnamed: IC1.7 (2Y), RAMSLOT.D_CLKX
unnamed: IC1.9 (3Y), RAMSLOT.D_AX
unnamed: IC1.12 (4Y), RAMSLOT.D_RESX
unnamed: IC2.4 (1Y), RAMSLOT.D_CLKY
unnamed: IC2.7 (2Y), RAMSLOT.D_AY
SD_CS: JP5.4, MAIN_IC.7 ((INT1)PD3)
SD_DI: JP5.2, MAIN_IC.18 ((MISO)PB6), TP2.TP
SD_DO/DATA_AX: IC1.11 (3A), JP5.1, MAIN_IC.17 ((MOSI)PB5), TP3.TP
SD_SCLK: JP5.3, MAIN_IC.19 ((UCSK)PB7), TP1.TP
SWAP: DISPLAY_IC.19 ((UCSK)PB7), RAMSLOT.SWAP, TP5.TP
VCC: DISPLAY_IC.20 (VCC), IC1.16 (VCC), IC2.16 (VCC), IC3.14 (VCC), JP3.1, JP8.1, JP9.1, MAIN_IC.20 (VCC), R9.2, R11.2, RAMSLOT.D_RESY, RAMSLOT.VCC, RAMSLOT.V_RESY
V_AX: DISPLAY_IC.15 ((OC1A)PB3), IC1.10 (3B), RAMSLOT.V_AX
V_AY: DISPLAY_IC.12 ((AIN0)PB0), IC2.6 (2B), RAMSLOT.V_AY
V_CLKX: DISPLAY_IC.16 ((OC1B)PB4), IC1.6 (2B), RAMSLOT.V_CLKX
V_CLKY: DISPLAY_IC.13 ((AIN1)PB1), IC2.3 (1B), RAMSLOT.V_CLKY
V_ENABLE: DISPLAY_IC.7 ((INT1)PD3), RAMSLOT.V_E
V_RESX: DISPLAY_IC.14 ((OC0A)PB2), IC1.13 (4B), RAMSLOT.V_RESX
V_SYNC: DISPLAY_IC.9 ((T1)PD5), JP4.2
V_WE: IC3.11 (O), RAMSLOT.V_WE

Board: 2 copper layers, 34 parts (0 on the bottom side), 65 nets, no tracks yet.

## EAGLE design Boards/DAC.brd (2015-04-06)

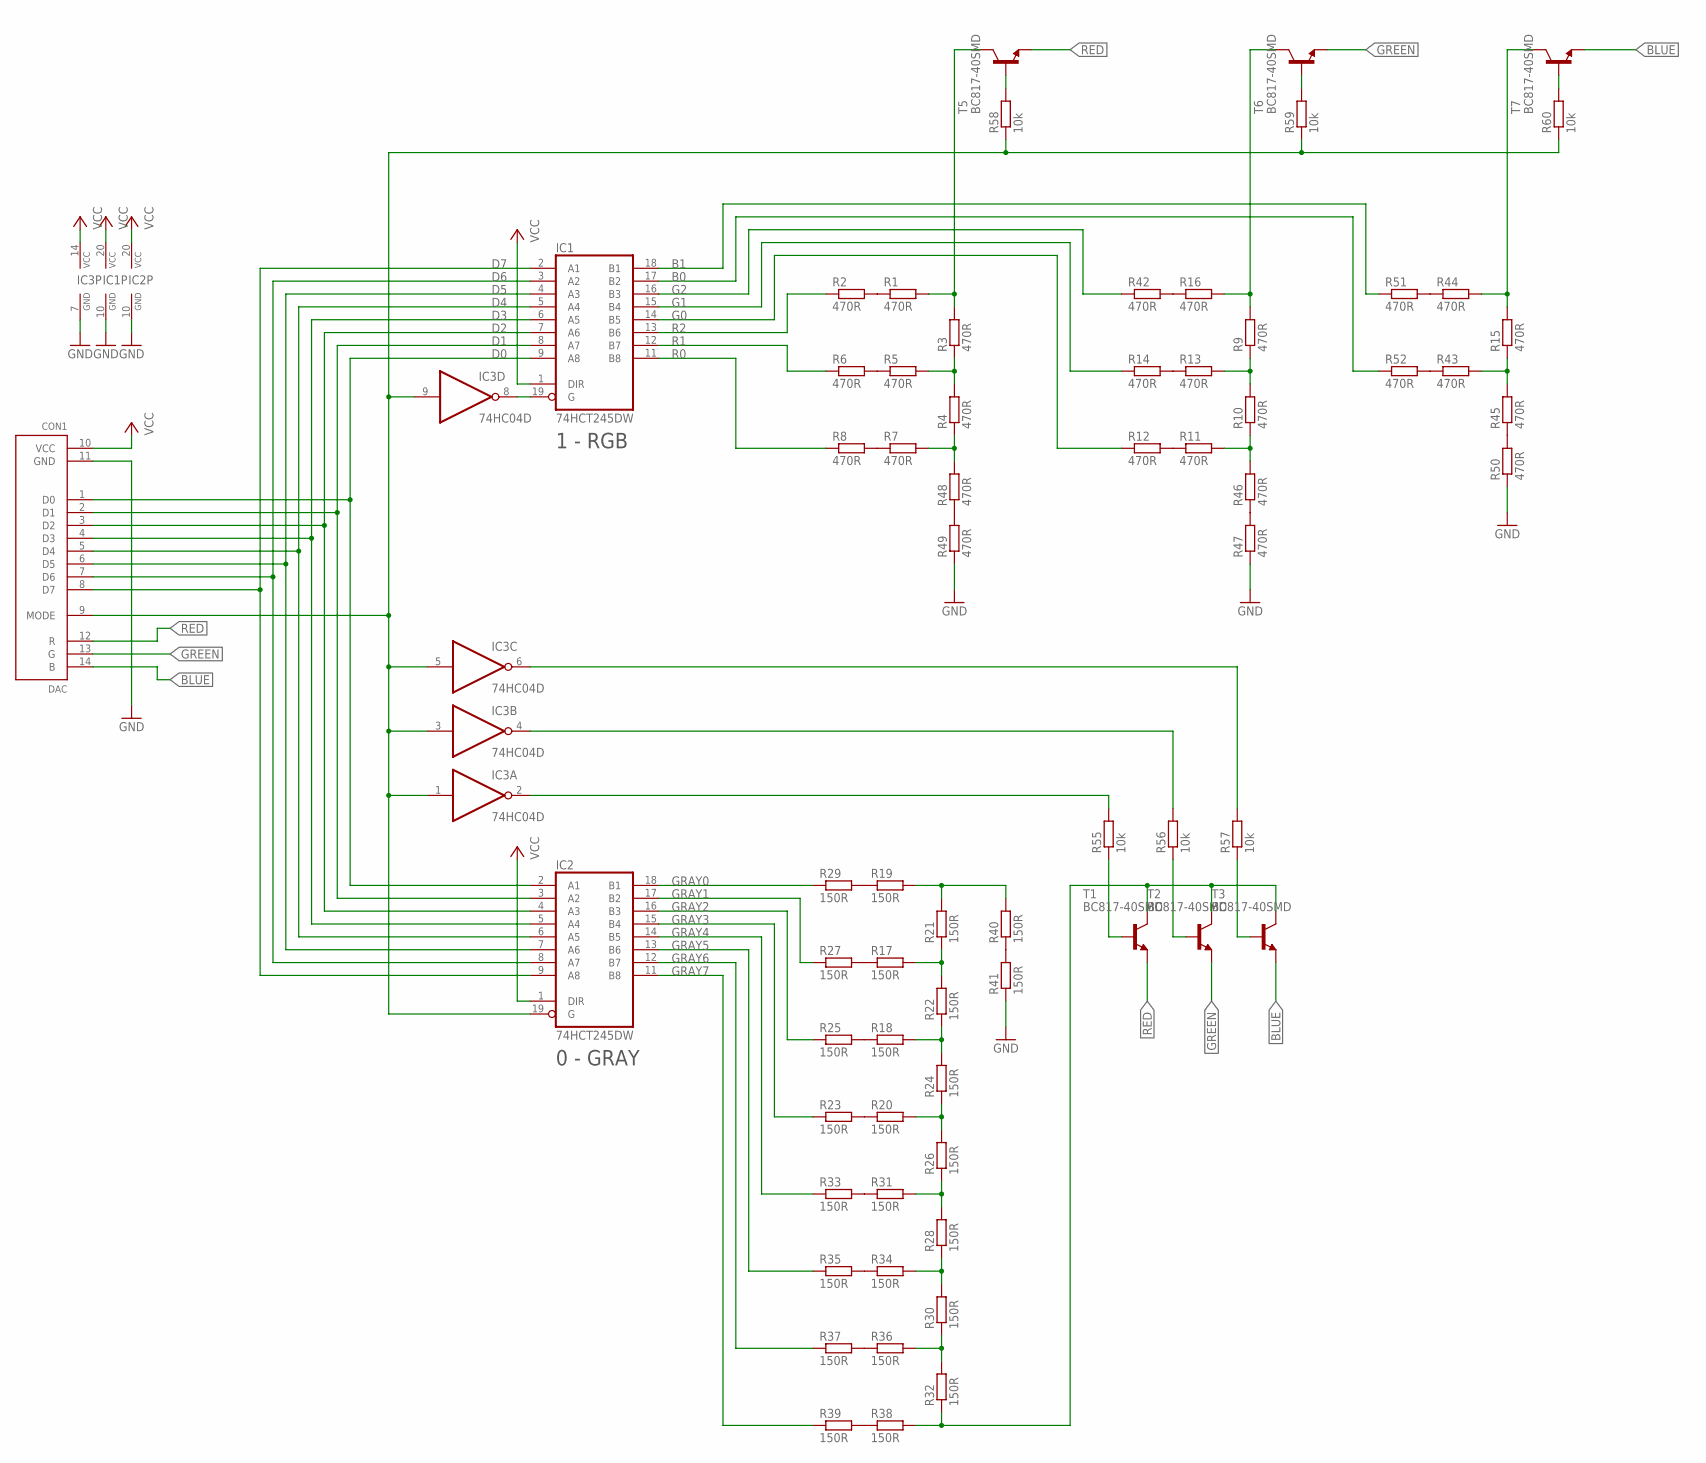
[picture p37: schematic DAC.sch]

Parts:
CON1: DAC; DAC_CON
IC1, IC2: 74HCT245DW; SO20W
IC3: 74HC04D; SO14
R1, R2, R3, R4, R5, R6, R7, R8, R9, R10, R11, R12, R13, R14, R15, R16, R42, R43, R44, R45, R46, R47, R48, R49, R50, R51, R52: 470R; R0603
R17, R18, R19, R20, R21, R22, R23, R24, R25, R26, R27, R28, R29, R30, R31, R32, R33, R34, R35, R36, R37, R38, R39, R40, R41: 150R; R0603
R55, R56, R57, R58, R59, R60: 10k; R0603
T1, T2, T3, T5, T6, T7: BC817-40SMD; SOT23-BEC

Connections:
B0: IC1.17 (B2), R52.1
B1: IC1.18 (B1), R51.1
BLUE: CON1.14 (B), T3.E, T7.E
D0: CON1.1 (D0), IC1.9 (A8), IC2.2 (A1)
D1: CON1.2 (D1), IC1.8 (A7), IC2.3 (A2)
D2: CON1.3 (D2), IC1.7 (A6), IC2.4 (A3)
D3: CON1.4 (D3), IC1.6 (A5), IC2.5 (A4)
D4: CON1.5 (D4), IC1.5 (A4), IC2.6 (A5)
D5: CON1.6 (D5), IC1.4 (A3), IC2.7 (A6)
D6: CON1.7 (D6), IC1.3 (A2), IC2.8 (A7)
D7: CON1.8 (D7), IC1.2 (A1), IC2.9 (A8)
DAC_BLUE: R15.2, R44.2, T7.C
DAC_GRAY: R32.1, R38.2, T1.C, T2.C, T3.C
DAC_GREEN: R9.2, R16.2, T6.C
DAC_RED: R1.2, R3.2, T5.C
G0: IC1.14 (B5), R12.1
G1: IC1.15 (B4), R14.1
G2: IC1.16 (B3), R42.1
GND: CON1.11 (GND), IC1.10 (GND), IC2.10 (GND), IC3.7 (GND), R41.1, R47.1, R49.1, R50.1
GRAY0: IC2.18 (B1), R29.1
GRAY1: IC2.17 (B2), R27.1
GRAY2: IC2.16 (B3), R25.1
GRAY3: IC2.15 (B4), R23.1
GRAY4: IC2.14 (B5), R33.1
GRAY5: IC2.13 (B6), R35.1
GRAY6: IC2.12 (B7), R37.1
GRAY7: IC2.11 (B8), R39.1
GREEN: CON1.13 (G), T2.E, T6.E
unnamed: R9.1, R10.2, R13.2
unnamed: R3.1, R4.2, R5.2
unnamed: R4.1, R7.2, R48.2
unnamed: R10.1, R11.2, R46.2
unnamed: R15.1, R43.2, R45.2
unnamed: R20.1, R23.2
unnamed: R17.2, R21.1, R22.2
unnamed: R18.2, R22.1, R24.2
unnamed: R20.2, R24.1, R26.2
unnamed: R26.1, R28.2, R31.2
unnamed: R28.1, R30.2, R34.2
unnamed: R30.1, R32.2, R36.2
unnamed: R18.1, R25.2
unnamed: R17.1, R27.2
unnamed: R19.1, R29.2
unnamed: R31.1, R33.2
unnamed: R34.1, R35.2
unnamed: R36.1, R37.2
unnamed: R38.1, R39.2
unnamed: R40.1, R41.2
unnamed: R1.1, R2.2
unnamed: R5.1, R6.2
unnamed: R7.1, R8.2
unnamed: R11.1, R12.2
unnamed: R13.1, R14.2
unnamed: R16.1, R42.2
unnamed: R46.1, R47.2
unnamed: R48.1, R49.2
unnamed: R45.1, R50.2
unnamed: R44.1, R51.2
unnamed: R43.1, R52.2
unnamed: R19.2, R21.2, R40.2
unnamed: IC1.19 (G), IC3.8 (O)
unnamed: IC3.2 (O), R55.2
unnamed: R58.2, T5.B
unnamed: IC3.4 (O), R56.2
unnamed: R59.2, T6.B
unnamed: R55.1, T1.B
unnamed: R56.1, T2.B
unnamed: R57.1, T3.B
unnamed: R60.2, T7.B
unnamed: CON1.9 (MODE), IC2.19 (G), IC3.1 (I), IC3.3 (I), IC3.5 (I), IC3.9 (I), R58.1, R59.1, R60.1
unnamed: IC3.6 (O), R57.2
R0: IC1.11 (B8), R8.1
R1: IC1.12 (B7), R6.1
R2: IC1.13 (B6), R2.1
RED: CON1.12 (R), T1.E, T5.E
VCC: CON1.10 (VCC), IC1.1 (DIR), IC1.20 (VCC), IC2.1 (DIR), IC2.20 (VCC), IC3.14 (VCC)

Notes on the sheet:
0 - GRAY
1 - RGB

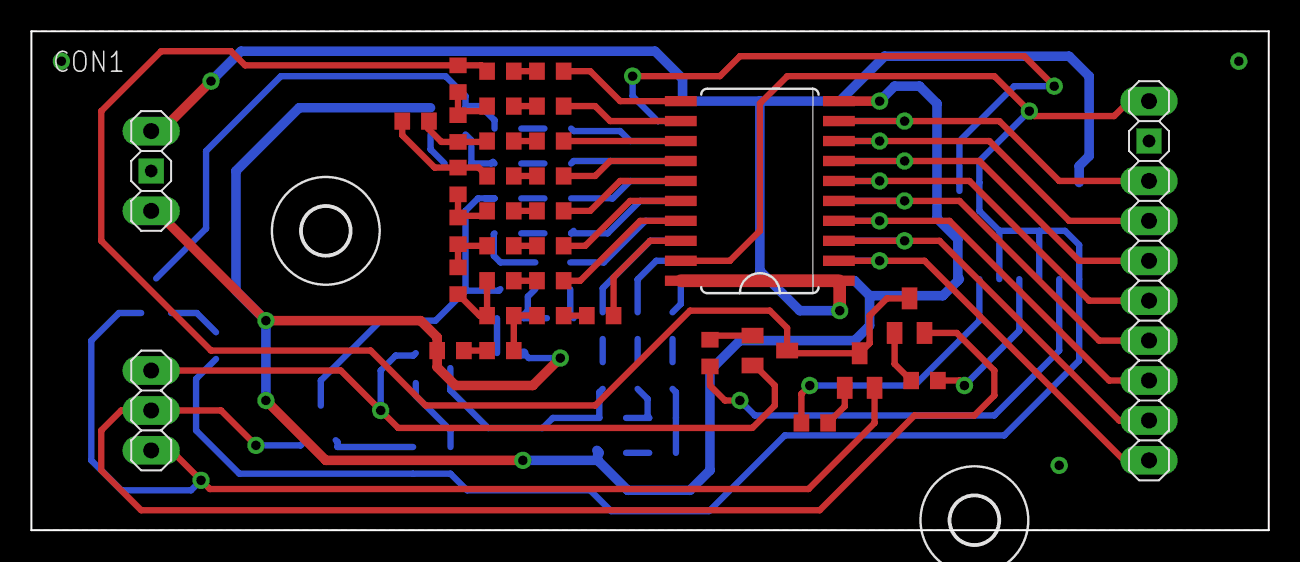
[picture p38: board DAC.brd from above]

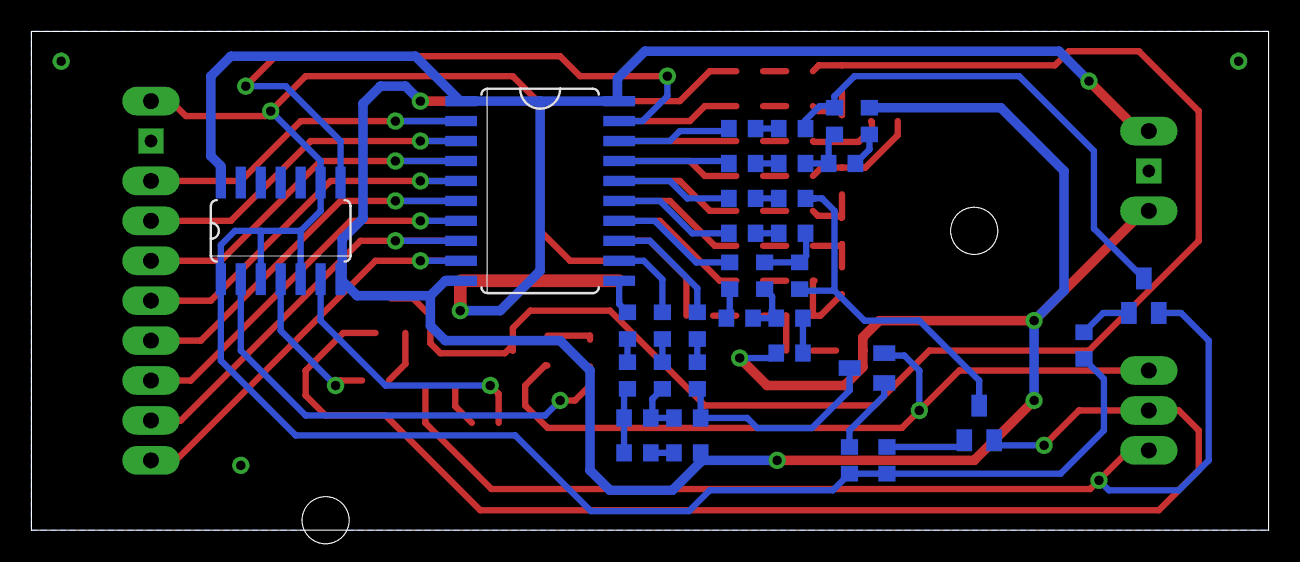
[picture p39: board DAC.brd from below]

Board: 2 copper layers, 78.7 x 31.7 mm, 70 parts (35 on the bottom side), 76 nets.

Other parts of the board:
U$1, U$2: 3,0

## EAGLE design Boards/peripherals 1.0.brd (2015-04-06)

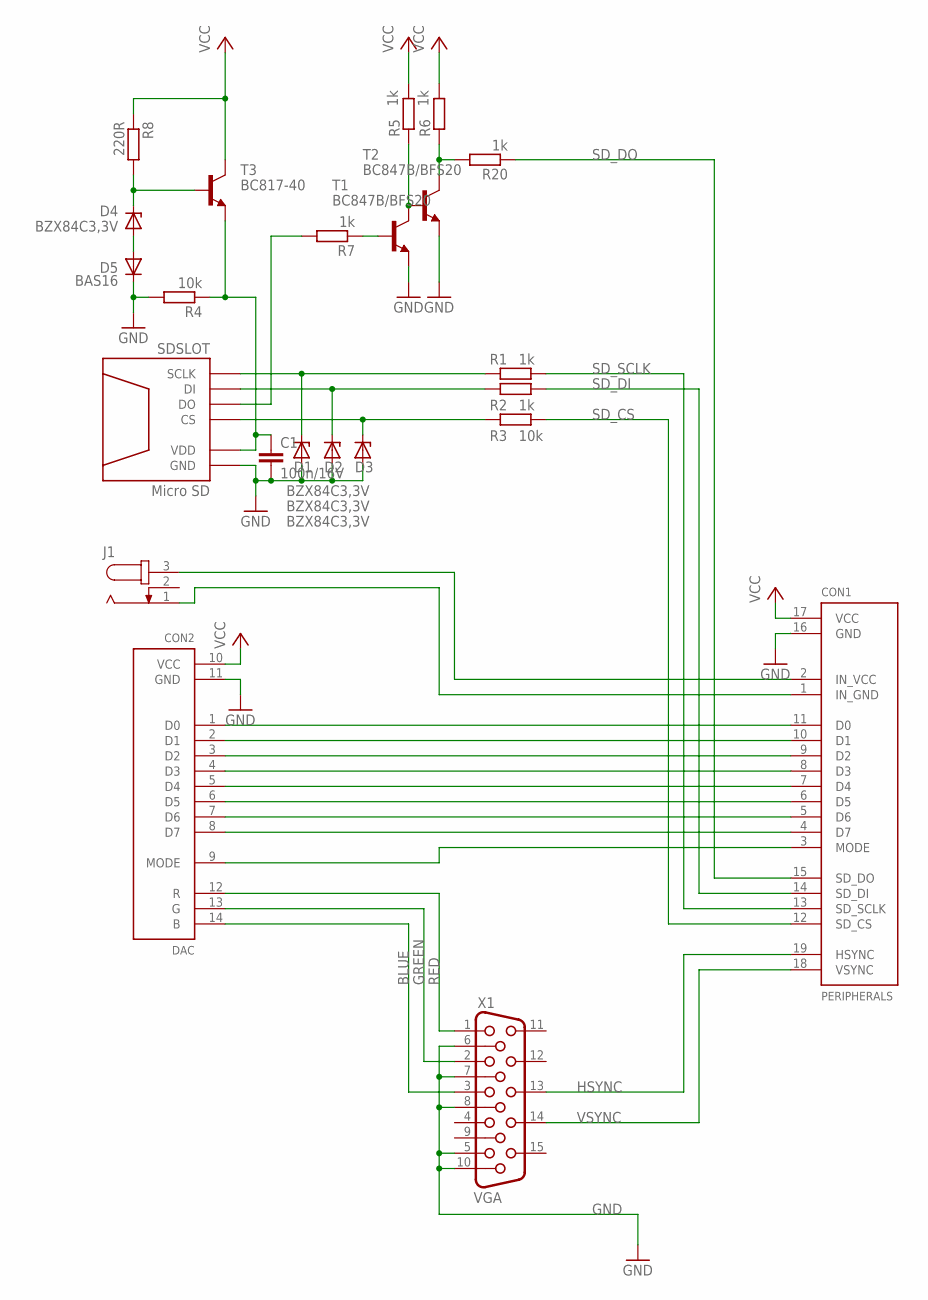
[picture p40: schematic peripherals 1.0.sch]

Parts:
C1: 100n/16V; C0603
CON1: PERIPHERALS; PERIPHERALS_CON
CON2: DAC; DAC_CON
D1, D2, D3, D4: BZX84C3,3V; SOT23
D5: BAS16; SOT23
J1: JACK-PLUG1; SPC4078
R1, R2, R5, R6, R7, R20: 1k; 0204/7
R3, R4: 10k; 0204/7
R8: 220R; R0603
SDSLOT: Micro SD; MICRO_SD_ATTEND
T1, T2: BC847B/BFS20; SOT23-BEC
T3: BC817-40; SOT23-BEC
X1: VGA; HDF15H

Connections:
BLUE: CON2.14 (B), X1.3
GND: C1.2, CON1.16 (GND), CON2.11 (GND), D1.1 (A), D2.1 (A), D3.1 (A), D5.3 (C), R4.2, SDSLOT.6 (GND), SDSLOT.CASE1 (GND), SDSLOT.CASE2 (GND), SDSLOT.CASE3 (GND), SDSLOT.CASE4 (GND), T1.E, T2.E, X1.5, X1.6, X1.7, X1.8, X1.10
GREEN: CON2.13 (G), X1.2
HSYNC: CON1.19 (HSYNC), X1.13
IN_GND: CON1.1 (IN_GND), J1.1
IN_VCC: CON1.2 (IN_VCC), J1.3
unnamed: D1.3 (C), R1.1, SDSLOT.5 (SCLK)
unnamed: D2.3 (C), R2.1, SDSLOT.3 (DI)
unnamed: D3.3 (C), R3.1, SDSLOT.2 (CS)
unnamed: D4.1 (A), D5.1 (A)
unnamed: C1.1, R4.1, SDSLOT.4 (VDD), T3.E
unnamed: D4.3 (C), R8.2, T3.B
unnamed: R6.1, R20.2, T2.C
unnamed: R7.2, SDSLOT.7 (DO)
unnamed: R5.1, T1.C, T2.B
unnamed: R7.1, T1.B
unnamed: CON1.11 (D0), CON2.1 (D0)
unnamed: CON1.10 (D1), CON2.2 (D1)
unnamed: CON1.9 (D2), CON2.3 (D2)
unnamed: CON1.8 (D3), CON2.4 (D3)
unnamed: CON1.7 (D4), CON2.5 (D4)
unnamed: CON1.6 (D5), CON2.6 (D5)
unnamed: CON1.5 (D6), CON2.7 (D6)
unnamed: CON1.4 (D7), CON2.8 (D7)
unnamed: CON1.3 (MODE), CON2.9 (MODE)
RED: CON2.12 (R), X1.1
SD_CS: CON1.12 (SD_CS), R3.2
SD_DI: CON1.14 (SD_DI), R2.2
SD_DO: CON1.15 (SD_DO), R20.1
SD_SCLK: CON1.13 (SD_SCLK), R1.2
VCC: CON1.17 (VCC), CON2.10 (VCC), R5.2, R6.2, R8.1, T3.C
VSYNC: CON1.18 (VSYNC), X1.14

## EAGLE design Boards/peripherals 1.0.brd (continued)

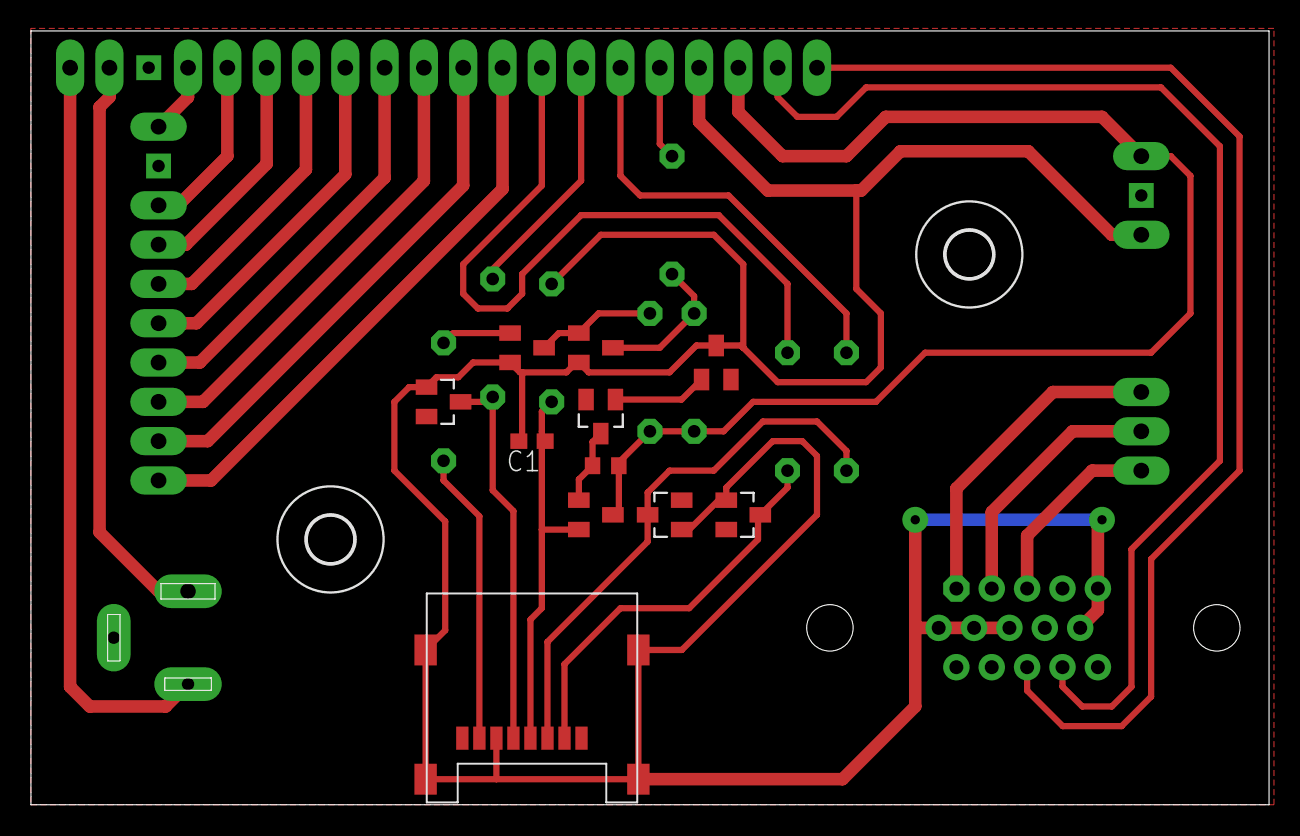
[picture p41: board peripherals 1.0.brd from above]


Board: 2 copper layers, 80.0 x 50.0 mm, 25 parts (12 on the bottom side), 32 nets.

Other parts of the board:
U$1, U$2: 3,0

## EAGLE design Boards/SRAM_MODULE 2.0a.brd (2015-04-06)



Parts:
D1, D2: D-A1-C3; SOT23
IC1, IC2: K6X1008C2D; SOP32-5
IC3, IC4, IC12: 74HC245DW; SO20W
IC5, IC6, IC7, IC9, IC15, IC16: 74HC157D; SO16
IC10, IC17, IC18, IC19: 74HCT164D; SO14
IC11: 74HC04D; SO14
JP1: Data I/O; 1X08
JP2: Video Output; 1X08
JP3: Data Control; 1X08
JP4: Video Control; 1X08
JP6: Copy Control; 1X02
JP7: Supply; 1X02
R1, R2, R3, R4, R5, R6, R7, R8, R9, R10: 10k; R0603

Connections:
A_ADDRESS_X: IC9.7 (2Y), IC10.1 (A), IC10.2 (B)
A_ADDRESS_Y: IC1.27 (A8), IC9.12 (4Y), IC17.1 (A), IC17.2 (B)
A_CLKX: IC10.8 (CLK), IC15.7 (2Y)
A_CLKY: IC16.7 (2Y), IC17.8 (CLK)
A_I/O1: IC1.13 (I/O1), IC4.18 (B1), IC6.2 (1A), IC12.9 (A8)
A_I/O2: IC1.14 (I/O2), IC4.17 (B2), IC6.5 (2A), IC12.8 (A7)
A_I/O3: IC1.15 (I/O3), IC4.16 (B3), IC6.11 (3A), IC12.7 (A6)
A_I/O4: IC1.17 (I/O4), IC4.15 (B4), IC6.14 (4A), IC12.6 (A5)
A_I/O5: IC1.18 (I/O5), IC4.14 (B5), IC5.2 (1A), IC12.5 (A4)
A_I/O6: IC1.19 (I/O6), IC4.13 (B6), IC5.5 (2A), IC12.4 (A3)
A_I/O7: IC1.20 (I/O7), IC4.12 (B7), IC5.11 (3A), IC12.3 (A2)
A_I/O8: IC1.21 (I/O8), IC4.11 (B8), IC5.14 (4A), IC12.2 (A1)
A_RESX: IC10.9 (CLR), IC15.12 (4Y)
A_RESY: IC16.12 (4Y), IC17.9 (CLR)
A_WE: IC1.29 (WE), IC7.7 (2Y)
B_ADDRESS_X: IC9.4 (1Y), IC18.1 (A), IC18.2 (B)
B_ADDRESS_Y: IC2.27 (A8), IC9.9 (3Y), IC19.1 (A), IC19.2 (B)
B_CLKX: IC15.4 (1Y), IC18.8 (CLK)
B_CLKY: IC16.4 (1Y), IC19.8 (CLK)
B_I/O1: IC2.13 (I/O1), IC3.18 (B1), IC6.3 (1B), IC12.11 (B8)
B_I/O2: IC2.14 (I/O2), IC3.17 (B2), IC6.6 (2B), IC12.12 (B7)
B_I/O3: IC2.15 (I/O3), IC3.16 (B3), IC6.10 (3B), IC12.13 (B6)
B_I/O4: IC2.17 (I/O4), IC3.15 (B4), IC6.13 (4B), IC12.14 (B5)
B_I/O5: IC2.18 (I/O5), IC3.14 (B5), IC5.3 (1B), IC12.15 (B4)
B_I/O6: IC2.19 (I/O6), IC3.13 (B6), IC5.6 (2B), IC12.16 (B3)
B_I/O7: IC2.20 (I/O7), IC3.12 (B7), IC5.10 (3B), IC12.17 (B2)
B_I/O8: IC2.21 (I/O8), IC3.11 (B8), IC5.13 (4B), IC12.18 (B1)
B_RESX: IC15.9 (3Y), IC18.9 (CLR)
B_RESY: IC16.9 (3Y), IC19.9 (CLR)
B_WE: IC2.29 (WE), IC7.4 (1Y)
COPY_DIR_DATA_TO_VIDEO_HIGH: IC7.10 (3B), IC11.3 (I), JP6.1
COPY_ENABLE_LOW: IC11.9 (I), IC12.19 (G), JP6.2
DATA_ADDRESS_X: IC9.2 (1A), IC9.6 (2B), JP3.4
DATA_ADDRESS_Y: IC9.11 (3A), IC9.13 (4B), JP3.7
DATA_CLKX: IC15.2 (1A), IC15.6 (2B), JP3.3
DATA_CLKY: IC16.2 (1A), IC16.6 (2B), JP3.6
DATA_RESX: IC15.11 (3A), IC15.13 (4B), JP3.5
DATA_RESY: IC16.11 (3A), IC16.13 (4B), JP3.8
DATA_WE: IC7.2 (1A), IC7.6 (2B), IC11.5 (I), JP3.2
GND: IC1.16 (VSS), IC1.22 (CS1), IC1.24 (OE), IC2.16 (VSS), IC2.22 (CS1), IC2.24 (OE), IC3.10 (GND), IC4.10 (GND), IC5.8 (GND), IC6.8 (GND), IC7.8 (GND), IC7.15 (G), IC9.8 (GND), IC9.15 (G), IC10.7 (GND), IC11.7 (GND), IC12.10 (GND), IC15.8 (GND), IC15.15 (G), IC16.8 (GND), IC16.15 (G), IC17.7 (GND), IC18.7 (GND), IC19.7 (GND), JP7.2
INTERNAL_COPY_DIRECTION: IC7.9 (3Y), IC12.1 (DIR)
IO1: IC3.2 (A1), IC4.2 (A1), R1.2
IO2: IC3.3 (A2), IC4.3 (A2), R2.2
IO3: IC3.4 (A3), IC4.4 (A3), R3.2
IO4: IC3.5 (A4), IC4.5 (A4), R4.2
IO5: IC3.6 (A5), IC4.6 (A5), R5.2
IO6: IC3.7 (A6), IC4.7 (A6), R6.2
IO7: IC3.8 (A7), IC4.8 (A7), R7.2
IO8: IC3.9 (A8), IC4.9 (A8), R8.2
unnamed: IC1.12 (A0), IC10.3 (QA)
unnamed: IC7.11 (3A), IC11.4 (O)
unnamed: D2.3 (C), IC3.19 (G), R10.2
unnamed: D1.3 (C), IC4.19 (G), R9.2
unnamed: IC1.11 (A1), IC10.4 (QB)
unnamed: IC1.28 (A13), IC17.10 (QE)
unnamed: IC1.10 (A2), IC10.5 (QC)
unnamed: IC1.9 (A3), IC10.6 (QD)
unnamed: IC1.8 (A4), IC10.10 (QE)
unnamed: D1.1 (A), D2.1 (A), IC11.8 (O)
unnamed: IC1.7 (A5), IC10.11 (QF)
unnamed: IC1.6 (A6), IC10.12 (QG)
unnamed: JP1.8, R8.1
unnamed: JP1.7, R7.1
unnamed: JP1.6, R6.1
unnamed: JP1.5, R5.1
unnamed: IC1.5 (A7), IC10.13 (QH)
unnamed: JP1.4, R4.1
unnamed: IC1.26 (A9), IC17.3 (QA)
unnamed: IC1.23 (A10), IC17.4 (QB)
unnamed: IC1.25 (A11), IC17.5 (QC)
unnamed: IC1.4 (A12), IC17.6 (QD)
unnamed: IC1.3 (A14), IC17.11 (QF)
unnamed: IC1.31 (A15), IC17.12 (QG)
unnamed: IC1.2 (A16), IC17.13 (QH)
unnamed: JP1.3, R3.1
unnamed: IC2.26 (A9), IC19.3 (QA)
unnamed: IC2.23 (A10), IC19.4 (QB)
unnamed: IC2.25 (A11), IC19.5 (QC)
unnamed: IC2.4 (A12), IC19.6 (QD)
unnamed: IC2.28 (A13), IC19.10 (QE)
unnamed: IC2.3 (A14), IC19.11 (QF)
unnamed: IC2.31 (A15), IC19.12 (QG)
unnamed: IC2.2 (A16), IC19.13 (QH)
unnamed: IC2.12 (A0), IC18.3 (QA)
unnamed: IC2.11 (A1), IC18.4 (QB)
unnamed: IC2.10 (A2), IC18.5 (QC)
unnamed: IC2.9 (A3), IC18.6 (QD)
unnamed: IC2.8 (A4), IC18.10 (QE)
unnamed: JP1.2, R2.1
unnamed: IC2.7 (A5), IC18.11 (QF)
unnamed: IC2.6 (A6), IC18.12 (QG)
unnamed: IC3.1 (DIR), IC4.1 (DIR), IC11.6 (O)
unnamed: IC2.5 (A7), IC18.13 (QH)
unnamed: IC11.2 (O), R9.1
unnamed: JP1.1, R1.1
O1: IC6.4 (1Y), JP2.1
O2: IC6.7 (2Y), JP2.2
O3: IC6.9 (3Y), JP2.3
O4: IC6.12 (4Y), JP2.4
O5: IC5.4 (1Y), JP2.5
O6: IC5.7 (2Y), JP2.6
O7: IC5.9 (3Y), JP2.7
O8: IC5.12 (4Y), JP2.8
SWAP: IC5.1 (!A!/B), IC6.1 (!A!/B), IC7.1 (!A!/B), IC9.1 (!A!/B), IC11.1 (I), IC15.1 (!A!/B), IC16.1 (!A!/B), JP3.1, R10.1
VCC: IC1.30 (CS2), IC1.32 (VCC), IC2.30 (CS2), IC2.32 (VCC), IC3.20 (VCC), IC4.20 (VCC), IC5.16 (VCC), IC6.16 (VCC), IC7.16 (VCC), IC9.16 (VCC), IC10.14 (VCC), IC11.14 (VCC), IC12.20 (VCC), IC15.16 (VCC), IC16.16 (VCC), IC17.14 (VCC), IC18.14 (VCC), IC19.14 (VCC), JP7.1
VIDEO_ADDRESS_X: IC9.3 (1B), IC9.5 (2A), JP4.4
VIDEO_ADDRESS_Y: IC9.10 (3B), IC9.14 (4A), JP4.7
VIDEO_CLKX: IC15.3 (1B), IC15.5 (2A), JP4.3
VIDEO_CLKY: IC16.3 (1B), IC16.5 (2A), JP4.6
VIDEO_ENABLE_LOW: IC5.15 (G), IC6.15 (G), JP4.1
VIDEO_RESX: IC15.10 (3B), IC15.14 (4A), JP4.5
VIDEO_RESY: IC16.10 (3B), IC16.14 (4A), JP4.8
VIDEO_WE: IC7.3 (1B), IC7.5 (2A), JP4.2

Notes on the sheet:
DATA I/O
VIDEO OUT
**OPTIONAL** RAM copy interface
CLKX
ADDRESS_X
RESX
CLKY
ADDRESS_Y
RESY
COPY DIR
DUAL SRAM SWAPPER V 2.0a



Board: 2 copper layers, 101.6 x 81.3 mm, 34 parts (2 on the bottom side), 113 nets.

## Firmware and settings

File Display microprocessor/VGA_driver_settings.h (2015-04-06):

/*
*	Copyright (c) 2015 Tomáš Pazdiora
*	See the file "LICENSE.txt" for the full license governing this code.
*/

#define VGADDR DDRD
#define VGAPORT PORTD
#define VGAPIN PIND

#define RXD 0 //swap_request
#define TXD 1

#define VIDEO_ENABLE 3
#define HSYNC 4
#define VSYNC 5

#define COPY_DIR 6

#define VGADDR2 DDRB
#define VGAPORT2 PORTB
#define VGAPIN2 PINB

#define ADR_Y	0
#define CLK_Y	1
#define RES_X	2
#define ADR_X	3
#define CLK_X	4

#define COPY_WRITE_ENABLE 5

#define COPY_HIGH	6

#define SWAP_OUT	7

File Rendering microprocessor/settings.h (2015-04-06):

/*
*	Copyright (c) 2015 Tomáš Pazdiora
*	See the file "LICENSE.txt" for the full license governing this code.
*/

#ifndef SETTINGS_H_
#define SETTINGS_H_

#include <avr/io.h>

//------------------Software------------------

#define width 250				//default 250
#define height 480				//default 480

#define real_width_ratio 0.75	//default 0.75
#define real_height_ratio 1		//default 1

//------------------Hardware------------------

#define F_CPU 16000000

#define CTRL_DDR DDRC
#define CTRL_PORT PORTC

#define WE 0
#define CLK_Y 1
#define ADR_Y 2
#define RES_X 3
#define CLK_X 4
#define ADR_X 5

#define DATA_DDR DDRA
#define DATA_PORT PORTA
#define DATA_PIN PINA

#define MODE_DDR DDRD
#define MODE_PORT PORTD
#define MODE_PIN PIND

#define MODE 2

#define UART_DDR DDRD
#define UART_PORT PORTD
#define UART_PIN PIND

#define RXD 0
#define TXD 1

#define SPI_DDR DDRB
#define SPI_PORT PORTB
#define SPI_PIN PINB

#define MISO 6
#define MOSI 5
#define SCK 7
#define CS 4

#define TOUCH_DDR DDRD
#define TOUCH_PORT PORTD
#define TOUCH_PIN PIND

#define TOUCH_SUPPLY 5
#define TOUCH_INPUT 6

//------------------Functions-----------------

#define RGB 1
#define BW 0

void set_color_mode(unsigned char color_mode);
unsigned char get_color_mode();
unsigned char informative_color();

//--------------------------------------------
#endif /* SETTINGS_H_ */

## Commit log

2015-04-07 fixup! variable name correction
    [SD.c]
2015-04-09 Added information about fuses
2015-04-12 added pdf versions of schematics
2015-04-12 added info about viewing boards
